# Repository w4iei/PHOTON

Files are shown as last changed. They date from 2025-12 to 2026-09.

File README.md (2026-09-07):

# PHOTON
**PHysical Optical Tracking of Notes system**

PHOTON is a modular, open-source optical sensing platform for high-resolution key and motion tracking. Each module combines a KiCad-designed linear array of **VCNT2025X01** reflective sensors, **TLA2518** high-speed SPI ADCs, and an **RP2350** MCU. Modules can run standalone over USB-C or daisy-chain over RS-485 for large sensing surfaces.

## Paper
[PHOTON: Non-Invasive Optical Tracking of Key-Lever Motion in Historical Keyboard Instruments](https://arxiv.org/abs/2604.21682) (arXiv:2604.21682)

## Demo
<a href="https://www.youtube.com/playlist?list=PLzCRAfVYuoWGEnWNO6l8IuFvaSUI3v1Gd">
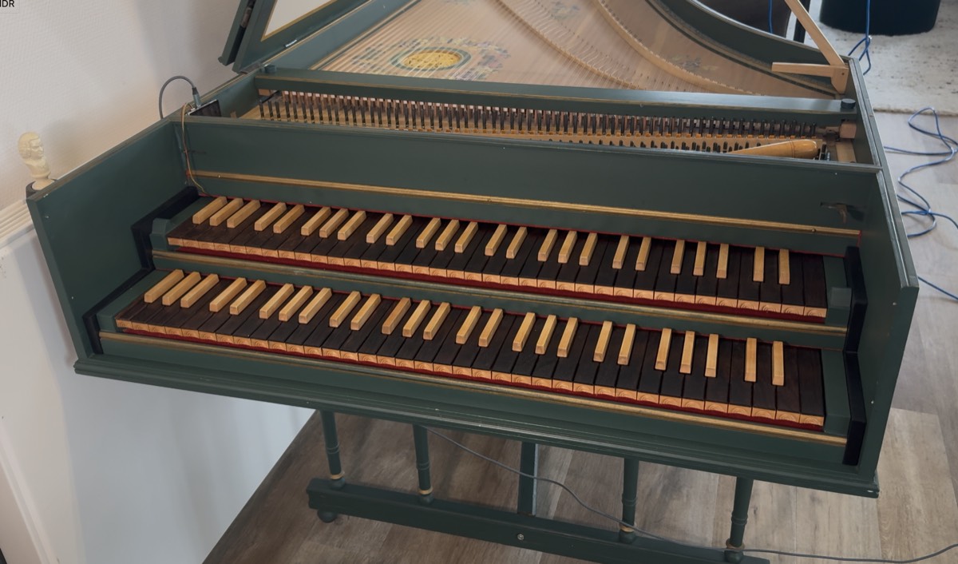
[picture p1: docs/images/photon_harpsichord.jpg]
PHOTON demo playlist thumbnail
  
</a>

[Watch the PHOTON demo playlist on YouTube](https://www.youtube.com/playlist?list=PLzCRAfVYuoWGEnWNO6l8IuFvaSUI3v1Gd)

## Highlights
- **Sensors:** [VCNT2025X01](https://www.vishay.com/en/product/84895/) reflective array with per-sensor enable lines
- **Digitization:** [TLA2518](https://www.ti.com/product/TLA2518) SPI ADCs for high-speed readout
- **MCU:** [RP2350](https://www.raspberrypi.com/products/rp2350/) (dual-core Cortex-M33)
- **Comms:** [THVD1424](https://www.ti.com/product/THVD1424) RS-485 transceivers; firmware-controlled termination on the main board (idle-bus failsafe via the transceiver's internal receiver thresholds on this hardware rev)
- **I/O:** USB-C (power + USB-MIDI/CDC), QWIIC/I2C expansion
- **Black box:** a microSD card in the bridge records every performance as Standard MIDI Files, host or no host (see [firmware/README.md](firmware/README.md#microsd-recorder-bridge))
- **Open:** KiCad 9 hardware, native C firmware (Pico SDK)

## Performance
- Full 31-sensor board sweep in ~770 µs — ~1.3 kHz open-loop; production runs two-phase, pace-throttled at 600 Hz (half the peak emitter current, 1.67 ms velocity quantisation) with µs-resolution velocity timing either way
- RS-485 bus at 4 Mbaud, bridge-polled: zero collisions by construction, zero event loss across ~500k sequence-accounted bench events, sub-ms worst-case event latency with four boards on the bus

## Firmware (native C, dual-core)
CircuitPython support is gone: it capped the system at a ~250 Hz single-core scan loop and could not prevent bus collisions, so it was retired for performance. The native Pico-SDK firmware ships as **one UF2 for every board** — each board probes its own hardware at boot and becomes a sensor node or the main bridge automatically:
- **Core 1** owns the sensor array: pipelined TLA2518 scanning, running entirely from SRAM so flash and USB activity can never stall a sweep.
- **Core 0** owns everything else: USB (CDC console + USB-MIDI), the RS-485 protocol, calibration and configuration storage.
- **RS-485:** one board is the sole bus master — the main board, or with `master on` the sensor board that carries the USB cable — and polls each sensor board in turn; nodes never transmit unsolicited, and every event batch is acknowledged before a node releases it — collision-free and lossless by design.
- **Scanning:** free-runs open-loop at ~1.3 kHz; throttled to a paced 600 Hz (two-phase mode) for production use.
- **microSD recorder:** a card in the bridge records every performance automatically as Standard MIDI Files, numbered per power-on and per playing episode, with no host, no setup and no clock required.

Build and flash instructions: `firmware/README.md`.

## Architecture (Short)
- Sensor boards: VCNT2025X01 array -> TLA2518 SPI ADCs -> RP2350
- Main board: RP2350 + THVD1424 RS-485 + bias resistors + termination control
- Bus: RS-485 differential, terminated at endpoints

## Hardware
See `hardware/README.md` for board-specific notes and layout sources.

## Getting Started
**Hardware**
- PHOTON module(s)
- USB-C cable
- JST-SH 4-pin cables (1.0 mm pitch, "reverse double head" type as used by Qwiic; see `hardware/README.md`)
- Mounting screws: **M2.3 x 5 mm pan head**, through the boards' 2.7 mm (M2.5) holes; at least three per board over 250 mm long, one at each end and one near the middle (see [hardware/README.md](hardware/README.md#design-recommendations))

**Software**
- PHOTON firmware UF2 (build from `firmware/`, see `firmware/README.md`)
- KiCad 9 (download: https://www.kicad.org/download/)
- DAW or MIDI viewer (Pianoteq, Ableton Live, Reaper, Max/MSP, etc.)

## Build & Flash
1. Hold **USB-BOOT** (or short the USB-BOOT jumper) and connect via USB-C; copy `photon.uf2` to the mounted `RP2350` drive. The same image runs every board.
2. On each sensor board, set its bus id once via the USB console (`setid N`); in an instrument without a main board, also `master on` on each (see `firmware/README.md`).
3. Calibrate. Two ways:
   - **One board, on its own USB console:** `r` clears that board's table and starts learning; play every key it covers once, one at a time, with a normal full stroke; `s` freezes the table and saves it (`x` aborts without saving).
   - **The whole instrument, from the bridge console:** `cal reset` clears every sensor board and starts learning on all of them; play every key on every manual; `cal save` then stores each board's table in its own flash. To redo a single board without disturbing the others, give its bus id: `cal reset <id>`, play that board's keys, `cal save <id>`.

   Calibration and configuration persist in flash and survive reflashing; only `cal reset`, `r` and `setid` clear them.
4. Boards already running PHOTON reflash over USB alone: the `bootsel` console command enters the bootloader without touching the button.

## Notes
- **Double-manual harpsichords** run on a single bus: each manual is a pair of sensor boards mapped to its own MIDI channel (`chmap` console command). The polled protocol eliminates inter-board collisions, so simultaneous playing on both manuals loses nothing.

## Citation
```bibtex
@inproceedings{photon2026,
  title       = {PHOTON: Non-Invasive Optical Tracking of Key-Lever Motion in Historical Keyboard Instruments},
  author      = {Noah Jaffe and John Ashley Burgoyne},
  booktitle   = {Proceedings of the 2026 International Conference on New Interfaces for Musical Expression (NIME)},
  year        = {2026},
  address     = {London, UK},
  note        = {23--26 June 2026. Preprint: arXiv:2604.21682},
  url         = {https://arxiv.org/abs/2604.21682},
}
```

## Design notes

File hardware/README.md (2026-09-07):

## Hardware Overview

KiCad sources for the PHOTON boards. Three designs, all sharing one symbol
library (`PHOTON.kicad_sym`, `PHOTON_Modified.kicad_sym`) and one footprint
library (`photon_common.pretty`) at the top of `hardware/kicad/`.

| Board | Size | Role |
|---|---|---|
| `002_sensor_board` | 413.7 x 35.0 mm | Sensor node — 31 optical sensors |
| `001d_..._low_profile` | 54.0 x 41.7 mm | Bridge, low cost / low profile |
| `001_main_controller_board` | 69.0 x 49.9 mm | Bridge, full size, touchscreen |

### Datasheets

- [VCNT2025X01](https://www.vishay.com/docs/84895/vcnt2025x01.pdf) — reflective optical sensor (Vishay)
- [TLA2518](https://www.ti.com/lit/ds/symlink/tla2518.pdf) — 8-channel SPI ADC (TI)
- [RP2350 / RP2354](https://datasheets.raspberrypi.com/rp2350/rp2350-datasheet.pdf) — microcontroller (Raspberry Pi); the RP2354 is the RP2350 with 2 MB of flash in the package, same datasheet
- [THVD1424](https://www.ti.com/lit/ds/symlink/thvd1424.pdf) — RS-485 transceiver (TI)
- [TPS62A0569A](https://www.ti.com/lit/gpn/tps62a0569a) — buck regulator (TI)
- [Waveshare 2.8" capacitive touch LCD](https://www.waveshare.com/wiki/2.8inch_Capacitive_Touch_LCD) — ST7789T3 display controller, CST328 touch controller; the reference panel for the 001 bridge

## 002 — Sensor node

31 VCNT2025X01 reflective sensors on a **13.3 mm pitch**, read by eight
TLA2518 8-channel ADCs, scanned by an RP2354. One board covers 31 notes, so
**two boards cover a 56-62 key manual** and four cover a double-manual
instrument.

This example is dimensioned for 13.3 mm, measured at either sensing point —
under the **jack** or under the **key lever**. **Every harpsichord is
different.** Measure your own instrument and validate the fit before ordering
boards.

**The board is designed to be shortened.** Mousebite perforations
(`photon_common:mousebite_34mm`) let you snap or cut sections off with
scissors to fit a shorter compass or an awkward case. Signals are routed
*through* the mousebite regions — sensor enables, ADC inputs, VCC and GND —
so a cut section stays functional up to the break.

## 001D — Bridge, low profile

RP2354 (2 MB internal flash), USB-C to the host, THVD1424 to the sensor bus,
microSD. Minimal part count and the smallest board that does the job. This is
the default bridge.

## 001 — Bridge, full size

Same role, plus an **18-pin 0.5 mm FPC connector (FH34SRJ-18S-0.5SH)** for a
touchscreen — the reference panel is a Waveshare 2.8" 240x320, ST7789T3 over
SPI with a CST328 capacitive touch controller over I2C. Carries RP2350 with
external W25Q128 flash and an APS6404L PSRAM, plus one VCNT2025X01 fitted for
bench work. Use this only if the application wants a local display.

## No bridge at all

**Neither bridge board is required.** A sensor node has its own USB-C
receptacle, so running a USB-C cable from one sensor board straight to the
host is a complete system. Several sensor boards work the same way once each
has `master on` saved: the board carrying the USB cable runs the bus for the
others (see
[firmware/README.md](../firmware/README.md#without-a-main-controller-board)).
The bridge exists for installations that want the host connection somewhere
other than at a sensor board, or that want a touchscreen and the microSD
recorder.

In practice a bridge is often the easier build. Once the sensor boards are
mounted under the keys or jacks, their USB-C receptacles tend to end up
somewhere a USB-C plug cannot reach or cannot exit the case from. The
inter-board lead is a thin 4-pin JST-SH cable that bends around anything, so
the bridge — and with it the USB-C socket and the microSD slot — can sit
wherever the host connection is convenient. The cable type is specified under
[Power](#power).

## Power

**The RS-485 cable carries 5 V.** Every board — sensor node and bridge alike —
regulates its own 3.3 V locally with a TPS62A0569ADRLR buck. Nets are just
`+5V` and `+3V3`; there is no shared 3.3 V rail between boards.

Inter-board cable, 4-pin JST-SH:

| Pin | Net |
|---|---|
| 1 | GND |
| 2 | +5V |
| 3 | RS485_P |
| 4 | RS485_N |

Use a 4-pin JST-SH (1.0 mm pitch) **"reverse double head"** cable — the same
lead Qwiic uses. Check it before plugging in: hold both plugs facing you in
the same orientation and the top-left wire colour must be the same on both.
[Example listing](https://nl.aliexpress.com/item/1005011775162638.html).

Feedback divider is 0.6 V x (1 + 450k/100k) = 3.3 V.

### One host at a time

Every board's USB-C VBUS sits on the same `+5V` net as its RS-485 connectors,
so the whole chain shares one 5 V rail. Powering any single board over USB
powers every board on the bus — which is what makes an instrument without a
main controller board work (`master on` on every sensor board; the one with
the USB cable runs the bus, see
[firmware/README.md](../firmware/README.md#without-a-main-controller-board)).

**Do not plug two boards into two different computers at once.** That ties both
hosts' 5 V supplies together through the cable. One USB connection to the
system at a time.

### Budget

The whole four-board system draws **~210 mA at 5 V (1.08 W)** while
scanning at the production settings, i.e. roughly 60 mA at 3.3 V per board:
the RP2350 at 150 MHz and eight always-on TLA2518s. Emitters are pulsed at a
few percent duty and cost ~0.1 W per 100 Hz of scan rate; peak current
depends on scan mode (up to four lit at once in two-phase, ~27 mA each, or
eight in parallel).

COUT is **22 uF**, the value the TPS62A0569A datasheet rates highest with a
1 uH inductor. Do not add distributed bulk on +3V3 to "help" — it parallels
COUT and slows the loop, which costs more than the droop it removes.

### Rail sensitivity

The detector is a 4.7 kOhm pull-up to +3V3 with the ADC referenced to the same
rail, so the dark reading is ratiometric and only the LED's forward-voltage
offset leaks through: **~1.9% of signal per 100 mV of droop**, about 130 counts
on a 6,900-count range against a ~62-count noise floor. Keep emitter-correlated
droop under ~50 mV and it is invisible.

Do not filter AVDD away from the pull-up rail — that breaks the cancellation
and roughly triples the sensitivity.

## Building a sensor board for your instrument

1. Update the schematic so the sensor and bank counts match your instrument.
   The final sensor bank is **not** inherited from the four-sensor bank — edit
   it explicitly.
2. Resize the board outline, copper fills and edge cuts.
3. Run the sensor placement script to set the pitch.
4. Route the first bank and the last bank.
5. Replicate that routing across the middle banks, then clean up and verify by
   hand.

Manual review is required after replication and before fabrication.

## Required KiCad plugins

Both via the Plugin and Content Manager:

- **Replicate Layout** — step 5 above
- **Fabrication Toolkit** — generates the `production/` outputs

## Design recommendations

For a board over 250 mm long, use at least **three M2.5 mounting holes** — one at each
end and one near the middle. The centre screw stops the board bowing away from
the mounting surface. Fit them in a line, not both ends first. Putty is fine
for a temporary setup; screws keep the boards from shifting when the
instrument is moved.

Mounting holes use `photon_common:MountingHole_2.7mm_M2.5_Keepout`, which
carries a 7 mm copper keepout so a screw head cannot bridge the top pour to
the bottom pour.

Recommended screws: **M2.3 x 5 mm pan head**
([example listing](https://nl.aliexpress.com/item/33043885403.html)). They
pass through the 2.7 mm holes with clearance.

## Disclaimer

No warranty is provided. Users create circuit boards at their own risk.

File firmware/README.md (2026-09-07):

# PHOTON Native Firmware

Bare-metal C (Pico SDK) firmware for all PHOTON boards. One UF2 for every
board: at boot the firmware probes the
TLA2518 banks; a board with sensors becomes a **sensor node** (core 1 runs the
SRAM-resident scan/event loop), a board without (the main controller board)
becomes the **bus master/bridge** (RS-485 poll cycle + USB-MIDI + console).
An instrument can also be built from sensor boards alone: with `master on`
(saved) on each board, whichever carries the USB cable runs the bus as well,
see [Without a main controller board](#without-a-main-controller-board).

Design details: [docs/architecture/01-native-dual-core-firmware.md](../docs/architecture/01-native-dual-core-firmware.md).

## Build

Requirements: `arm-none-eabi-gcc`, `cmake`, `ninja`, `picotool` ≥ 2.3
(all in Homebrew), and a pico-sdk ≥ 2.1 checkout with the `lib/tinyusb`
submodule initialized:

```bash
git clone --depth 1 --branch 2.3.0 https://github.com/raspberrypi/pico-sdk.git ~/pico-sdk
git -C ~/pico-sdk submodule update --init --depth 1 lib/tinyusb
```

Then:

```bash
cd firmware
cmake -B build -G Ninja        # set -DPICO_SDK_PATH=... if not ~/pico-sdk
ninja -C build                 # -> build/photon.uf2
```

The image is built **copy-to-RAM**: all code executes from SRAM, so core-0
flash writes (calibration saves) can never stall the core-1 scan loop.

## Flash / update

First time (blank board): hold **USB-BOOT** while connecting USB-C (or short
the USB-BOOT jumper), then:

```bash
picotool load -f build/photon.uf2 && picotool reboot
```

or copy `photon.uf2` onto the `RP2350` drive.

Updating a running board never needs the button: type `bootsel` on its
console (or `bootsel <id>` from the bridge for a remote node), then run the
same `picotool` line. `tools/flash_all.sh` does this for the whole system.

**Everything configured survives a reflash**: node id, calibration, disabled
masks, channel map, scan mode/rate, velocity range. Config lives in two
sectors above the program image, which a UF2 drop does not touch, and the
loader accepts records written by any older build (fields are append-only,
so an old record is a prefix of the current one; missing fields take
defaults). A migrated board says so once in its boot banner and `id`, then
rewrites the record in the current layout. Check with `disable` (no
argument, lists the masks), `chmap` and `velrange` after flashing. The only
way to lose settings is `cal reset` / `setid`.

## Validated settings

These are the compiled defaults, measured on the four-board two-manual
instrument (2026-09-02). Every one is also a runtime knob, persisted in
flash.

| setting | value | why |
|---|---|---|
| scan mode | 2, two-phase (`mode`) | half the peak emitter current of parallel, 8-key spacing between lit emitters |
| scan rate | 600 Hz (`rate`) | 1.67 ms velocity quantisation, 55 steps across the playing range; sweep 969 µs so ~40% idle |
| emitter settle | 50 µs (`settle`) | more changes nothing measurable |
| SPI bus | 10 MHz | faster clocks lose register writes to the ADC nearest the MCU (near-end reflection on the 414 mm board) |
| velocity map | log in dt, 2.5–25 ms → 50–120, gamma 2 (`velcurve`, `velrange`) | pp / mf-f / ff strikes measure 24.9 / 9.9 / 3.3 ms median, a constant ratio apart; lands them at 54 / 95 / 119 |
| system power | 1.08 W at 5 V, all four boards | measured at the USB meter; mode and rate move it by ~0.1 W per 100 Hz only |

Mode 0 (sequential, ~390 Hz ceiling) lights one emitter at a time and is
kept only as a crosstalk-free benchmarking reference.

One hardware quirk the driver works around: on every TLA2518 fitted, GPIO0
in push-pull mode drives high regardless of GPO_VALUE, so the slot-3
emitter of each bank is switched through its drive-mode bit instead
(`tla2518_emitters()`). Any board flashed with an older build had those
seven emitters on continuously and must be recalibrated after updating.

## Debugging (USB-only)

The current boards have no SWD connector populated, so **the USB console is
the debugging interface**: `stats` (rates, counters, error tallies), `data`/
`minmax` (live sensor state), `trace`/`capture` (per-sweep waveforms, local
or via the bridge with `trace <sensor> <node>`; `tools/listen_for_single_sensor_high_res.py`
captures and plots them on the host), `flashtest`
(core-1 independence proof), plus the `# LOG`/`# NOTE` diagnostic stream. A
sensor node whose array reads all-zero at boot deliberately *suppresses* its
auto-reboot recovery while a console is attached, so the fault can be
inspected instead of loop-rebooting. (If SWD headers are ever soldered on,
standard OpenOCD + Debug Probe works: `openocd -f interface/cmsis-dap.cfg -f
target/rp2350.cfg`.)

## First-time setup per sensor node

Each sensor node needs a bus id once. Connect USB to the node and in a
serial terminal (115200, any rate — CDC):

```
setid 1        # 1..6, unique per node
```

then calibrate at the operating scan rate: `r`, play every key once at normal
force, `s`. The same can be done for the whole bus from the bridge console:
`cal reset` clears every node and starts learning, play every key on every
manual, `cal save` stores each node's table; `cal reset <id>` / `cal save
<id>` target one node and leave the others alone. Id and calibration persist
in flash. On the bridge, `chmap <manual> <channel>` maps each manual (board
pair) to its MIDI channel and `disable <global idx>` masks unpopulated slots
on remote boards.

## Without a main controller board

Two sensor boards make a whole single-manual instrument on their own. Cable
them together on RS-485 (termination switches on at both ends), give them
ids 1 and 2, and on each board's console once:

```
master on      # saved
```

From then on whichever board carries the USB cable runs the bus: about a
second after the host has enumerated it, having heard nothing on the wire,
it starts polling the other board and owns USB-MIDI and the console exactly
as the main controller board would (`id` says `role=master+node`). Its own
keys stay in the note map under its node id, so node 1 is always the low
half of the manual and node 2 the high half, whichever of them has the
cable. The chain is powered through that cable, so moving it power-cycles
both boards and the roles follow it. A `master on` board that does hear a
master (the other board already running the bus, or a main controller board)
stays a plain node. Every bridge-form command works from the master. `data`, `minmax` and `trace` read
the local scanner when the id is omitted or is the board's own, and a remote
node otherwise; the bus-wide forms of `cal`, `mode`, `rate`, `settle`,
`burst` and `test` (no id) reach every node and the local scanner alike;
`disable`/`enable` take global sensor indexes, as on the bridge. `nodes`
lists the board itself first. A sensor board has no microSD socket, so
nothing is recorded in this configuration.

Never put `master on` boards on the same bus as a main controller board: a
board with a USB host would claim the bus while the main board is still
booting, and two masters collide. A master that hears frames from bus
address 0 logs a warning once and counts them in `stats`
(`other_master_frames`). `master off` returns a board to a plain node at
the next power-up.

## Console

Any node's USB-C gives a console (`screen /dev/tty.usbmodem* 115200`).
`help` lists commands: `stats`, `nodes`, `data`, `minmax`, `ping`, `trace`,
`capture`, `burst`, `test` (pseudorandom load), `cal save|reset`, `r`/`s`/`x`
(calibration), `mode`, `rate`, `localmidi`, `master`, `chmap`,
`disable`/`enable`, `velrange`, `velcurve`, `setid`, `log on|off`,
`flashtest`, `sd`, `reboot`, `bootsel`, `id`.
The banner and `id` name the build: git short hash (`-dirty` when `firmware/`
had uncommitted changes) and build time, from a `build_id.h` that CMake
regenerates on every build. `picotool info -a build/photon.uf2`, or a board
sitting in BOOTSEL, shows the same as *version* / *build date*, next to the
repository and klavecimbel.com.
USB-MIDI appears as "PHOTON Node" and emits notes when connected to the
board that runs the bus (the main controller board, or a `master on` sensor
board).

## microSD recorder (bridge)

Put a microSD card in the main controller board's socket and forget about
it: everything the bridge emits as MIDI is also written to the card as
Standard MIDI Files, whether or not a host is listening.

```
0001/            one directory per power-on, created on the first note
0001/0001.MID    one file per playing episode
0001/0002.MID    ... opened on the first note, closed after 30 s of silence
0002/            next power-on
```

- **Numbering is the only bookkeeping.** At mount the bridge scans the root
  for the highest `NNNN` directory and continues from there. Directories are
  created lazily, so idle power cycles leave nothing behind. At 9999
  (directories or files) the recorder stops; it never wraps or overwrites.
- **No clock, no dates.** The board has no RTC and USB carries no time, so
  every file opens with a text meta event `PHOTON power-on +HH:MM:SS.mmm`
  (time since power-on). Inside a file the delta times are exact
  milliseconds (SMPTE 25 fps × 40 ticks division), no tempo map.
- **Power-cut safe.** Every 500 ms the pending events are written and the
  file is re-terminated (end-of-track plus the real track length), so the
  card always holds a complete, valid file. A yanked cable loses at most the
  last half second.
- **A held key delays the close.** The 30 s silence close waits for every
  note to be released, capped at 5 minutes.
- **Cards:** FAT16, FAT32 and exFAT (a 64 GB card as sold). No card, a
  pulled card, or a card error just means a retry every 2 s; nothing
  else on the bridge notices.
- **Latency:** the recorder runs on the bridge's otherwise idle core 1 with
  its own SPI bus (SPI1: SCK 10, MOSI 11, MISO 12, CS 13), so card stalls
  never touch the RS-485 poll cycle or USB-MIDI. Core 0 hands over messages
  through a 512-deep ring (`drops` in the status line counts overflow).

Console: `sd` prints the status line (state, card size and free space,
current directory/file, counters, last error); `sd test [n]` plays a scale
through the MIDI output on a bare bridge so the recorder can be exercised
without sensor boards. A connected terminal also gets one line per state
change (`[SD] recording 0001/0003.MID`, `[SD] closed ...`, `[SD] no card`).

## Bench verification (M1–M5): results

All five milestones passed on the real four-board, two-manual system.

**M1 — SRAM residency.** `flashtest` hammers flash 10× while core 1 scans:
sweep timing stays flat. Verified.

**M2 — scan rate.** Full 31-sensor sweep measured at 766 µs in parallel
mode (mode 1) and 969 µs two-phase (mode 2, the default) at the validated
10 MHz SPI clock; production paces mode 2 at 600 Hz (`rate`), which also
sets the calibration operating point. Verified.

**M3 — transport soak.** Bus tuned to 4 Mbaud / 8 µs DE guards / 700 µs poll
timeout: 3,694 polls/s per node (2 nodes), ~1,540/s (4 nodes). 21-minute soak
at 100 ev/s/node: 246k events, 7.2M frames, crc_err=0 gaps=0 dup=0; 500
ev/s/node × 60 s equally clean. Verified.

**M4 — end-to-end MIDI.** Four boards through the bridge into a DAW, top
manual on channel 3, lower on channel 2 (`chmap`); calibration survives power
cycles. Verified.

**M5 — chord-burst regression (the motivating bug).** Generator loads far
beyond human playing rates show zero sequence-accounted loss; real two-hand
block chords on the instrument: every note present. Verified.

To re-run any of these, the commands above (`flashtest`, `stats`, `test`,
`nodes`, `cal save`) reproduce the numbers from the bridge console alone.

## Host unit tests (no hardware)

```bash
cd firmware/test/host
cmake -B build -G Ninja && ninja -C build && ctest --test-dir build
```

Covers: frame codec (CRC vectors, roundtrip, per-byte corruption rejection,
streaming fuzz with 100% recovery), the event engine (dt math, hysteresis,
range gate, boot-disable), and the microSD recorder (the production
recorder + FatFs on a RAM disk formatted FAT16/FAT32/exFAT: numbering across
power cycles, flush validity, silence close, held-note cap, ring overflow,
card errors, late card insert, the 9999 stop) under ASan/UBSan.

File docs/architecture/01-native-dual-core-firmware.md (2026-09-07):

# PHOTON Native Dual-Core Firmware

Status: **shipped** — this is the production firmware.
Scope: replaces the CircuitPython stack with bare-metal C (Pico SDK) on the existing boards —
sensor board 002 (RS-485 half duplex) and main controller board 001. No hardware changes.

## 1. Why

Two problems drive this rewrite:

1. **Note loss under load (the motivating bug).** With two sensor boards on one manual, fast
   two-hand block chords drop notes. Cause: both nodes push EVENT frames unsolicited on the
   shared half-duplex RS-485 bus; pushes collide with each other and with the host's ACKs, and
   the stop-and-wait retry scheme (12 ms ACK timeout, 4 retries, 64-deep queue) exhausts or
   overflows during bursts. Loss is silent.
2. **Performance ceiling.** CircuitPython owns the main loop on core 0 and core 1 is idle. A full
   ~30-sensor sweep runs ≈250 Hz, and note-velocity timing (`dt`) is quantized to 1 ms — a
   ±12 % velocity error on fast strikes.

Targets for this firmware on unchanged hardware:

| Metric | CircuitPython today | This firmware |
|---|---|---|
| Full-array scan rate | ≈250 Hz | **≥1 kHz** committed (1.4–1.9 kHz estimated) |
| Velocity `dt` resolution | 1 ms | **1 µs** (`time_us_64()`) |
| Event loss under chord bursts | frequent | **zero by construction** (no bus contention) |
| Typical event → bridge latency | 10s of ms under load | **< 1 ms**; ≤ ~2 ms worst-case burst |
| Cores used | 1 | 2 (core 1 = scan, core 0 = comms) |

## 2. Stack decision

**C + Pico SDK (≥ 2.1; developed against the official 2.2.0 tree), bare-metal, no RTOS.**
Chosen over Rust/Embassy after research (Aug 2026): every subsystem here has an official SDK
example (multicore, doorbells, TinyUSB CDC, UART DMA, SPI); the existing custom CircuitPython C
modules (`photon_sensorscan`, `photon_rs485`) already target this SDK underneath, so the proven
scan/event logic ports nearly verbatim; FreeRTOS SMP on RP2350 remains shaky and is unnecessary;
Zephyr lacks core-1 support. Build: `rp2350-arm-s` (Cortex-M33), 150 MHz defaults, `clk_peri`
pinned to 150 MHz for stable UART/SPI dividers.

## 3. Unified firmware image

**One UF2 for every board. No compile-time variants, no CIRCUITPY marker files.**

- **Role by capability probe.** At boot, the firmware attempts a TLA2518 register read on each of
  the 8 bank CS lines. ≥1 bank answers → **sensor role** (core 1 launched). 0 banks → **bridge
  role** (core 1 never launched). The current main controller board therefore runs the same image
  and becomes the bus master/bridge — it is, functionally, the "endpoint node" of the next
  hardware revision one board-rev early. A sensor board with `master on` saved claims the same
  role at runtime, once a USB host has enumerated it and the wire has stayed silent (nodes
  never transmit unsolicited, so silence means no master): it re-addresses itself to 0, polls
  the others, and its own scanner feeds the MIDI mapper directly under its node id. For
  instruments built from sensor boards alone, the role thus follows the USB cable.
- **Bus-master role is probe-derived (or claimed by `master on`) and permanent for the
  session** (the master board runs the shared bus whether or not USB is attached, keeping
  the bus alive). USB attachment
  gates only the host-facing surfaces: MIDI emission checks `tud_midi_mounted()` and the console
  streams only while a CDC terminal is connected — so a charger enables nothing.
- **Identity**: each sensor node stores a `node_id` (1–6) in its flash config block, set once via
  the USB console (`setid N`); on a shared bus there is no topology to derive it from.

## 4. Core split and memory rules

### Core 1 — scan core (sensor role only)
- Runs the TLA2518 scan pipeline (§6) and the event engine (§7), then services the command
  mailbox once per sweep. Nothing else.
- **100 % SRAM-resident**: the whole image is built `copy_to_ram`, so nothing core 1 calls
  ever touches flash/XIP; its stack
  and all data live in SRAM. It never touches flash/XIP, never allocates, and takes no SDK locks.
  Consequence: core-0 flash activity (config commit, USB MSC absent anyway) can never stall a
  sweep, and `multicore_lockout` is satisfied by construction during flash writes (core 1 is
  parked in an SRAM spin, §8).

### Core 0 — everything else
- TinyUSB composite device (CDC console + USB-MIDI), RS-485 transport (§9), protocol handlers
  (§10), config store (§8), and — when in bridge role — velocity mapping + MIDI emission (§11).

### Inter-core plumbing (SPSC rings; never the 4-deep SIO FIFO)

| Channel | Direction | Shape | Purpose |
|---|---|---|---|
| `event_ring` | 1 → 0 | 256 × 12 B records | Note events. Core 0 drains it each loop pass (polled; no doorbell IRQs). 256 = 8× the worst 32-event burst. Overflow is counted and alarmed (should be structurally impossible), never silent. |
| `snapshot` | 1 → 0 | double buffer + seqlock, 31 × {value, min, max} u16 | Latest sweep for DATA/MINMAX responses; core 0 reads without ever blocking core 1. |
| `cmd_mailbox` | 0 → 1 | SPSC, 16 × 16 B | Calibration set, disable mask, scan-mode select (parallel / 2-phase / sequential), trace tap, PARK. Polled once per sweep → ≤1 sweep-period command latency, no IRQs into the scan loop. |

Event record (12 B): `local_idx u8 | state u8 (1=ON,0=OFF) | dt_us u32 | t_us u32 | seq u16` (per-event
sequence for bridge-side loss accounting).
SRAM is uncached on RP2350 → no coherency traps; rings use acquire/release ordering on indices.

## 5. Hardware ground truth (sensor board 002 Rev D)

| Function | Pins |
|---|---|
| RS-485 UART (hardware **UART1**, F11 alt mapping) | TX GPIO22, RX GPIO23 |
| RS-485 DE / termination enable | GPIO24 / GPIO25 |
| "SPI0" bus = hardware **SPI1** | SCLK GPIO10, MOSI GPIO11, MISO GPIO8; CS banks 0–3 = GPIO21, 20, 19, 15 |
| "SPI1" bus = hardware **SPI0** | SCLK GPIO2, MOSI GPIO3, MISO GPIO0; CS banks 4–7 = GPIO1, 7, 5, 6 |

(Bus-name swap: `busio` derived instance from `(sck/8)%2`; native code uses hardware names —
bus A = SPI1/banks 0–3, bus B = SPI0/banks 4–7. Main board: UART1 on GPIO4/5, DE GPIO1, TERM
GPIO18.)

Sensor array: 8 banks × 4 slots of VCNT2025X01; each bank is a TLA2518 whose 4 spare GPIO
channels drive the per-sensor LED emitters (AO3400A, ~27 mA). Slot map per bank: slot 0 → AIN7 /
GPO bit 6, slot 1 → AIN5 / bit 4, slot 2 → AIN3 / bit 2, slot 3 → AIN1 / bit 0.

## 6. Scan pipeline (core 1)

**Unchanged, proven per-sensor sequence** (from `photon_sensorscan`): LED on (`BIT_SET
GPO_VALUE`) → settle 60 µs → `CHANNEL_SEL` write → 1 priming read → 6 OSR dummy reads (OSR = 3,
8× oversample, 16-bit result) → real read → LED off. TLA2518 stays in **manual mode** (auto-
sequence cannot interleave per-sensor GPO writes). SPI 10 MHz mode 0 (the validated bus speed; see firmware/README.md), polled FIFO (frames are
2–3 B; DMA setup would cost more than the transfer). All v1 hot-path debug instrumentation
(~2 100 register reads per sweep) is dropped.

**What changes: banks run concurrently.** The 8 TLA2518s are independent; today they are scanned
strictly sequentially, so the sweep is dominated by 32 × 60 µs of serial settle (~1.9 ms).
Pipelined schedule, per slot-step `s` (0..3), per bus (the two SPI buses run in parallel):

1. LED-on GPO writes for slot `s` on all 4 banks of the bus (~2 µs each).
2. One shared 60 µs settle covers all 4 banks.
3. Read banks sequentially (~30 µs each); as each bank finishes, its slot `s+1` LED is lit so the
   next settle hides under the remaining reads.

Steady state ≈ max(60 µs settle, 4 × 30 µs reads) ≈ 125 µs per step → 4 steps ≈ **500 µs
→ ~1.9 kHz**; without the step-overlap refinement ≈ 720 µs → ~1.4 kHz. Committed: ≥1 kHz.

**Optical crosstalk guard.** Parallel lighting means same-slot emitters in different banks are lit
simultaneously — ≥4 sensor pitches (~55 mm) apart, with the two bus schedules phase-offset by
2 slots so cross-bus lit pairs (bank 3/4 boundary) also keep ≥4 pitches. VCNT2025X01 range is
0.5–3 cm, so 55 mm cross-illumination should be negligible, but it is *measured, not assumed*
(milestone M2): parallel-lit vs strictly-sequential sweeps over identical static geometry; accept
parallel mode iff max per-sensor delta < 1 % of that sensor's calibrated range (and ≪ the
60/40 % hysteresis margin). Runtime-selectable fallbacks (via `cmd_mailbox`, no reflash):
**2-phase** (even banks then odd banks, 8-pitch spacing, ~1 kHz) and **sequential-pipelined**
(one lit LED per bus, settle-bound at 16 × 60 µs ≈ 960 µs ≈ 1 kHz). Even the most conservative
mode meets the target, so crosstalk cannot sink the schedule.

## 7. Event engine (core 1)

Port of the C `process_scan_events` logic, with one deliberate change: min/max learning
runs only during explicit calibration (`r` … `s`), never in performance — continuous
auto-widening let simultaneous adjacent presses pollute a key's range;
sensor participates only when `range ≥ min_event_range`; two-stage strike state machine (arm at
`strike_pct − strike_window_pct`, fire ON at `strike_pct = 60 %` of range, `dt` = time between
the two crossings) and the symmetric release machine (OFF at `release_pct = 40 %`); per-sensor
polarity support. Deployed constants carry over: `strike_pct 60`, `release_pct 40`,
`velocity_window_pct 20`, `strike_window_pct 30`, `min_event_range 170`
(×8 at OSR 3 → 1360), `settle_us 60`, `osr_mode 3`.

**Timebase upgrade:** `supervisor_ticks_ms32()` (1 ms) → `time_us_64()` (1 µs). `dt` widens to
u32 µs in the event record; clamping moves to the mapping stage.

**Intentionally retired legacy features** (not bugs, not verbatim-port omissions): the
`activation_pct` "active" flag (it fed only the legacy trace-slot auto-arming; tracing is now
explicitly commanded via `trace`/`capture`), and the boot auto-disable heuristic
(`boot_disable_above` — shipped *disabled* in the deployed CircuitPython config; the runtime
`disable <idx>` console command replaces the per-node override table for masking bad sensors).

## 8. Config store (flash)

Two 4 KB A/B sectors at the top of the 16 MB W25Q128, each: `magic | version u32 | payload |
crc32`. Higher valid version wins; corrupt/blank → compiled defaults + "uncalibrated" console
warning. Payload: `node_id`, per-sensor calibration (min/max), disabled-sensor mask, scan mode,
and the **global** note map + velocity parameters (identical on every node so any node can act
as bridge). Commit sequence: core 0 posts `PARK` via `cmd_mailbox` → core 1 acknowledges and
spins in SRAM → core 0 erases/writes (~50–100 ms, bench-time only) → resume. Replaces
JSON-on-CIRCUITPY and `nvm_flags`.

## 9. Transport: frame v2 + master-polled RS-485

### 9.1 Frame format v2

```
A5 5A | type u8 | flags u8 | src u8 | dst u8 | len u8 (≤128) | seq u16 | hdr_crc8
      | payload[len] | crc32 (LE, reflected IEEE — covers type..payload)
```

`flags`: bit0 DIR (reserved), bit1 PRIO_EVENT, bits 4–7 protocol version = 2.
Fixes two v1 defects: **CRC32 now covers the header** (v1 covered payload only, so a corrupted
`len`/`type` could pass), and **`hdr_crc8`** (poly 0x07, over `type..seq`) gives O(n)
byte-at-a-time resynchronization (v1 rescanned the buffer per frame — O(n²) on garbage).
Overhead 14 B; single-event frame 24 B; max payload 128 B (DATA_RESP needs 124 B).

### 9.2 Bus discipline: bridge is sole master — collisions eliminated in software

Sensor nodes **never transmit unsolicited**. The bridge runs a continuous cycle:

- `EVT_POLL{dst=n}` (16 B: header + 2-byte ack, see below) → node `n` replies one `EVT_BATCH`
  frame with 0–10 event records (12 B each incl. per-event seq; 128-byte payload cap) drained
  from its `event_ring` (empty reply = 16 B).
- Bench-tuned to 4 Mbaud (exact divisor at clk_peri = 150 MHz) with 8 µs DE guard bands: one
  empty poll+reply ≈ 135 µs → measured **3,694 polls/s per node** with 2 nodes, ~1,540/s with 4
  → **typical event latency < 1 ms** in every configuration. Worst case, 32 events queued on one
  node clears in 3 polls; a saturated 61-note "doomsday" chord across 2 nodes clears in < 3 ms.
- Zero collisions by construction (exactly one transmitter at any time). Line noise is handled by
  per-poll retry (2×, then skip-and-log); CRC-fail/timeout/retry counters are visible via STATS.
  EVENT_ACK from v1 is deleted; instead each EVT_POLL carries the poll-seq of the last batch the
  bridge actually **processed** from that node, and the node releases events from its ring only on
  that explicit ack — a lost reply (even past all retries) just means the same events ride the
  next batch, with the bridge deduplicating by per-event sequence number. No loss window exists.
- Bulk flows (DATA/MINMAX/TRACE/CAL/PING) interleave between poll cycles at lower priority; poll
  replies carry PRIO_EVENT and always win the scheduler.
- The physical bus proved clean at speed: zero CRC/header errors across 7.2 M+ frames at
  4 Mbaud on the bench, including a 21-minute 246k-event soak and 500 ev/s/node load tests.

### 9.3 Driver

`rs485_bus.c` behind the `transport.h` interface. UART1 GPIO22/23, 8N1; DE on GPIO24 with
`PHOTON_DE_GUARD_US` (8 µs) guards driven by a polled DE state machine (timer-scheduled, not
busy-spun); TERM GPIO25 driven as today. TX = DMA per frame, the state machine chains the next
queued frame (v1 blocked the CPU for the whole frame). RX = DMA ring buffer per UART; core 0
polls the write pointer (no per-byte IRQs at 4 Mbaud).

## 10. Protocol flows

| Flow | v2 behaviour |
|---|---|
| `EVT_POLL` / `EVT_BATCH` | §9.2. Batch payload = `epoch u8` (boot epoch, detects node reboots) + `count u8` + count × 12 B records; each record carries its own `seq u16` for loss accounting. |
| `PING`/`PONG` | Bridge discovery: PING ids 1–6 at boot and when a poll target goes silent; PONG carries role+version. |
| `DATA_REQ`/`DATA_RESP` | Addressed; node returns latest sweep snapshot (31 × {value u16, std/min-max}) from the seqlock buffer. |
| `MINMAX_REQ`/`RESP` | Addressed, chunked; feeds calibration display. (v1's host/node `max_payload` mismatch that silently truncated sensors 30–31 is gone — one shared constant.) |
| `STATS_REQ`/`RESP` | Sweep rate (Hz ×10), event/poll counters, CRC-fail, retries, ring high-water marks. |
| `TRACE_START` / `TRACE_DATA` | Node streams a chosen sensor at full sweep rate in bulk-priority chunks; bridge relays to CDC in the **unchanged** `BEGIN_TRACE …` / `t,adc` / `END_TRACE` ASCII contract, so `firmware/tools/listen_for_single_sensor_high_res.py` works unmodified (now at ≥1 kHz). |
| `CAL_SET` / `CAL_COMMIT` / `CAL_ACK` | Broadcast or addressed; values applied to core 1 via mailbox; COMMIT triggers the §8 flash sequence. |
| `TEST_BURST` | Node injects n synthetic events through the full path — the regression instrument for the motivating bug (M3/M5). |

## 11. Bridge role (USB)

- TinyUSB **composite CDC + USB-MIDI**, VID 0x1B4F, new PID 0x0039 (distinct from the
  CircuitPython builds' 0x0038 so host tooling can tell the stacks apart). SDK stdio → CDC only.
- Event path: `EVT_BATCH` → global index = table(node_id, local_idx) → `dt` → velocity
  (8 ms → 127 … 100 ms → 1, curve exponent 2.54 — ported verbatim from `midi_mapping.py`,
  now fed µs-resolution dt) → note arbitration (OR-group per note, as `event_mode.py`) →
  USB-MIDI NoteOn/Off.
- Console commands (any node's CDC, bridge or not): `stats`, `data`, `minmax`, `cal save|reset`,
  `setid N`, `ping N`, `trace N`, `burst N`, `mode parallel|2phase|seq`, `help`.

## 12. Repository layout & port map

```
firmware/
├── CMakeLists.txt, pico_sdk_import.cmake   # PICO_SDK_PATH or fetch; rp2350-arm-s
├── README.md                               # build/flash/debug + bench procedures (M1–M5)
├── src/
│   ├── main.c            # clocks, role probe, core-1 launch, core-0 loop
│   ├── board_config.h    # every pin/baud/depth/threshold (from rs485_system_config.py)
│   ├── core1/  tla2518.{c,h}  scan.{c,h}  events.{c,h}
│   ├── ipc/    rings.{c,h}
│   ├── comms/  frame.{c,h}  transport.h  rs485_bus.{c,h}  protocol.{c,h}
│   ├── usb/    tusb_config.h  usb_descriptors.c  cdc_console.{c,h}  midi_out.{c,h}
│   ├── bridge/ midi_map.{c,h}
│   ├── config/ config_store.{c,h}
│   └── util/   crc32.{c,h}  log.h
└── test/host/            # host-built: deframer fuzz + event-engine tests
```

| Existing source | → Native module | Notes |
|---|---|---|
| `photon_sensorscan` C module (CP fork) | `core1/tla2518.c` + `scan.c` | same register ops; add pipeline; drop debug paths |
| `process_scan_events` (CP fork) | `core1/events.c` | µs timebase; logic verbatim |
| `photon_rs485` C module | `comms/frame.c` + `rs485_bus.c` | v2 frame; do **not** port dead ACK-wait path |
| `rs485_sensor_node/{events,protocol,main}.py` | `comms/protocol.c` + core-0 loop | push+ARQ → polled |
| `usb_console.py`, `trace.py` | `usb/cdc_console.c` | keeps BEGIN_TRACE contract |
| `calibration.py`, `sensor_calibration.py` | `config/config_store.c` | JSON → flash A/B block |
| `rs485_main_host/{event_mode,midi_mapping}.py` | bridge role + `bridge/midi_map.c` | curve/table verbatim |
| `rs485_system_config.py` | `board_config.h` + config defaults | per-node overrides die |

Not ported: `polling_mode.py`, `display.py` (dead), `nvm_flags.py`, marker-file boot logic.
The CircuitPython implementation this replaced is preserved at the `last_circuitpython` git tag.

## 13. Verification

Bench results for the five bring-up milestones (SRAM residency, scan rate,
transport soak, end-to-end MIDI, chord-burst regression) and the validated
production settings are recorded in `firmware/README.md`. Host-built tests
(frame codec fuzz, event engine) live in `firmware/test/host`.

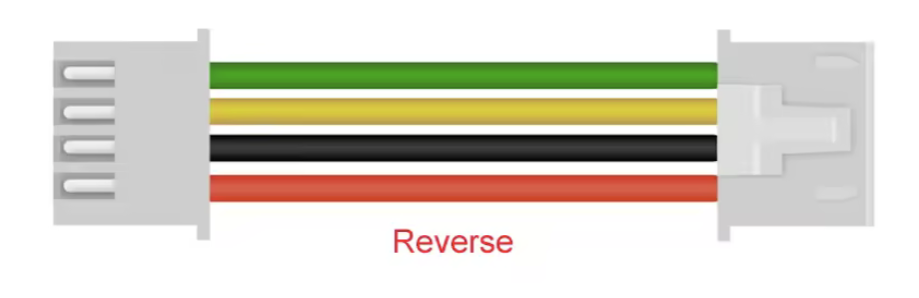
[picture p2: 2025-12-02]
docs/images/reverse.png

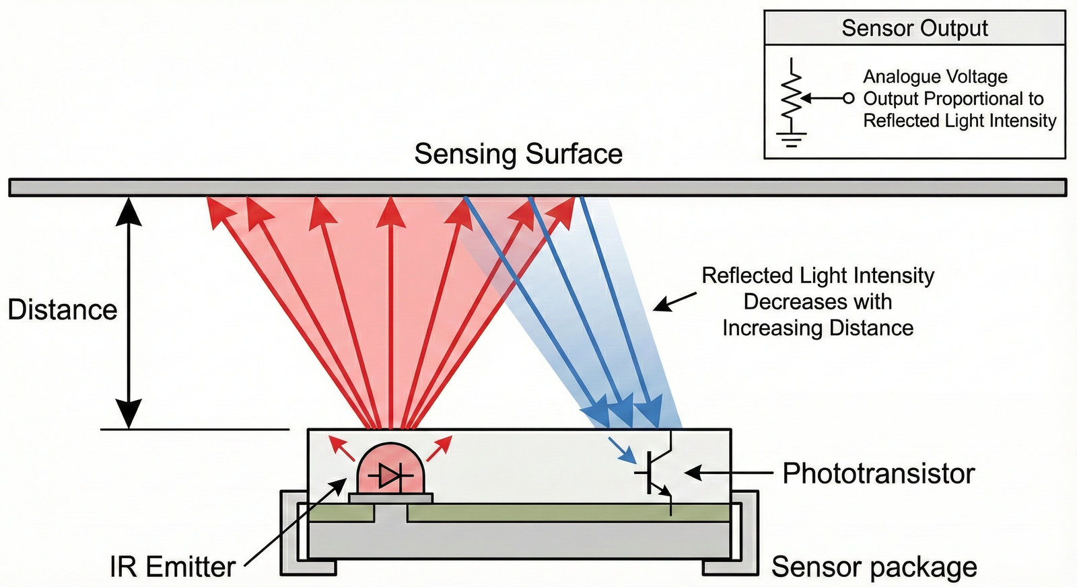
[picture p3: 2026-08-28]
docs/images/reflective_sensor.png

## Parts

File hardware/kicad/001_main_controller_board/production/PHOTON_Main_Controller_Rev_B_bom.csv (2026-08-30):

Designator | Footprint | Quantity | Value | LCSC Part #
C1 | 0805 | 1 | 4.7uF | C1779
C10, C102, C106, C108 | 0402 | 4 | 1uF | C52923
C101, C105, C107, C13, C14, C15, C16, C19, C20, C21, C22, C5, C8, C9 | 0402 | 14 | 100nF | C1525
C17, C18 | 0402 | 2 | 15pF | C1548
C2, C3, C6, C7 | 0402 | 4 | 4.7uF
C4 | 0805 | 1 | 22uF | C45783
C58 | 0402 | 1 | 1nF | C1523
CR1 | SOD-323_L1.8-W1.3-LS2.5-RD | 1 | PTVSHC3D7VU | C20615807
D10, D11, D12 | D_SOD-523 | 3 | D_TVS | C20617921
D2, D3 | 0603 | 2 | LED RED | C2286
FB1 | 0603 | 1 | FerriteBead | C14709
J1 | CONN18x1_FH34SRJ-18S-0.5SH50_HIR | 1 | FH34SRJ-18S-0.5SH(50) | C3169386
J102, J103, J6 | JST_SH_SM04B-SRSS-TB_1x04-1MP_P1.00mm_Horizontal | 3 | JST_SH | C160404
J3 | USB_C_Receptacle_HRO_TYPE-C-31-M-12 | 1 | USB_C_Receptacle_USB2.0 | C165948
J4 | TF-015_corrected | 1 | Micro_SD_Card | C113206
L1 | L_pol_2016 | 1 | 3.3uH | C42411119
L2 | 1008 | 1 | 1uH | C2041556
Q106 | WM02N08F | 1 | WM02N08F | C3030941
R1 | 0402 | 1 | 0Ω
R10, R119, R121, R5, R8 | 0402 | 5 | 10kΩ
R101, R19, R233, R235 | 0402 | 4 | 22Ω
R102, R11, R12, R225, R234, R6 | 0402 | 6 | 33Ω
R103, R17, R4 | 0402 | 3 | 100kΩ
R104, R105 | 0402 | 2 | 200kΩ
R106 | 0402 | 1 | 51kΩ
R120 | 0402 | 1 | 68Ω
R13, R9 | 0402 | 2 | 4.7kΩ
R18, R7 | 0402 | 2 | 1kΩ
R2, R3 | 0402 | 2 | 5.1kΩ | C25905
R236, R237 | 0402 | 2 | 2.2kΩ
SW1 | SW_Push_1P1T_NO_Vertical_Wuerth_434133025816 | 1 | SW_Push | C5504987
U1 | RP2350-QFN-60-1EP_7x7_P0.4mm_EP3.4x3.4mm_ThermalVias | 1 | RP2350_60QFN | C42411118
U101 | SON-8_3x2mm_P0.5mm | 1 | APS6404L-3SQR-ZR | C3040877
U108 | VCNT2025X01_VIS | 1 | VCNT2025X01 | C7431257
U3 | WSON_128JVPIQ_WIN | 1 | W25Q128JVPIQ | C190862
U4 | DQA0010A | 1 | TPD4E05U06DQAR | C138714
U5 | QFN_24RGTR_TEX | 1 | THVD1424RGTR | C5359161
U6 | SOT-563_DRL0006A | 1 | TPS62A0569ADRLR | C53151500
Y1 | Crystal_SMD_3225-4Pin_3.2x2.5mm | 1 | ABM8-272-T3 | C20625731

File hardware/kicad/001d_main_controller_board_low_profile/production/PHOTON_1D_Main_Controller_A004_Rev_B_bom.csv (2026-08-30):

Designator | Footprint | Quantity | Value | LCSC Part #
C1 | 0805 | 1 | 4.7uF | C1779
C103, C105, C13, C14, C15, C16, C19, C20, C21, C5, C8 | 0402 | 11 | 100nF | C1525
C104, C106 | 0402 | 2 | 1uF | C52923
C17, C18 | 0402 | 2 | 15pF | C1548
C2, C3, C6, C7 | 0402 | 4 | 4.7uF
C4 | 0805 | 1 | 22uF | C45783
CR1 | SOD-323_L1.8-W1.3-LS2.5-RD | 1 | PTVSHC3D7VU | C20615807
D10, D11, D12 | D_SOD-523 | 3 | D_TVS | C20617921
D3 | 0603 | 1 | LED RED | C2286
FB1 | 0603 | 1 | FerriteBead | C14709
J101, J102, J103 | JST_SH_SM04B-SRSS-TB_1x04-1MP_P1.00mm_Horizontal | 3 | JST_SH | C160404
J3 | USB_C_Receptacle_HRO_TYPE-C-31-M-12 | 1 | USB_C_Receptacle_USB2.0 | C165948
J4 | TF-015_corrected | 1 | Micro_SD_Card | C113206
L1 | L_pol_2016 | 1 | 3.3uH | C42411119
L2 | 1008 | 1 | 1uH | C2041556
R1 | 0402 | 1 | 0Ω
R101, R19, R233 | 0402 | 3 | 22Ω
R102, R11, R12, R6 | 0402 | 4 | 33Ω
R103 | 0402 | 1 | 100kΩ
R104, R105 | 0402 | 2 | 200kΩ
R106 | 0402 | 1 | 51kΩ
R18, R7 | 0402 | 2 | 1kΩ
R2, R3 | 0402 | 2 | 5.1kΩ | C25905
R236, R237 | 0402 | 2 | 2.2kΩ
R8 | 0402 | 1 | 10kΩ
U1 | RP2350-QFN-60-1EP_7x7_P0.4mm_EP3.4x3.4mm_ThermalVias | 1 | RP2354_60QFN | C41378174
U102 | QFN_24RGTR_TEX | 1 | THVD1424RGTR | C5359161
U4 | DQA0010A | 1 | TPD4E05U06DQAR | C138714
U5 | SOT-563_DRL0006A | 1 | TPS62A0569ADRLR | C53151500
Y1 | Crystal_SMD_3225-4Pin_3.2x2.5mm | 1 | ABM8-272-T3 | C20625731

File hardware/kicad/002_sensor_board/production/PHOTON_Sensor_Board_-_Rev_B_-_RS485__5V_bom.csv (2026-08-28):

Designator | Footprint | Quantity | Value | LCSC Part #
C1 | 0805 | 1 | 4.7uF | C1779
C10, C1301, C1302, C1303, C1801, C1802, C1803, C2301, C2302, C2303, C2801, C2802, C2803, C3301, C3302, C3303, C3801, C3802, C3803, C401, C402, C403, C801, C802, C803 | 0402 | 25 | 1uF
C13, C14, C15, C16, C19, C20, C21, C22, C23, C24, C25, C26, C27, C5, C8, C9 | 0402 | 16 | 100nF
C1304, C1305, C1306, C1307, C1804, C1805, C1806, C1807, C2304, C2305, C2306, C2307, C2804, C2805, C2806, C2807, C3304, C3305, C3306, C3307, C3804, C3805, C3806, C404, C405, C406, C407, C804, C805, C806, C807 | 0402 | 31 | 1nF
C17, C18 | 0402 | 2 | 15pF
C2, C3, C6, C7 | 0402 | 4 | 4.7uF
C4 | 0805 | 1 | 22uF | C45783
CR1 | SOD-323_L1.8-W1.3-LS2.5-RD | 1 | PTVSHC3D7VU | C20615807
D3 | 0603 | 1 | LED RED | C2286
FB1 | 0603 | 1 | FerriteBead | C14709
J1, J2 | JST_SH_SM04B-SRSS-TB_1x04-1MP_P1.00mm_Horizontal | 2 | JST_SH | C160404
J3 | USB_C_Receptacle_HRO_TYPE-C-31-M-12 | 1 | USB_C_Receptacle_USB2.0 | C165948
L1 | L_pol_2016 | 1 | 3.3uH | C42411119
L2 | 1008 | 1 | 1uH | C2041556
Q1001, Q1101, Q1201, Q1401, Q1501, Q1601, Q1701, Q1901, Q2001, Q2101, Q2201, Q2401, Q2501, Q2601, Q2701, Q2901, Q3001, Q301, Q3101, Q3201, Q3401, Q3501, Q3601, Q3701, Q4301, Q4401, Q4501, Q501, Q601, Q701, Q901 | SOT-23 | 31 | AO3400A | C20917
R1 | 0402 | 1 | 0Ω
R1001, R103, R1101, R1201, R1401, R1501, R1601, R1701, R1901, R2001, R2101, R2201, R2401, R2501, R2601, R2701, R2901, R3001, R301, R3101, R3201, R3401, R3501, R3601, R3701, R4301, R4401, R4501, R501, R601, R701, R901 | 0402 | 32 | 100kΩ
R1002, R1102, R1202, R1402, R1502, R1602, R1702, R1902, R2002, R2102, R2202, R2402, R2502, R2602, R2702, R2902, R3002, R302, R3102, R3202, R3402, R3502, R3602, R3702, R4302, R4402, R4502, R502, R602, R702, R902 | 0402 | 31 | 68Ω
R1003, R1103, R1203, R1403, R1503, R1603, R1703, R1903, R2003, R2103, R2203, R2403, R2503, R2603, R2703, R2903, R3003, R303, R3103, R3203, R3403, R3503, R3603, R3703, R4303, R4403, R4503, R503, R603, R703, R903 | 0402 | 31 | 4.7kΩ
R102, R8 | 0402 | 2 | 10kΩ
R104, R105 | 0402 | 2 | 200kΩ
R106 | 0402 | 1 | 51kΩ
R11, R12, R6 | 0402 | 3 | 33Ω
R13, R14, R19, R20 | 0402 | 4 | 22Ω
R18, R7 | 0402 | 2 | 1kΩ
R2, R3 | 0402 | 2 | 5.1kΩ | C25905
R4, R5 | 0402 | 2 | 120Ω
U1 | RP2350-QFN-60-1EP_7x7_P0.4mm_EP3.4x3.4mm_ThermalVias | 1 | RP2354_60QFN | C41378174
U1001, U1101, U1201, U1401, U1501, U1601, U1701, U1901, U2001, U2101, U2201, U2401, U2501, U2601, U2701, U2901, U3001, U301, U3101, U3201, U3401, U3501, U3601, U3701, U4301, U4401, U4501, U501, U601, U701, U901 | VCNT2025X01_VIS | 31 | VCNT2025X01 | C7431257
U1301, U1801, U2301, U2801, U3301, U3801, U401, U801 | WQFN16_RTE_TEX | 8 | TLA2518IRTER | C1855741
U4 | DQA0010A | 1 | TPD4E05U06DQAR | C138714
U5 | QFN_24RGTR_TEX | 1 | THVD1424RGTR | C5359161
U6 | SOT-563_DRL0006A | 1 | TPS62A0569ADRLR | C53151500
Y1 | Crystal_SMD_3225-4Pin_3.2x2.5mm | 1 | ABM8-272-T3 | C20625731

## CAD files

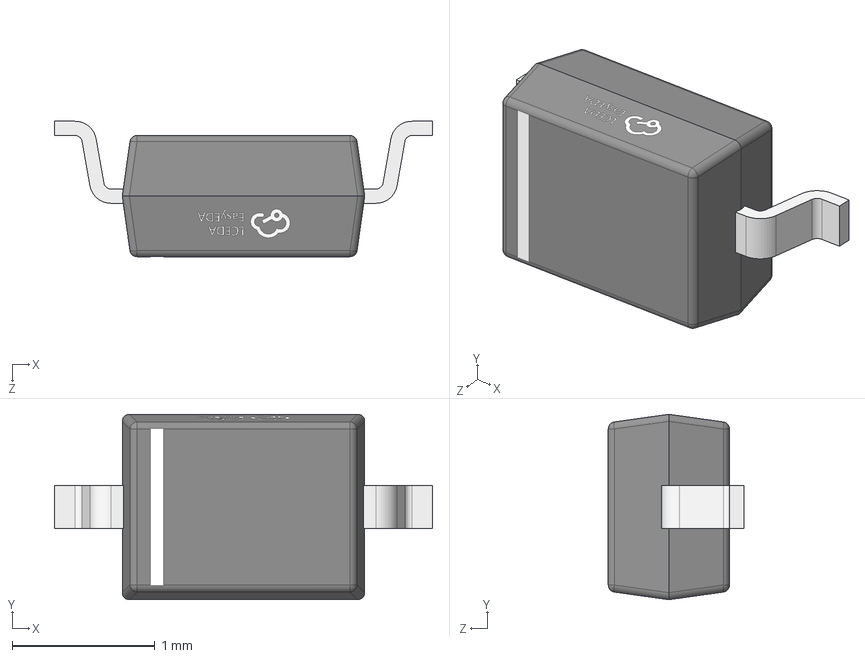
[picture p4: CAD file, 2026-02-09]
hardware/kicad/002_sensor_board/step models/SOD-323_L1.8-W1.3-LS2.5-RD.step
2.65 x 1.30 x 0.95 mm

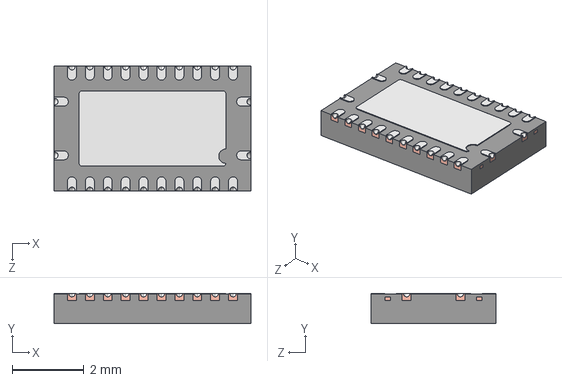
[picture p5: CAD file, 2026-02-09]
hardware/kicad/002_sensor_board/step models/SOT815-1.step
5.50 x 0.85 x 3.50 mm
SOT815-1 LF
SOT815-1 Mold Body

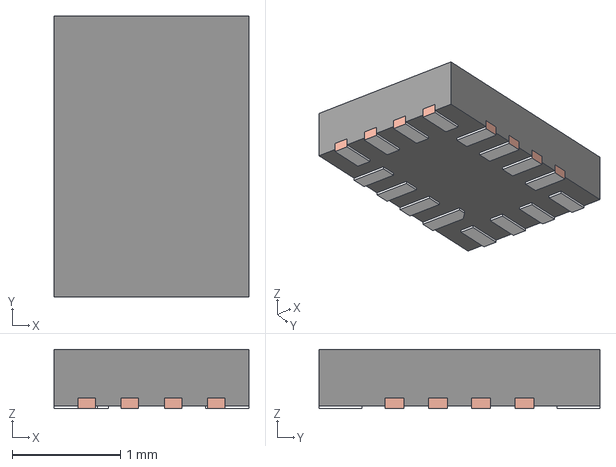
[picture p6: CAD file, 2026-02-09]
hardware/kicad/002_sensor_board/step models/RSV0016A.stp
1.80 x 2.60 x 0.55 mm
BODY-SON1
FRAME-RSV0016A

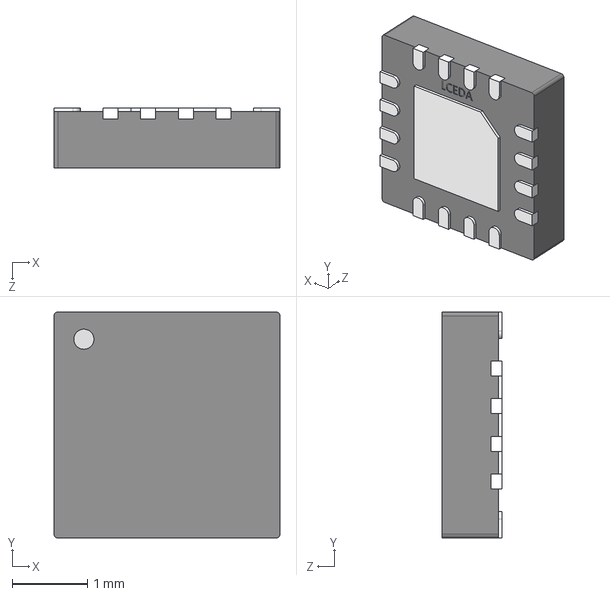
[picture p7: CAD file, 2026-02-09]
hardware/kicad/002_sensor_board/step models/WQFN-16_L3.0-W3.0-P0.50-TL-EP1.7.step
3.00 x 3.00 x 0.8 mm

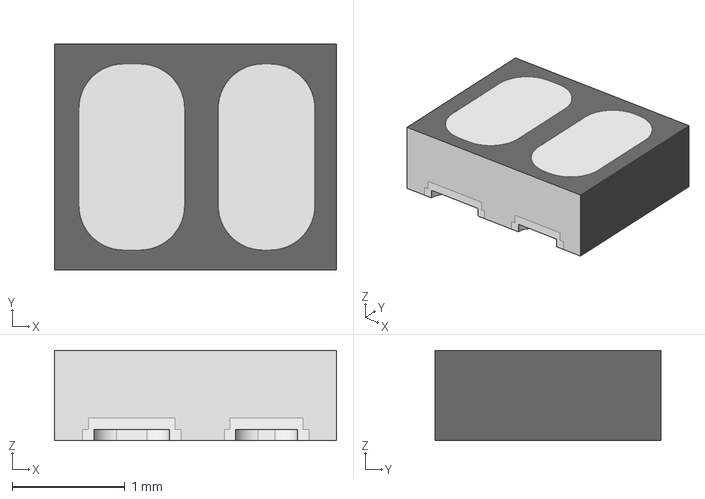
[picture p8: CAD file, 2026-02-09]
hardware/kicad/002_sensor_board/step models/80161_VCNT2020_3D_Models.stp
2.50 x 2.00 x 0.8 mm

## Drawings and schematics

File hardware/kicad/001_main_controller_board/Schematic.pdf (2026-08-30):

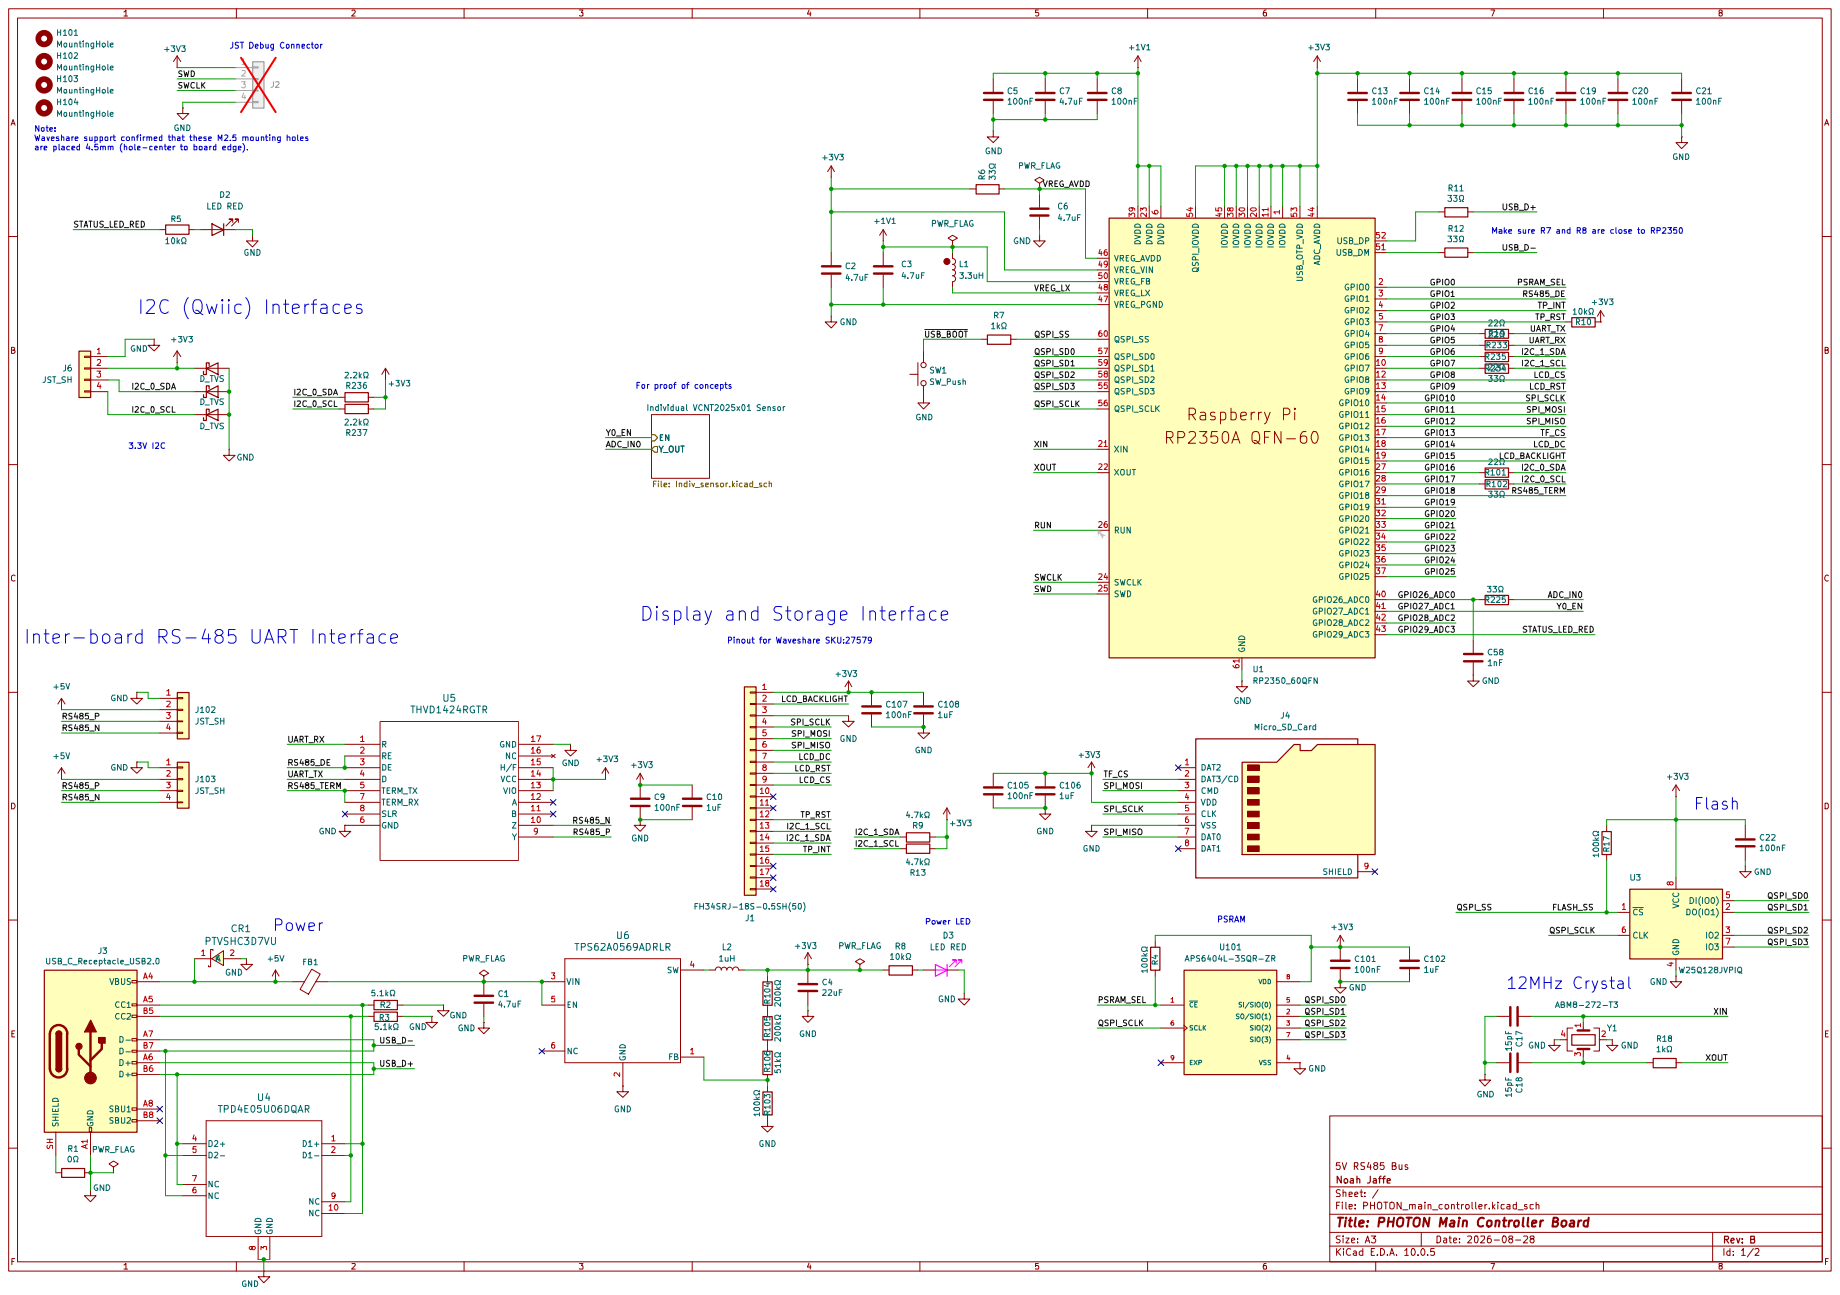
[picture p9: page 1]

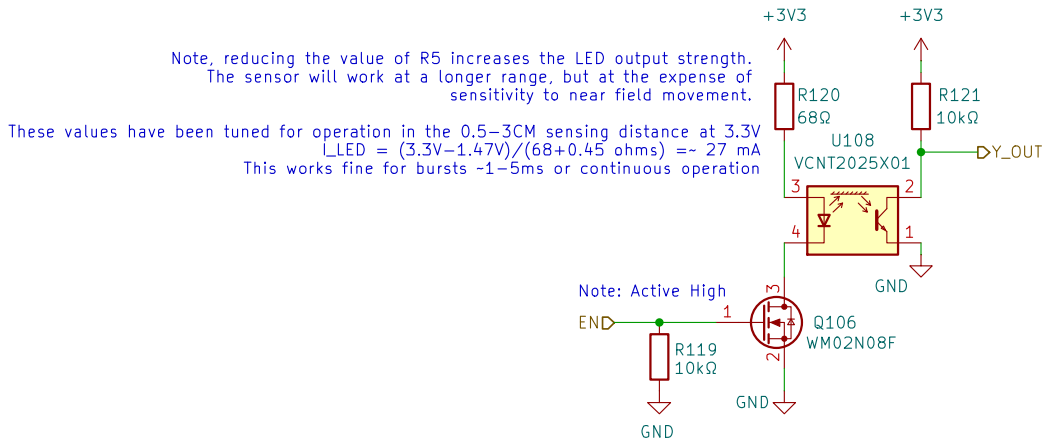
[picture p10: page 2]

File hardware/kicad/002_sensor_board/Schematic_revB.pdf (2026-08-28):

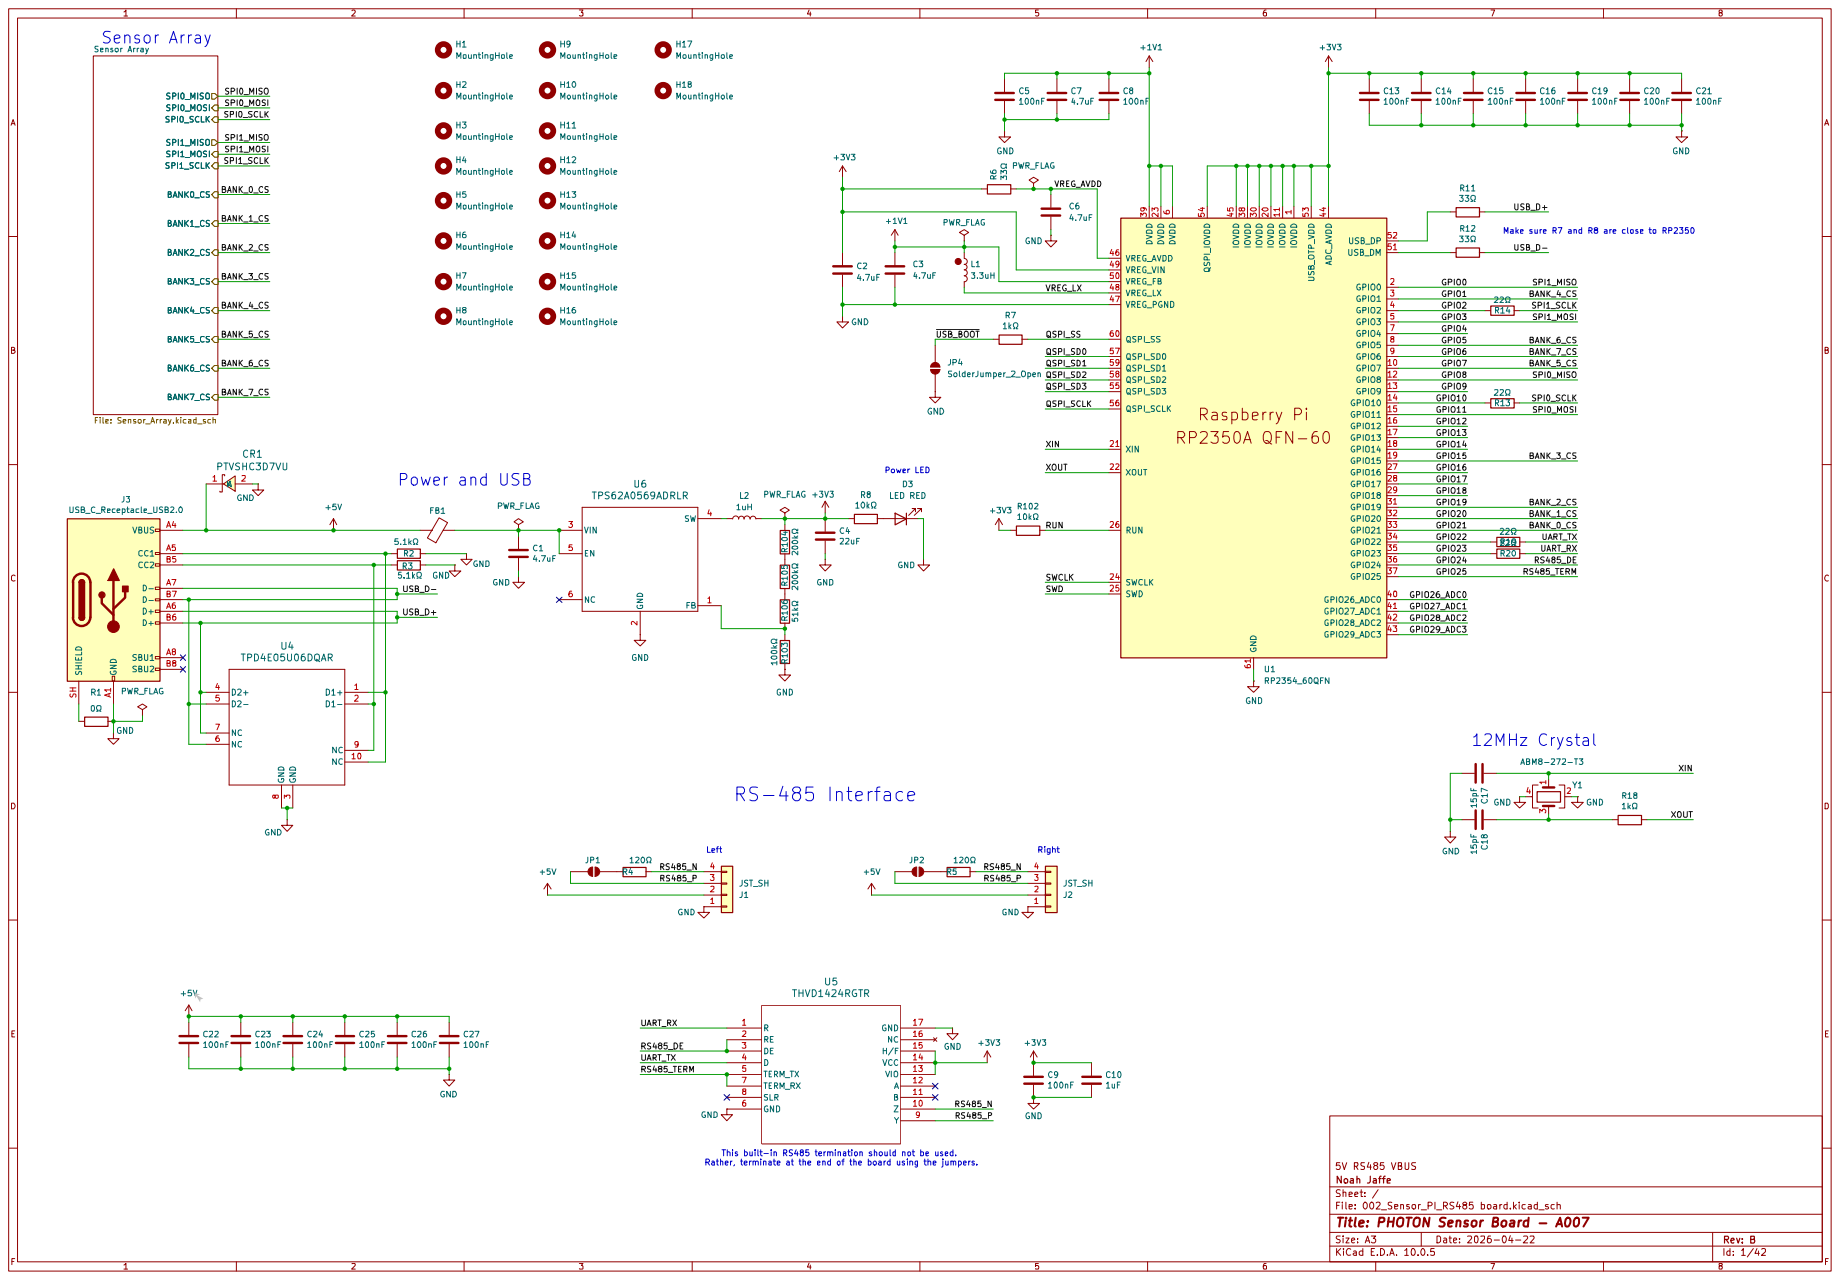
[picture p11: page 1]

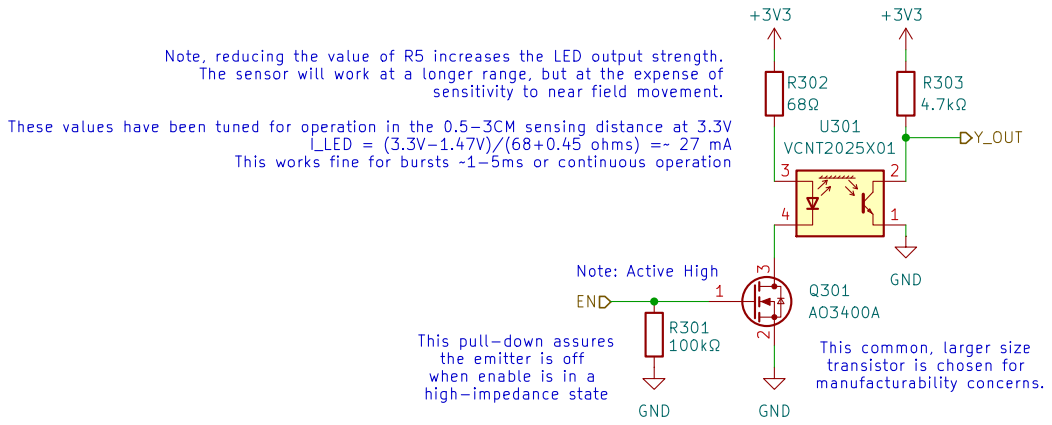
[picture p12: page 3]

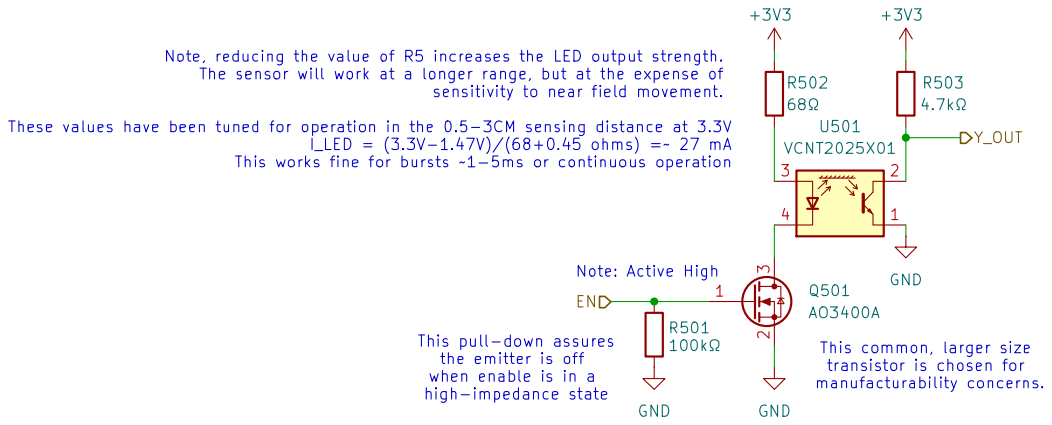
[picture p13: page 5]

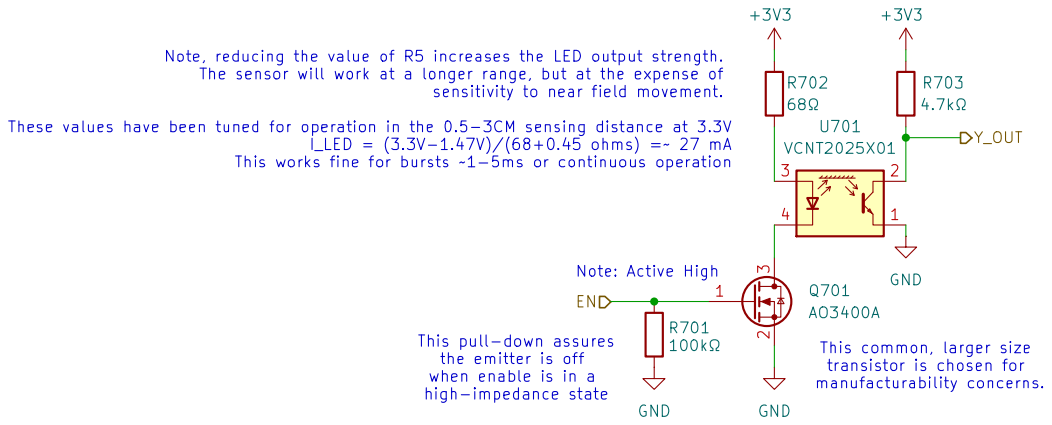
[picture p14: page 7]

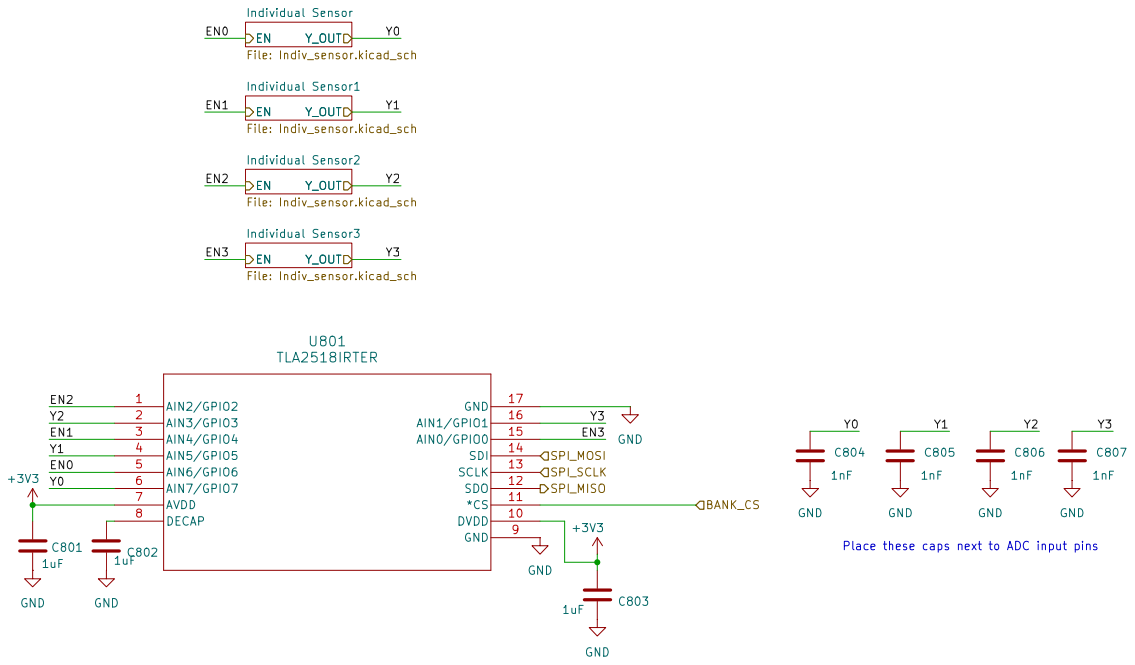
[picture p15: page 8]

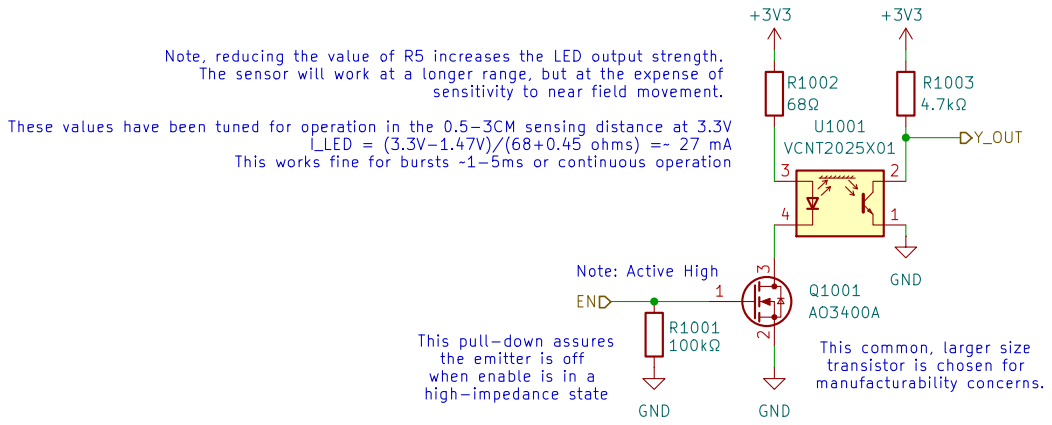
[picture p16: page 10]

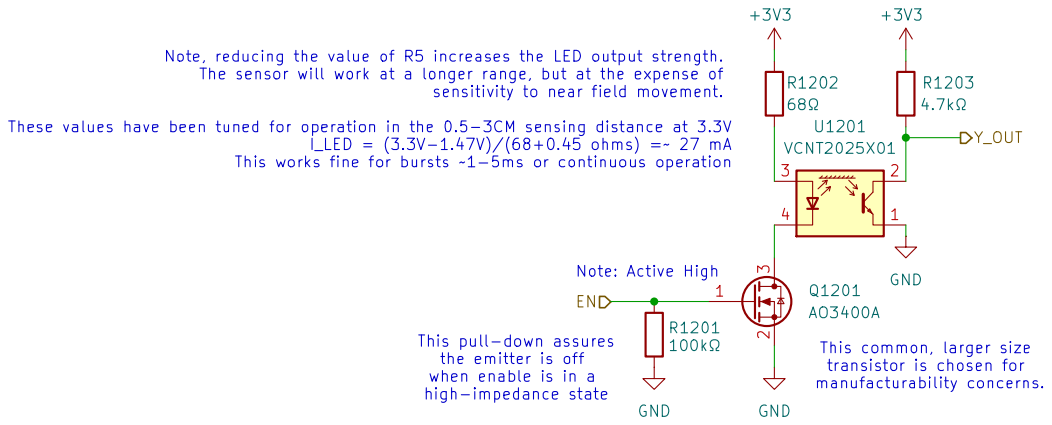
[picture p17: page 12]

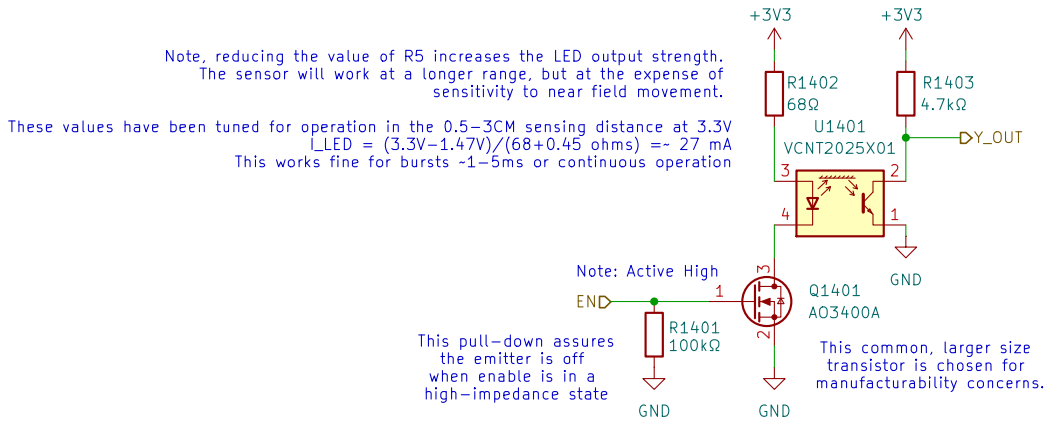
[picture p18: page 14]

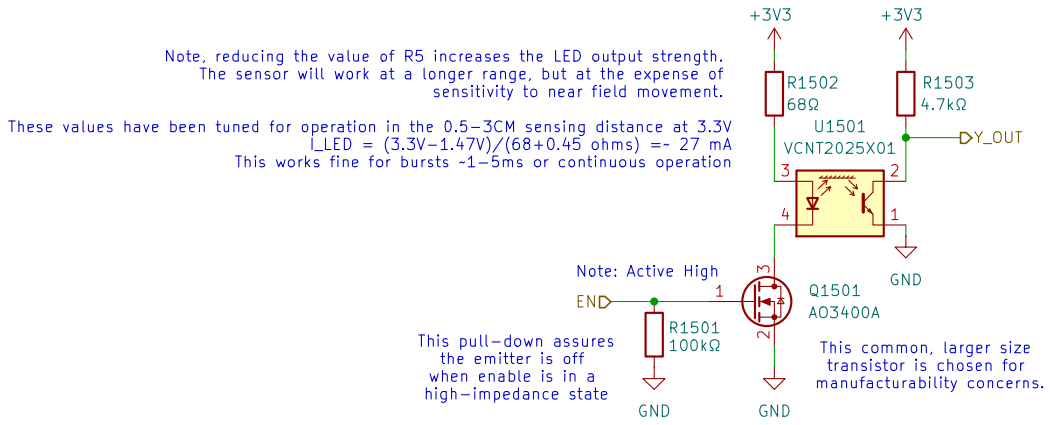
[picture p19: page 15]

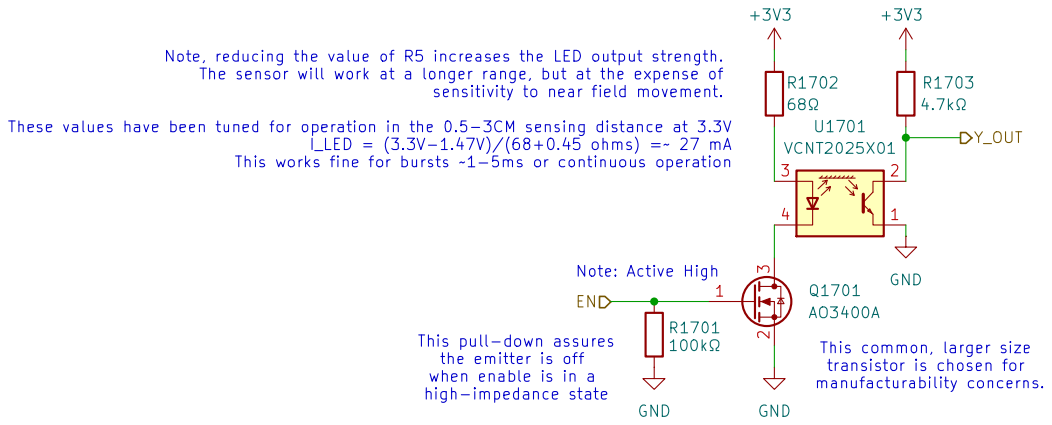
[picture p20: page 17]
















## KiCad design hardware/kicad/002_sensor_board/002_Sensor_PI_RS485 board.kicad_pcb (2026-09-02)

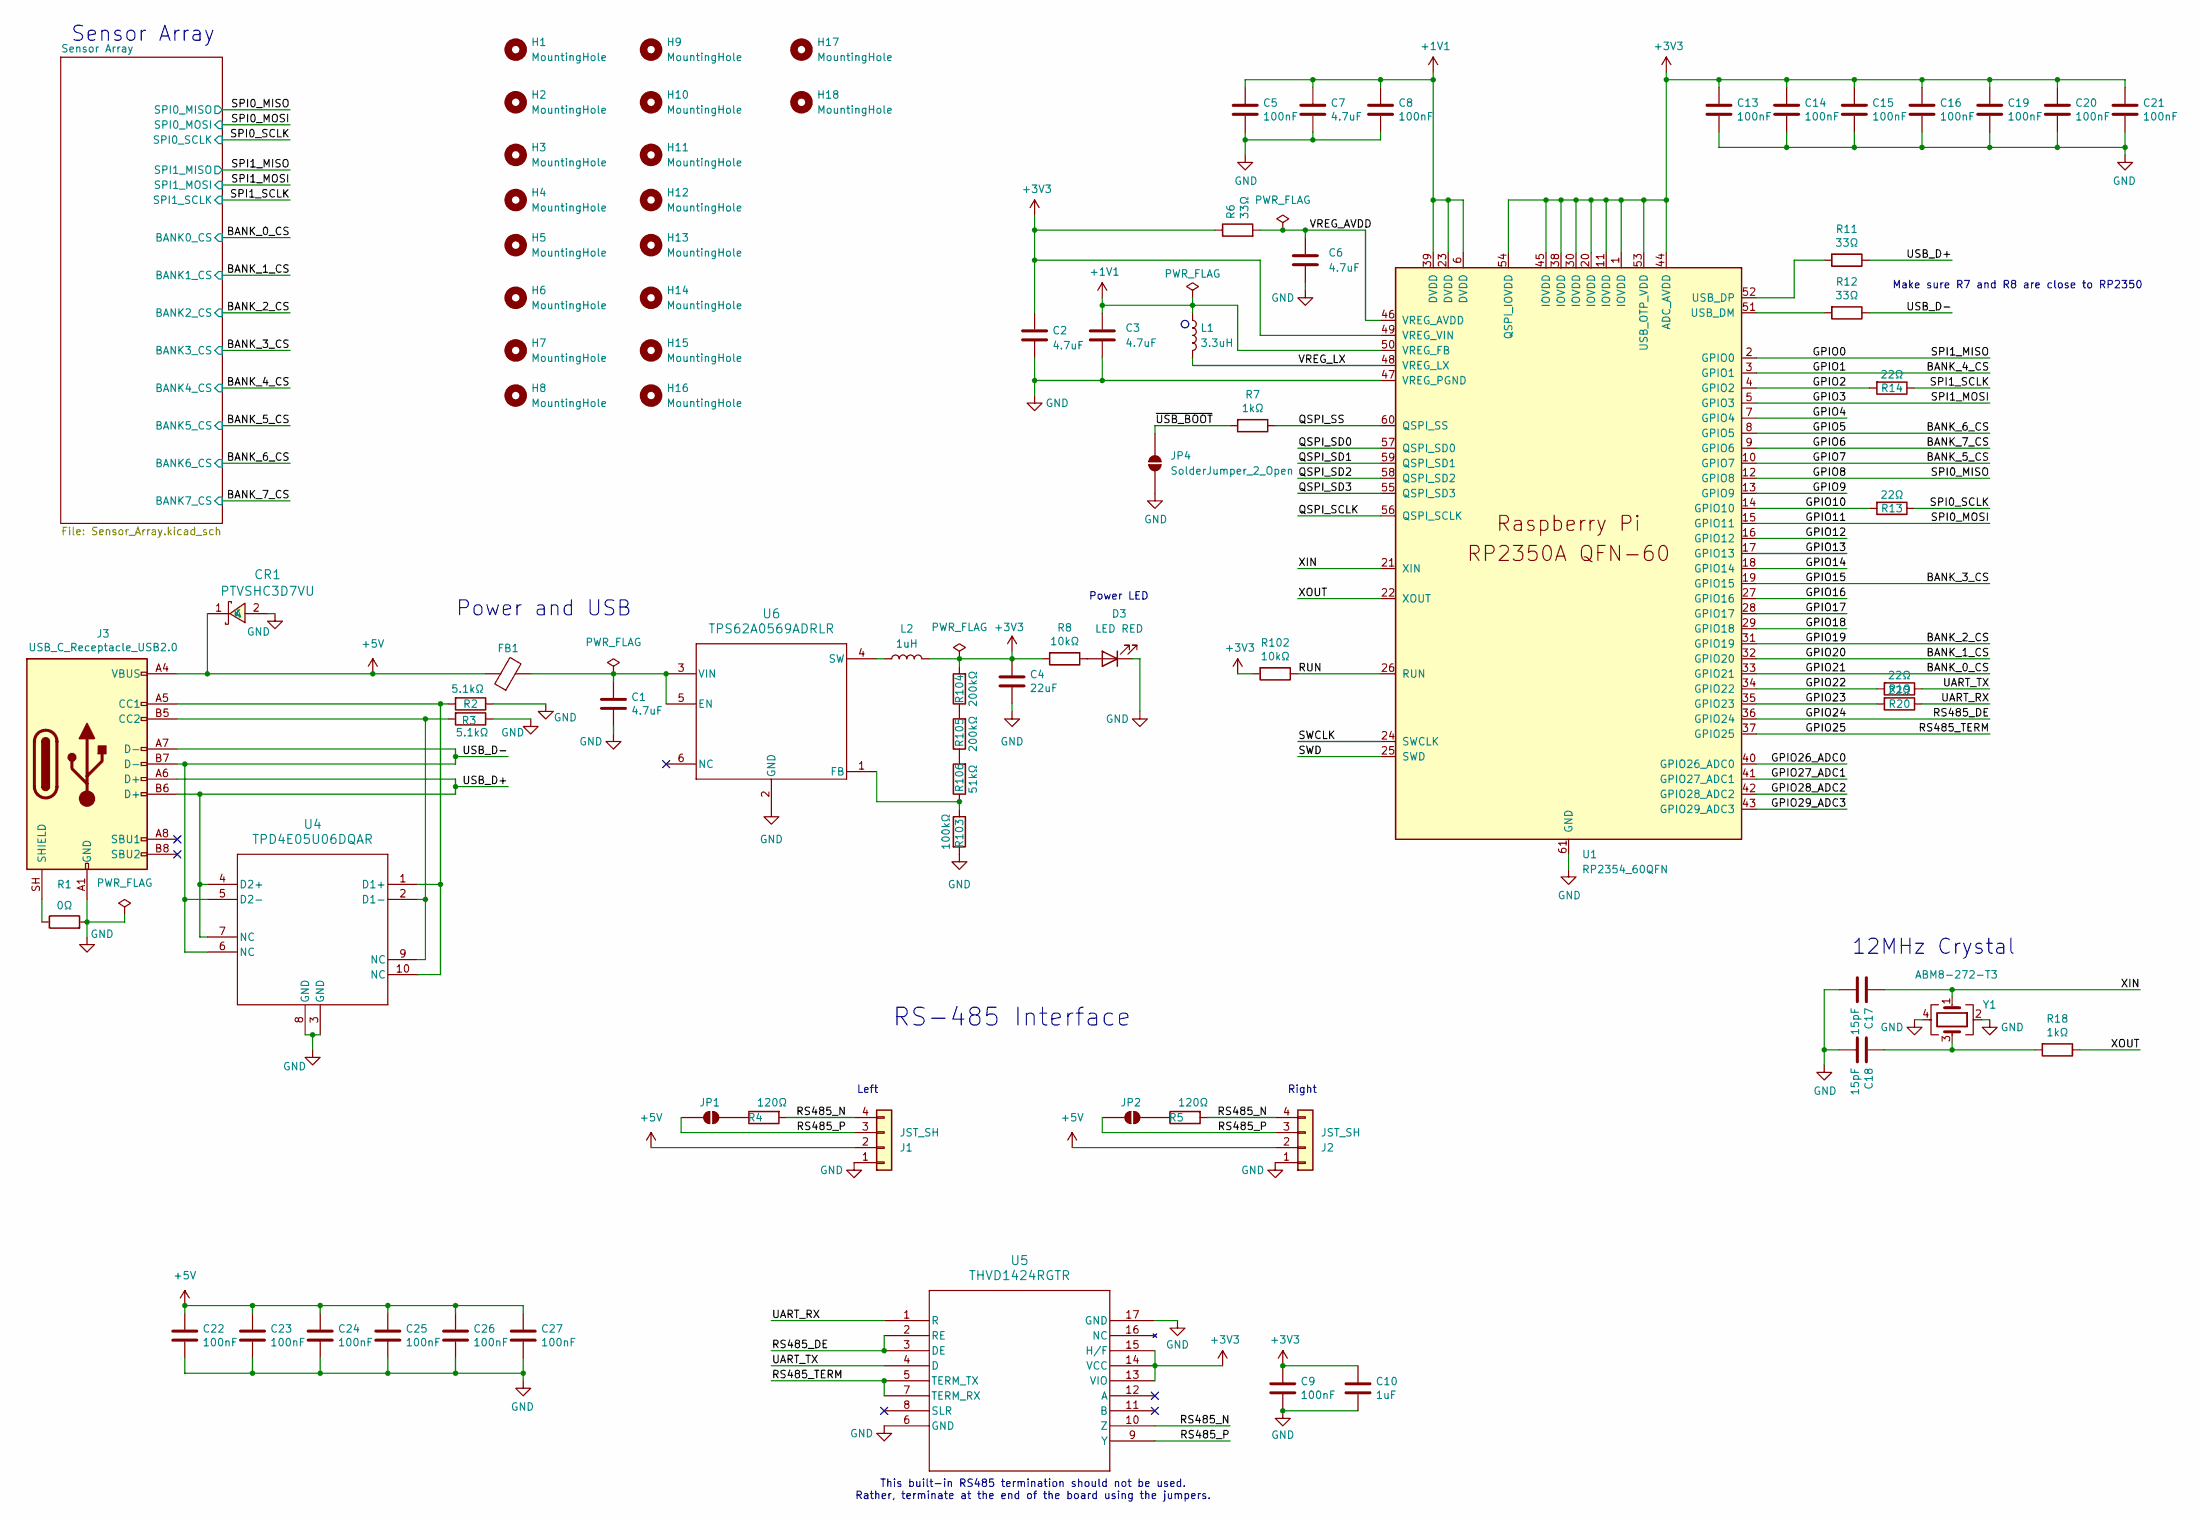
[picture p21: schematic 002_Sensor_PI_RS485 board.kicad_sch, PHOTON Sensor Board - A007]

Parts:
C1: 4.7uF; C_0805_2012Metric; JLCPCB Part # C1779
C2, C3: 4.7uF; C_0402_1005Metric_small_pads; JLCPCB Part # C23733
C4: 22uF; C_0805_2012Metric; JLCPCB Part # C45783
C5, C8, C9, C13, C14, C15, C16, C19, C20, C21, C22, C23, C24, C25, C26, C27: 100nF; C_0402_1005Metric; JLCPCB Part # C1525
C6, C7: 4.7uF; C_0402_1005Metric; JLCPCB Part # C23733
C10: 1uF; C_0402_1005Metric; JLCPCB Part # C52923
C17, C18: 15pF; C_0402_1005Metric; JLCPCB Part # C1548
CR1: PTVSHC3D7VU; SOD-323_L1.8-W1.3-LS2.5-RD; JLCPCB Part # C20615807
D3: LED RED; LED_0603_1608Metric; JLCPCB Part # C2286
FB1: FerriteBead; L_0603_1608Metric; JLCPCB Part # C14709
H1, H2, H3, H4, H5, H6, H7, H8, H9, H10, H11, H12, H13, H14, H15, H16, H17, H18: MountingHole; MountingHole_2.7mm_M2.5_Keepout
J1, J2: JST_SH; JST_SH_SM04B-SRSS-TB_1x04-1MP_P1.00mm_Horizontal; Part Number SM04B-SRSS-TB(LF)(SN); JLCPCB Part # C160404
J3: USB_C_Receptacle_USB2.0; USB_C_Receptacle_HRO_TYPE-C-31-M-12; MPN TYPE-C-31-M-12; JLCPCB Part # C165948
JP1, JP2, JP4: SolderJumper_2_Open; SolderJumper-2_P1.3mm_Open_RoundedPad1.0x1.5mm
L1: 3.3uH; L_pol_2016; JLCPCB Part # C42411119
L2: 1uH; L_1008_2520Metric; Part # C2041556; JLCPCB Part # C2041556
R1: 0Ω; R_0402_1005Metric
R2, R3: 5.1kΩ; R_0402_1005Metric; JLCPCB Part # C25905
R4, R5: 120Ω; R_0402_1005Metric
R6, R11, R12: 33Ω; R_0402_1005Metric
R7, R18: 1kΩ; R_0402_1005Metric
R8, R102: 10kΩ; R_0402_1005Metric
R13, R14, R19, R20: 22Ω; R_0402_1005Metric
R103: 100kΩ; R_0402_1005Metric
R104, R105: 200kΩ; R_0402_1005Metric
R106: 51kΩ; R_0402_1005Metric
U1: RP2354_60QFN; RP2350-QFN-60-1EP_7x7_P0.4mm_EP3.4x3.4mm_ThermalVias; JLCPCB Part # C41378174
U4: TPD4E05U06DQAR; DQA0010A; JLCPCB Part # C138714
U5: THVD1424RGTR; QFN_24RGTR_TEX; JLCPCB Part # C5359161
U6: TPS62A0569ADRLR; SOT-563_DRL0006A; JLCPCB Part # C53151500
Y1: ABM8-272-T3; Crystal_SMD_3225-4Pin_3.2x2.5mm; JLCPCB Part # C20625731

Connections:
+1V1: C3.1, C5.1, C7.1, C8.1, L1.1, U1.6 (DVDD), U1.23 (DVDD), U1.39 (DVDD), U1.50 (VREG_FB)
+3V3: C2.1, C4.1, C9.1, C10.1, C13.1, C14.1, C15.1, C16.1, C19.1, C20.1, C21.1, L2.2, R6.1, R8.2, R102.2, R104.2, U1.1 (IOVDD), U1.11 (IOVDD), U1.20 (IOVDD), U1.30 (IOVDD), U1.38 (IOVDD), U1.44 (ADC_AVDD), U1.45 (IOVDD), U1.49 (VREG_VIN), U1.53 (USB_OTP_VDD), U1.54 (QSPI_IOVDD), U5.13 (VIO), U5.14 (VCC), U5.15 (H/F); also elsewhere on the board
+5V: C22.1, C23.1, C24.1, C25.1, C26.1, C27.1, CR1.1 (K), FB1.1, J1.2, J2.2, J3.A4 (VBUS), J3.A9 (VBUS), J3.B4 (VBUS), J3.B9 (VBUS)
/BANK_0_CS: U1.33 (GPIO21); also elsewhere on the board
/BANK_1_CS: U1.32 (GPIO20); also elsewhere on the board
/BANK_2_CS: U1.31 (GPIO19); also elsewhere on the board
/BANK_3_CS: U1.19 (GPIO15); also elsewhere on the board
/BANK_4_CS: U1.3 (GPIO1); also elsewhere on the board
/BANK_5_CS: U1.10 (GPIO7); also elsewhere on the board
/BANK_6_CS: U1.8 (GPIO5); also elsewhere on the board
/BANK_7_CS: U1.9 (GPIO6); also elsewhere on the board
/GPIO0: U1.2 (GPIO0); also elsewhere on the board
/GPIO2: R14.2, U1.4 (GPIO2)
/GPIO3: U1.5 (GPIO3); also elsewhere on the board
/GPIO4: U1.7 (GPIO4)
/GPIO8: U1.12 (GPIO8); also elsewhere on the board
/GPIO9: U1.13 (GPIO9)
/GPIO10: R13.2, U1.14 (GPIO10)
/GPIO11: U1.15 (GPIO11); also elsewhere on the board
/GPIO12: U1.16 (GPIO12)
/GPIO13: U1.17 (GPIO13)
/GPIO14: U1.18 (GPIO14)
/GPIO16: U1.27 (GPIO16)
/GPIO17: U1.28 (GPIO17)
/GPIO18: U1.29 (GPIO18)
/GPIO22: R19.2, U1.34 (GPIO22)
/GPIO23: R20.2, U1.35 (GPIO23)
/GPIO24: U1.36 (GPIO24), U5.2 (RE), U5.3 (DE)
/GPIO25: U1.37 (GPIO25), U5.5 (TERM_TX), U5.7 (TERM_RX)
/GPIO26_ADC0: U1.40 (GPIO26_ADC0)
/GPIO27_ADC1: U1.41 (GPIO27_ADC1)
/GPIO28_ADC2: U1.42 (GPIO28_ADC2)
/GPIO29_ADC3: U1.43 (GPIO29_ADC3)
/QSPI_SCLK: U1.56 (QSPI_SCLK)
/QSPI_SD0: U1.57 (QSPI_SD0)
/QSPI_SD1: U1.59 (QSPI_SD1)
/QSPI_SD2: U1.58 (QSPI_SD2)
/QSPI_SD3: U1.55 (QSPI_SD3)
/QSPI_SS: R7.1, U1.60 (QSPI_SS)
/RS485_N: J1.4, J2.4, R4.2, R5.2, U5.10 (Z)
/RS485_P: J1.3, J2.3, JP1.1 (A), JP2.1 (A), U5.9 (Y)
/RUN: R102.1, U1.26 (RUN)
/SPI0_SCLK: R13.1; also elsewhere on the board
/SPI1_SCLK: R14.1; also elsewhere on the board
/SWCLK: U1.24 (SWCLK)
/SWD: U1.25 (SWD)
/UART_RX: R20.1, U5.1 (R)
/UART_TX: R19.1, U5.4 (D)
/USB_D+: J3.A6 (D+), J3.B6 (D+), R11.1, U4.4 (D2+), U4.7 (NC)
/USB_D-: J3.A7 (D-), J3.B7 (D-), R12.1, U4.5 (D2-), U4.6 (NC)
/VREG_AVDD: C6.1, R6.2, U1.46 (VREG_AVDD)
/VREG_LX: L1.2, U1.48 (VREG_LX)
/XIN: C17.1, U1.21 (XIN), Y1.1
/XOUT: R18.1, U1.22 (XOUT)
/~USB_BOOT: JP4.2 (B), R7.2
GND: C1.2, C2.2, C3.2, C4.2, C5.2, C6.2, C7.2, C8.2, C9.2, C10.2, C13.2, C14.2, C15.2, C16.2, C17.2, C18.2, C19.2, C20.2, C21.2, C22.2, C23.2, C24.2, C25.2, C26.2, C27.2, CR1.2 (A), D3.1 (K), J1.1, J2.1, J3.A1 (GND), J3.A12 (GND), J3.B1 (GND), J3.B12 (GND), JP4.1 (A), R1.2, R2.1, R3.1, R103.2, U1.47 (VREG_PGND), U1.61 (GND), U4.3 (GND), U4.8 (GND), U5.6 (GND), U5.17 (GND), U6.2 (GND), Y1.2, Y1.4; also elsewhere on the board
unnamed: C18.1, R18.2, Y1.3
unnamed: D3.2 (A), R8.1
unnamed: J3.A5 (CC1), R2.2, U4.1 (D1+), U4.10 (NC)
unnamed: J3.B5 (CC2), R3.2, U4.2 (D1-), U4.9 (NC)
unnamed: J3.SH (SHIELD), R1.1
unnamed: JP1.2 (B), R4.1
unnamed: JP2.2 (B), R5.1
unnamed: R104.1, R105.2
unnamed: R105.1, R106.2
unnamed: R12.2, U1.51 (USB_DM)
unnamed: R11.2, U1.52 (USB_DP)
unnamed: C1.1, FB1.2, U6.3 (VIN), U6.5 (EN)
unnamed: R103.1, R106.1, U6.1 (FB)
unnamed: L2.1, U6.4 (SW)

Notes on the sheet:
RS-485 Interface
Right
Power and USB
This built-in RS485 termination should not be used. Rather, terminate at the end of the board using the jumpers.
12MHz Crystal
Sensor Array
Left
Make sure R7 and R8 are close to RP2350
Power LED

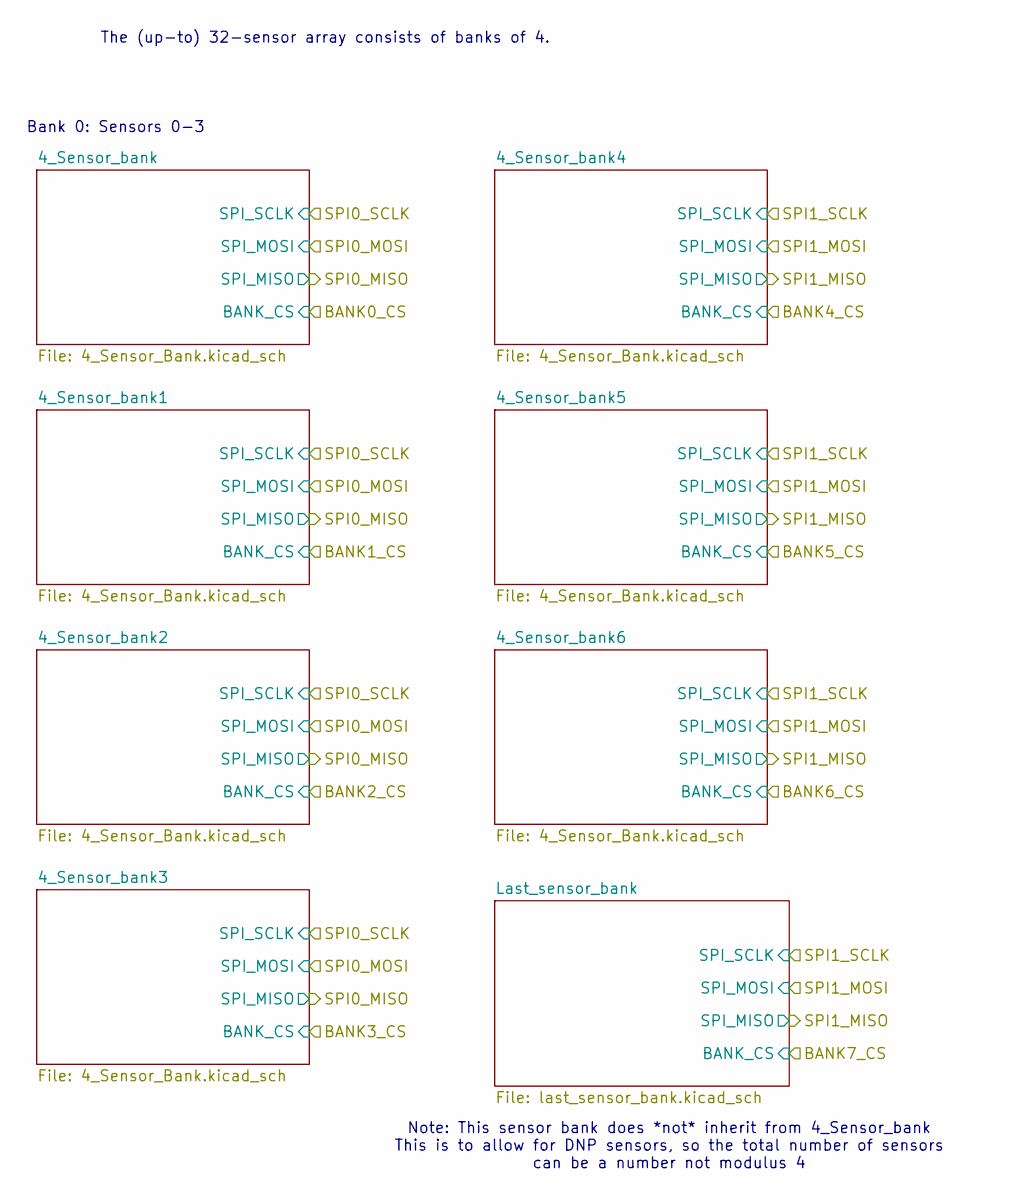
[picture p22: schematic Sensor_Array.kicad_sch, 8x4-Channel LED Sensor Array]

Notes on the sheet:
Note: This sensor bank does *not* inherit from 4_Sensor_bank This is to allow for DNP sensors, so the total number of sensors can be a number not modulus 4
Bank 0: Sensors 0-3
The (up-to) 32-sensor array consists of banks of 4.

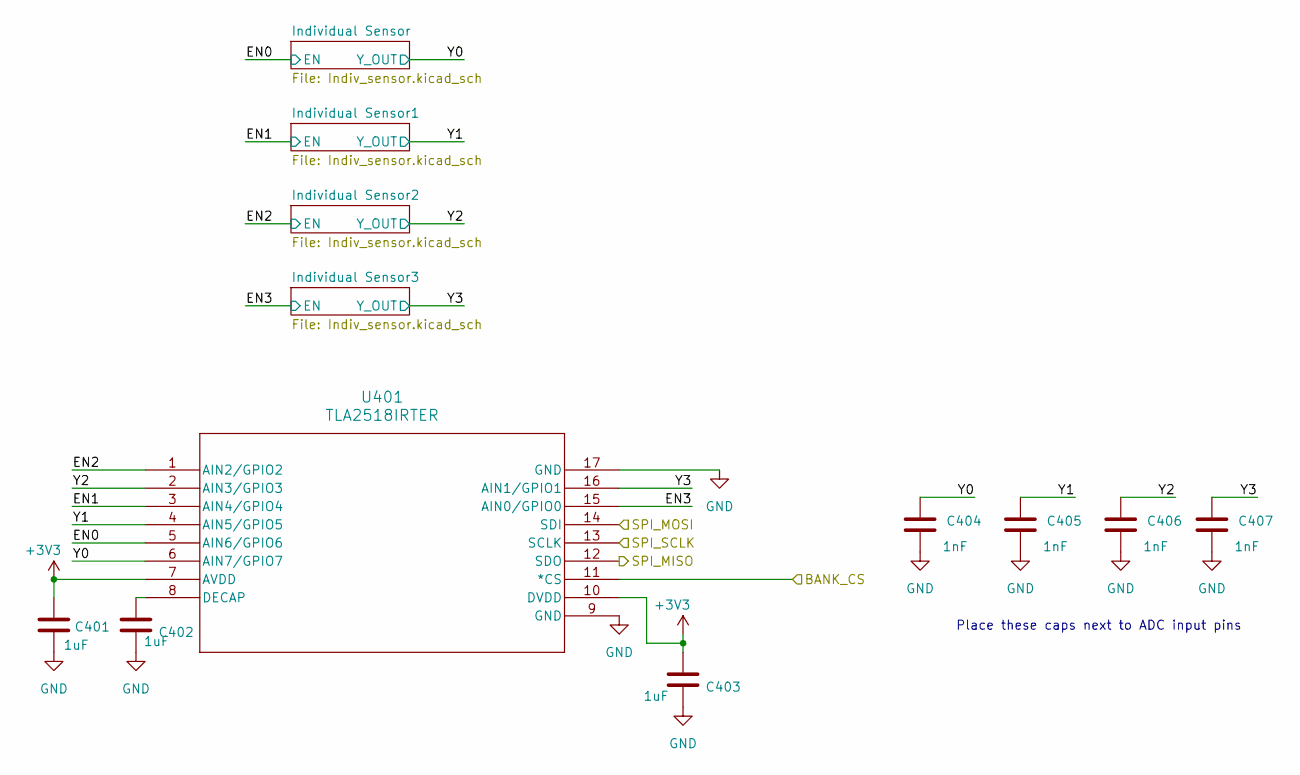
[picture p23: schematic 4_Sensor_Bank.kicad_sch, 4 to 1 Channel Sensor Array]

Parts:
C401, C402, C403: 1uF; C_0402_1005Metric; JLCPCB Part # C52923
C404, C405, C406, C407: 1nF; C_0402_1005Metric; JLCPCB Part # C1523
U401: TLA2518IRTER; WQFN16_RTE_TEX; JLCPCB Part # C1855741

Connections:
+3V3: C401.1, C403.1, U401.7 (AVDD), U401.10 (DVDD); also elsewhere on the board
/BANK_0_CS: U401.11 (*CS); also elsewhere on the board
/GPIO8: U401.12 (SDO); also elsewhere on the board
/GPIO11: U401.14 (SDI); also elsewhere on the board
/SPI0_SCLK: U401.13 (SCLK); also elsewhere on the board
/Sensor Array/4_Sensor_bank/EN0: U401.5 (AIN6/GPIO6); also elsewhere on the board
/Sensor Array/4_Sensor_bank/EN1: U401.3 (AIN4/GPIO4); also elsewhere on the board
/Sensor Array/4_Sensor_bank/EN2: U401.1 (AIN2/GPIO2); also elsewhere on the board
/Sensor Array/4_Sensor_bank/EN3: U401.15 (AIN0/GPIO0); also elsewhere on the board
/Sensor Array/4_Sensor_bank/Y0: C404.1, U401.6 (AIN7/GPIO7); also elsewhere on the board
/Sensor Array/4_Sensor_bank/Y1: C405.1, U401.4 (AIN5/GPIO5); also elsewhere on the board
/Sensor Array/4_Sensor_bank/Y2: C406.1, U401.2 (AIN3/GPIO3); also elsewhere on the board
/Sensor Array/4_Sensor_bank/Y3: C407.1, U401.16 (AIN1/GPIO1); also elsewhere on the board
GND: C401.2, C402.2, C403.2, C404.2, C405.2, C406.2, C407.2, U401.9 (GND), U401.17 (GND); also elsewhere on the board
unnamed: C402.1, U401.8 (DECAP)

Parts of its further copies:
C801, C802, C803, C1301, C1302, C1303, C1801, C1802, C1803, C2301, C2302, C2303, C2801, C2802, C2803, C3301, C3302, C3303: 1uF; C_0402_1005Metric; JLCPCB Part # C52923
C804, C805, C806, C807, C1304, C1305, C1306, C1307, C1804, C1805, C1806, C1807, C2304, C2305, C2306, C2307, C2804, C2805, C2806, C2807, C3304, C3305, C3306, C3307: 1nF; C_0402_1005Metric; JLCPCB Part # C1523
U801, U1301, U1801, U2301, U2801, U3301: TLA2518IRTER; WQFN16_RTE_TEX; JLCPCB Part # C1855741

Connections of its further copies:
+3V3: C801.1, C803.1, C1301.1, C1303.1, C1801.1, C1803.1, C2301.1, C2303.1, C2801.1, C2803.1, C3301.1, C3303.1, U801.7 (AVDD), U801.10 (DVDD), U1301.7 (AVDD), U1301.10 (DVDD), U1801.7 (AVDD), U1801.10 (DVDD), U2301.7 (AVDD), U2301.10 (DVDD), U2801.7 (AVDD), U2801.10 (DVDD), U3301.7 (AVDD), U3301.10 (DVDD); also elsewhere on the board
/BANK_1_CS: U801.11 (*CS); also elsewhere on the board
/BANK_2_CS: U1301.11 (*CS); also elsewhere on the board
/BANK_3_CS: U1801.11 (*CS); also elsewhere on the board
/BANK_4_CS: U2301.11 (*CS); also elsewhere on the board
/BANK_5_CS: U2801.11 (*CS); also elsewhere on the board
/BANK_6_CS: U3301.11 (*CS); also elsewhere on the board
/GPIO0: U2301.12 (SDO), U2801.12 (SDO), U3301.12 (SDO); also elsewhere on the board
/GPIO3: U2301.14 (SDI), U2801.14 (SDI), U3301.14 (SDI); also elsewhere on the board
/GPIO8: U801.12 (SDO), U1301.12 (SDO), U1801.12 (SDO); also elsewhere on the board
/GPIO11: U801.14 (SDI), U1301.14 (SDI), U1801.14 (SDI); also elsewhere on the board
/SPI0_SCLK: U801.13 (SCLK), U1301.13 (SCLK), U1801.13 (SCLK); also elsewhere on the board
/SPI1_SCLK: U2301.13 (SCLK), U2801.13 (SCLK), U3301.13 (SCLK); also elsewhere on the board
/Sensor Array/4_Sensor_bank1/EN0: U801.5 (AIN6/GPIO6); also elsewhere on the board
/Sensor Array/4_Sensor_bank1/EN1: U801.3 (AIN4/GPIO4); also elsewhere on the board
/Sensor Array/4_Sensor_bank1/EN2: U801.1 (AIN2/GPIO2); also elsewhere on the board
/Sensor Array/4_Sensor_bank1/EN3: U801.15 (AIN0/GPIO0); also elsewhere on the board
/Sensor Array/4_Sensor_bank1/Y0: C804.1, U801.6 (AIN7/GPIO7); also elsewhere on the board
/Sensor Array/4_Sensor_bank1/Y1: C805.1, U801.4 (AIN5/GPIO5); also elsewhere on the board
/Sensor Array/4_Sensor_bank1/Y2: C806.1, U801.2 (AIN3/GPIO3); also elsewhere on the board
/Sensor Array/4_Sensor_bank1/Y3: C807.1, U801.16 (AIN1/GPIO1); also elsewhere on the board
/Sensor Array/4_Sensor_bank2/EN0: U1301.5 (AIN6/GPIO6); also elsewhere on the board
/Sensor Array/4_Sensor_bank2/EN1: U1301.3 (AIN4/GPIO4); also elsewhere on the board
/Sensor Array/4_Sensor_bank2/EN2: U1301.1 (AIN2/GPIO2); also elsewhere on the board
/Sensor Array/4_Sensor_bank2/EN3: U1301.15 (AIN0/GPIO0); also elsewhere on the board
/Sensor Array/4_Sensor_bank2/Y0: C1304.1, U1301.6 (AIN7/GPIO7); also elsewhere on the board
/Sensor Array/4_Sensor_bank2/Y1: C1305.1, U1301.4 (AIN5/GPIO5); also elsewhere on the board
/Sensor Array/4_Sensor_bank2/Y2: C1306.1, U1301.2 (AIN3/GPIO3); also elsewhere on the board
/Sensor Array/4_Sensor_bank2/Y3: C1307.1, U1301.16 (AIN1/GPIO1); also elsewhere on the board
/Sensor Array/4_Sensor_bank3/EN0: U1801.5 (AIN6/GPIO6); also elsewhere on the board
/Sensor Array/4_Sensor_bank3/EN1: U1801.3 (AIN4/GPIO4); also elsewhere on the board
/Sensor Array/4_Sensor_bank3/EN2: U1801.1 (AIN2/GPIO2); also elsewhere on the board
/Sensor Array/4_Sensor_bank3/EN3: U1801.15 (AIN0/GPIO0); also elsewhere on the board
/Sensor Array/4_Sensor_bank3/Y0: C1804.1, U1801.6 (AIN7/GPIO7); also elsewhere on the board
/Sensor Array/4_Sensor_bank3/Y1: C1805.1, U1801.4 (AIN5/GPIO5); also elsewhere on the board
/Sensor Array/4_Sensor_bank3/Y2: C1806.1, U1801.2 (AIN3/GPIO3); also elsewhere on the board
/Sensor Array/4_Sensor_bank3/Y3: C1807.1, U1801.16 (AIN1/GPIO1); also elsewhere on the board
/Sensor Array/4_Sensor_bank4/EN0: U2301.5 (AIN6/GPIO6); also elsewhere on the board
/Sensor Array/4_Sensor_bank4/EN1: U2301.3 (AIN4/GPIO4); also elsewhere on the board
/Sensor Array/4_Sensor_bank4/EN2: U2301.1 (AIN2/GPIO2); also elsewhere on the board
/Sensor Array/4_Sensor_bank4/EN3: U2301.15 (AIN0/GPIO0); also elsewhere on the board
/Sensor Array/4_Sensor_bank4/Y0: C2304.1, U2301.6 (AIN7/GPIO7); also elsewhere on the board
/Sensor Array/4_Sensor_bank4/Y1: C2305.1, U2301.4 (AIN5/GPIO5); also elsewhere on the board
/Sensor Array/4_Sensor_bank4/Y2: C2306.1, U2301.2 (AIN3/GPIO3); also elsewhere on the board
/Sensor Array/4_Sensor_bank4/Y3: C2307.1, U2301.16 (AIN1/GPIO1); also elsewhere on the board
/Sensor Array/4_Sensor_bank5/EN0: U2801.5 (AIN6/GPIO6); also elsewhere on the board
/Sensor Array/4_Sensor_bank5/EN1: U2801.3 (AIN4/GPIO4); also elsewhere on the board
/Sensor Array/4_Sensor_bank5/EN2: U2801.1 (AIN2/GPIO2); also elsewhere on the board
/Sensor Array/4_Sensor_bank5/EN3: U2801.15 (AIN0/GPIO0); also elsewhere on the board
/Sensor Array/4_Sensor_bank5/Y0: C2804.1, U2801.6 (AIN7/GPIO7); also elsewhere on the board
/Sensor Array/4_Sensor_bank5/Y1: C2805.1, U2801.4 (AIN5/GPIO5); also elsewhere on the board
/Sensor Array/4_Sensor_bank5/Y2: C2806.1, U2801.2 (AIN3/GPIO3); also elsewhere on the board
/Sensor Array/4_Sensor_bank5/Y3: C2807.1, U2801.16 (AIN1/GPIO1); also elsewhere on the board
/Sensor Array/4_Sensor_bank6/EN0: U3301.5 (AIN6/GPIO6); also elsewhere on the board
/Sensor Array/4_Sensor_bank6/EN1: U3301.3 (AIN4/GPIO4); also elsewhere on the board
/Sensor Array/4_Sensor_bank6/EN2: U3301.1 (AIN2/GPIO2); also elsewhere on the board
/Sensor Array/4_Sensor_bank6/EN3: U3301.15 (AIN0/GPIO0); also elsewhere on the board
/Sensor Array/4_Sensor_bank6/Y0: C3304.1, U3301.6 (AIN7/GPIO7); also elsewhere on the board
/Sensor Array/4_Sensor_bank6/Y1: C3305.1, U3301.4 (AIN5/GPIO5); also elsewhere on the board
/Sensor Array/4_Sensor_bank6/Y2: C3306.1, U3301.2 (AIN3/GPIO3); also elsewhere on the board
/Sensor Array/4_Sensor_bank6/Y3: C3307.1, U3301.16 (AIN1/GPIO1); also elsewhere on the board
GND: C801.2, C802.2, C803.2, C804.2, C805.2, C806.2, C807.2, C1301.2, C1302.2, C1303.2, C1304.2, C1305.2, C1306.2, C1307.2, C1801.2, C1802.2, C1803.2, C1804.2, C1805.2, C1806.2, C1807.2, C2301.2, C2302.2, C2303.2, C2304.2, C2305.2, C2306.2, C2307.2, C2801.2, C2802.2, C2803.2, C2804.2, C2805.2, C2806.2, C2807.2, C3301.2, C3302.2, C3303.2, C3304.2, C3305.2, C3306.2, C3307.2, U801.9 (GND), U801.17 (GND), U1301.9 (GND), U1301.17 (GND), U1801.9 (GND), U1801.17 (GND), U2301.9 (GND), U2301.17 (GND), U2801.9 (GND), U2801.17 (GND), U3301.9 (GND), U3301.17 (GND); also elsewhere on the board
unnamed: C802.1, U801.8 (DECAP)
unnamed: C1302.1, U1301.8 (DECAP)
unnamed: C1802.1, U1801.8 (DECAP)
unnamed: C2302.1, U2301.8 (DECAP)
unnamed: C2802.1, U2801.8 (DECAP)
unnamed: C3302.1, U3301.8 (DECAP)

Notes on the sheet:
Place these caps next to ADC input pins

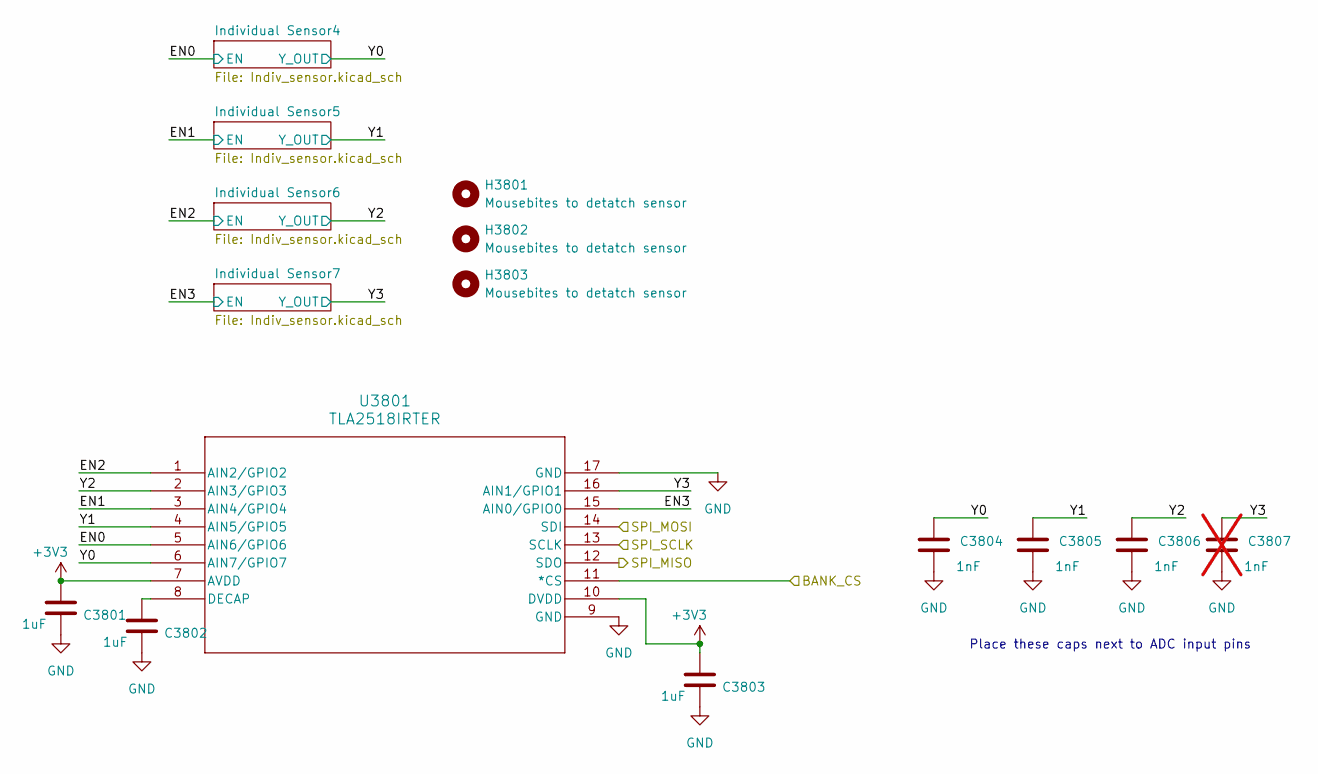
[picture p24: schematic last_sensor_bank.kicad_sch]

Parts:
C3801, C3802, C3803: 1uF; C_0402_1005Metric; JLCPCB Part # C52923
C3804, C3805, C3806: 1nF; C_0402_1005Metric; JLCPCB Part # C1523
C3807: 1nF; C_0402_1005Metric; JLCPCB Part # C1523; not fitted
H3801, H3802, H3803: Mousebites to detatch sensor; mousebite_34mm
U3801: TLA2518IRTER; WQFN16_RTE_TEX; JLCPCB Part # C1855741

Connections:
+3V3: C3801.1, C3803.1, U3801.7 (AVDD), U3801.10 (DVDD); also elsewhere on the board
/BANK_7_CS: U3801.11 (*CS); also elsewhere on the board
/GPIO0: U3801.12 (SDO); also elsewhere on the board
/GPIO3: U3801.14 (SDI); also elsewhere on the board
/SPI1_SCLK: U3801.13 (SCLK); also elsewhere on the board
/Sensor Array/Last_sensor_bank/EN0: U3801.5 (AIN6/GPIO6); also elsewhere on the board
/Sensor Array/Last_sensor_bank/EN1: U3801.3 (AIN4/GPIO4); also elsewhere on the board
/Sensor Array/Last_sensor_bank/EN2: U3801.1 (AIN2/GPIO2); also elsewhere on the board
/Sensor Array/Last_sensor_bank/EN3: U3801.15 (AIN0/GPIO0)
/Sensor Array/Last_sensor_bank/Y0: C3804.1, U3801.6 (AIN7/GPIO7); also elsewhere on the board
/Sensor Array/Last_sensor_bank/Y1: C3805.1, U3801.4 (AIN5/GPIO5); also elsewhere on the board
/Sensor Array/Last_sensor_bank/Y2: C3806.1, U3801.2 (AIN3/GPIO3); also elsewhere on the board
/Sensor Array/Last_sensor_bank/Y3: C3807.1, U3801.16 (AIN1/GPIO1)
GND: C3801.2, C3802.2, C3803.2, C3804.2, C3805.2, C3806.2, C3807.2, U3801.9 (GND), U3801.17 (GND); also elsewhere on the board
unnamed: C3802.1, U3801.8 (DECAP)

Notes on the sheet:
Place these caps next to ADC input pins

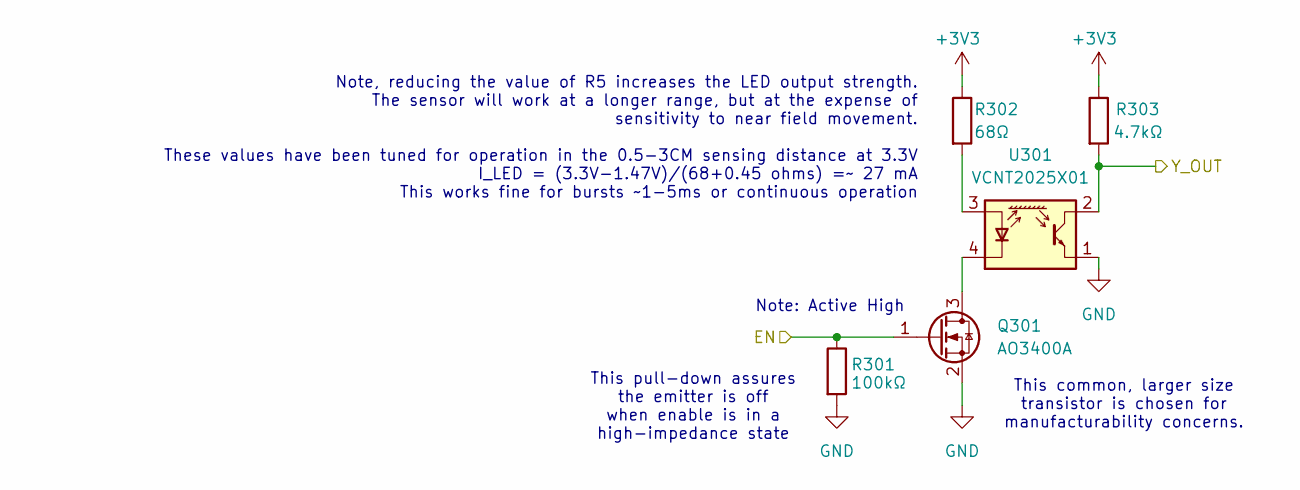
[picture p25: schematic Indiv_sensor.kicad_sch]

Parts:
Q301: AO3400A; SOT-23; JLCPCB Part # C20917
R301: 100kΩ; R_0402_1005Metric
R302: 68Ω; R_0402_1005Metric
R303: 4.7kΩ; R_0402_1005Metric
U301: VCNT2025X01; VCNT2025X01_VIS; JLCPCB Part # C7431257

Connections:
+3V3: R302.1, R303.1; also elsewhere on the board
/Sensor Array/4_Sensor_bank/EN0: Q301.1 (G), R301.1; also elsewhere on the board
/Sensor Array/4_Sensor_bank/Y0: R303.2, U301.2; also elsewhere on the board
GND: Q301.2 (S), R301.2, U301.1; also elsewhere on the board
unnamed: Q301.3 (D), U301.4 (K)
unnamed: R302.2, U301.3 (A)

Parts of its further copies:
Q501, Q601, Q701, Q901, Q1001, Q1101, Q1201, Q1401, Q1501, Q1601, Q1701, Q1901, Q2001, Q2101, Q2201, Q2401, Q2501, Q2601, Q2701, Q2901, Q3001, Q3101, Q3201, Q3401, Q3501, Q3601, Q3701, Q4301, Q4401, Q4501: AO3400A; SOT-23; JLCPCB Part # C20917
R501, R601, R701, R901, R1001, R1101, R1201, R1401, R1501, R1601, R1701, R1901, R2001, R2101, R2201, R2401, R2501, R2601, R2701, R2901, R3001, R3101, R3201, R3401, R3501, R3601, R3701, R4301, R4401, R4501: 100kΩ; R_0402_1005Metric
R502, R602, R702, R902, R1002, R1102, R1202, R1402, R1502, R1602, R1702, R1902, R2002, R2102, R2202, R2402, R2502, R2602, R2702, R2902, R3002, R3102, R3202, R3402, R3502, R3602, R3702, R4302, R4402, R4502: 68Ω; R_0402_1005Metric
R503, R603, R703, R903, R1003, R1103, R1203, R1403, R1503, R1603, R1703, R1903, R2003, R2103, R2203, R2403, R2503, R2603, R2703, R2903, R3003, R3103, R3203, R3403, R3503, R3603, R3703, R4303, R4403, R4503: 4.7kΩ; R_0402_1005Metric
U501, U601, U701, U901, U1001, U1101, U1201, U1401, U1501, U1601, U1701, U1901, U2001, U2101, U2201, U2401, U2501, U2601, U2701, U2901, U3001, U3101, U3201, U3401, U3501, U3601, U3701, U4301, U4401, U4501: VCNT2025X01; VCNT2025X01_VIS; JLCPCB Part # C7431257

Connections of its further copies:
+3V3: R502.1, R503.1, R602.1, R603.1, R702.1, R703.1, R902.1, R903.1, R1002.1, R1003.1, R1102.1, R1103.1, R1202.1, R1203.1, R1402.1, R1403.1, R1502.1, R1503.1, R1602.1, R1603.1, R1702.1, R1703.1, R1902.1, R1903.1, R2002.1, R2003.1, R2102.1, R2103.1, R2202.1, R2203.1, R2402.1, R2403.1, R2502.1, R2503.1, R2602.1, R2603.1, R2702.1, R2703.1, R2902.1, R2903.1, R3002.1, R3003.1, R3102.1, R3103.1, R3202.1, R3203.1, R3402.1, R3403.1, R3502.1, R3503.1, R3602.1, R3603.1, R3702.1, R3703.1, R4302.1, R4303.1, R4402.1, R4403.1, R4502.1, R4503.1; also elsewhere on the board
/Sensor Array/4_Sensor_bank1/EN0: Q901.1 (G), R901.1; also elsewhere on the board
/Sensor Array/4_Sensor_bank1/EN1: Q1001.1 (G), R1001.1; also elsewhere on the board
/Sensor Array/4_Sensor_bank1/EN2: Q1101.1 (G), R1101.1; also elsewhere on the board
/Sensor Array/4_Sensor_bank1/EN3: Q1201.1 (G), R1201.1; also elsewhere on the board
/Sensor Array/4_Sensor_bank1/Y0: R903.2, U901.2; also elsewhere on the board
/Sensor Array/4_Sensor_bank1/Y1: R1003.2, U1001.2; also elsewhere on the board
/Sensor Array/4_Sensor_bank1/Y2: R1103.2, U1101.2; also elsewhere on the board
/Sensor Array/4_Sensor_bank1/Y3: R1203.2, U1201.2; also elsewhere on the board
/Sensor Array/4_Sensor_bank2/EN0: Q1401.1 (G), R1401.1; also elsewhere on the board
/Sensor Array/4_Sensor_bank2/EN1: Q1501.1 (G), R1501.1; also elsewhere on the board
/Sensor Array/4_Sensor_bank2/EN2: Q1601.1 (G), R1601.1; also elsewhere on the board
/Sensor Array/4_Sensor_bank2/EN3: Q1701.1 (G), R1701.1; also elsewhere on the board
/Sensor Array/4_Sensor_bank2/Y0: R1403.2, U1401.2; also elsewhere on the board
/Sensor Array/4_Sensor_bank2/Y1: R1503.2, U1501.2; also elsewhere on the board
/Sensor Array/4_Sensor_bank2/Y2: R1603.2, U1601.2; also elsewhere on the board
/Sensor Array/4_Sensor_bank2/Y3: R1703.2, U1701.2; also elsewhere on the board
/Sensor Array/4_Sensor_bank3/EN0: Q1901.1 (G), R1901.1; also elsewhere on the board
/Sensor Array/4_Sensor_bank3/EN1: Q2001.1 (G), R2001.1; also elsewhere on the board
/Sensor Array/4_Sensor_bank3/EN2: Q2101.1 (G), R2101.1; also elsewhere on the board
/Sensor Array/4_Sensor_bank3/EN3: Q2201.1 (G), R2201.1; also elsewhere on the board
/Sensor Array/4_Sensor_bank3/Y0: R1903.2, U1901.2; also elsewhere on the board
/Sensor Array/4_Sensor_bank3/Y1: R2003.2, U2001.2; also elsewhere on the board
/Sensor Array/4_Sensor_bank3/Y2: R2103.2, U2101.2; also elsewhere on the board
/Sensor Array/4_Sensor_bank3/Y3: R2203.2, U2201.2; also elsewhere on the board
/Sensor Array/4_Sensor_bank4/EN0: Q2401.1 (G), R2401.1; also elsewhere on the board
/Sensor Array/4_Sensor_bank4/EN1: Q2501.1 (G), R2501.1; also elsewhere on the board
/Sensor Array/4_Sensor_bank4/EN2: Q2601.1 (G), R2601.1; also elsewhere on the board
/Sensor Array/4_Sensor_bank4/EN3: Q2701.1 (G), R2701.1; also elsewhere on the board
/Sensor Array/4_Sensor_bank4/Y0: R2403.2, U2401.2; also elsewhere on the board
/Sensor Array/4_Sensor_bank4/Y1: R2503.2, U2501.2; also elsewhere on the board
/Sensor Array/4_Sensor_bank4/Y2: R2603.2, U2601.2; also elsewhere on the board
/Sensor Array/4_Sensor_bank4/Y3: R2703.2, U2701.2; also elsewhere on the board
/Sensor Array/4_Sensor_bank5/EN0: Q2901.1 (G), R2901.1; also elsewhere on the board
/Sensor Array/4_Sensor_bank5/EN1: Q3001.1 (G), R3001.1; also elsewhere on the board
/Sensor Array/4_Sensor_bank5/EN2: Q3101.1 (G), R3101.1; also elsewhere on the board
/Sensor Array/4_Sensor_bank5/EN3: Q3201.1 (G), R3201.1; also elsewhere on the board
/Sensor Array/4_Sensor_bank5/Y0: R2903.2, U2901.2; also elsewhere on the board
/Sensor Array/4_Sensor_bank5/Y1: R3003.2, U3001.2; also elsewhere on the board
/Sensor Array/4_Sensor_bank5/Y2: R3103.2, U3101.2; also elsewhere on the board
/Sensor Array/4_Sensor_bank5/Y3: R3203.2, U3201.2; also elsewhere on the board
/Sensor Array/4_Sensor_bank6/EN0: Q3401.1 (G), R3401.1; also elsewhere on the board
/Sensor Array/4_Sensor_bank6/EN1: Q3501.1 (G), R3501.1; also elsewhere on the board
/Sensor Array/4_Sensor_bank6/EN2: Q3601.1 (G), R3601.1; also elsewhere on the board
/Sensor Array/4_Sensor_bank6/EN3: Q3701.1 (G), R3701.1; also elsewhere on the board
/Sensor Array/4_Sensor_bank6/Y0: R3403.2, U3401.2; also elsewhere on the board
/Sensor Array/4_Sensor_bank6/Y1: R3503.2, U3501.2; also elsewhere on the board
/Sensor Array/4_Sensor_bank6/Y2: R3603.2, U3601.2; also elsewhere on the board
/Sensor Array/4_Sensor_bank6/Y3: R3703.2, U3701.2; also elsewhere on the board
/Sensor Array/4_Sensor_bank/EN1: Q501.1 (G), R501.1; also elsewhere on the board
/Sensor Array/4_Sensor_bank/EN2: Q601.1 (G), R601.1; also elsewhere on the board
/Sensor Array/4_Sensor_bank/EN3: Q701.1 (G), R701.1; also elsewhere on the board
/Sensor Array/4_Sensor_bank/Y1: R503.2, U501.2; also elsewhere on the board
/Sensor Array/4_Sensor_bank/Y2: R603.2, U601.2; also elsewhere on the board
/Sensor Array/4_Sensor_bank/Y3: R703.2, U701.2; also elsewhere on the board
/Sensor Array/Last_sensor_bank/EN0: Q4301.1 (G), R4301.1; also elsewhere on the board
/Sensor Array/Last_sensor_bank/EN1: Q4401.1 (G), R4401.1; also elsewhere on the board
/Sensor Array/Last_sensor_bank/EN2: Q4501.1 (G), R4501.1; also elsewhere on the board
/Sensor Array/Last_sensor_bank/Y0: R4303.2, U4301.2; also elsewhere on the board
/Sensor Array/Last_sensor_bank/Y1: R4403.2, U4401.2; also elsewhere on the board
/Sensor Array/Last_sensor_bank/Y2: R4503.2, U4501.2; also elsewhere on the board
GND: Q501.2 (S), Q601.2 (S), Q701.2 (S), Q901.2 (S), Q1001.2 (S), Q1101.2 (S), Q1201.2 (S), Q1401.2 (S), Q1501.2 (S), Q1601.2 (S), Q1701.2 (S), Q1901.2 (S), Q2001.2 (S), Q2101.2 (S), Q2201.2 (S), Q2401.2 (S), Q2501.2 (S), Q2601.2 (S), Q2701.2 (S), Q2901.2 (S), Q3001.2 (S), Q3101.2 (S), Q3201.2 (S), Q3401.2 (S), Q3501.2 (S), Q3601.2 (S), Q3701.2 (S), Q4301.2 (S), Q4401.2 (S), Q4501.2 (S), R501.2, R601.2, R701.2, R901.2, R1001.2, R1101.2, R1201.2, R1401.2, R1501.2, R1601.2, R1701.2, R1901.2, R2001.2, R2101.2, R2201.2, R2401.2, R2501.2, R2601.2, R2701.2, R2901.2, R3001.2, R3101.2, R3201.2, R3401.2, R3501.2, R3601.2, R3701.2, R4301.2, R4401.2, R4501.2, U501.1, U601.1, U701.1, U901.1, U1001.1, U1101.1, U1201.1, U1401.1, U1501.1, U1601.1, U1701.1, U1901.1, U2001.1, U2101.1, U2201.1, U2401.1, U2501.1, U2601.1, U2701.1, U2901.1, U3001.1, U3101.1, U3201.1, U3401.1, U3501.1, U3601.1, U3701.1, U4301.1, U4401.1, U4501.1; also elsewhere on the board
unnamed: Q501.3 (D), U501.4 (K)
unnamed: Q601.3 (D), U601.4 (K)
unnamed: Q701.3 (D), U701.4 (K)
unnamed: Q901.3 (D), U901.4 (K)
unnamed: Q1001.3 (D), U1001.4 (K)
unnamed: Q1101.3 (D), U1101.4 (K)
unnamed: Q1201.3 (D), U1201.4 (K)
unnamed: Q1401.3 (D), U1401.4 (K)
unnamed: Q1501.3 (D), U1501.4 (K)
unnamed: Q1601.3 (D), U1601.4 (K)
unnamed: Q1701.3 (D), U1701.4 (K)
unnamed: Q1901.3 (D), U1901.4 (K)
unnamed: Q2001.3 (D), U2001.4 (K)
unnamed: Q2101.3 (D), U2101.4 (K)
unnamed: Q2201.3 (D), U2201.4 (K)
unnamed: Q2401.3 (D), U2401.4 (K)
unnamed: Q2501.3 (D), U2501.4 (K)
unnamed: Q2601.3 (D), U2601.4 (K)
unnamed: Q2701.3 (D), U2701.4 (K)
unnamed: Q2901.3 (D), U2901.4 (K)
unnamed: Q3001.3 (D), U3001.4 (K)
unnamed: Q3101.3 (D), U3101.4 (K)
unnamed: Q3201.3 (D), U3201.4 (K)
unnamed: Q3401.3 (D), U3401.4 (K)
unnamed: Q3501.3 (D), U3501.4 (K)
unnamed: Q3601.3 (D), U3601.4 (K)
unnamed: Q3701.3 (D), U3701.4 (K)
unnamed: Q4301.3 (D), U4301.4 (K)
unnamed: Q4401.3 (D), U4401.4 (K)
unnamed: Q4501.3 (D), U4501.4 (K)
unnamed: R502.2, U501.3 (A)
unnamed: R602.2, U601.3 (A)
unnamed: R702.2, U701.3 (A)
unnamed: R902.2, U901.3 (A)
unnamed: R1002.2, U1001.3 (A)
unnamed: R1102.2, U1101.3 (A)
unnamed: R1202.2, U1201.3 (A)
unnamed: R1402.2, U1401.3 (A)
unnamed: R1502.2, U1501.3 (A)
unnamed: R1602.2, U1601.3 (A)
unnamed: R1702.2, U1701.3 (A)
unnamed: R1902.2, U1901.3 (A)
unnamed: R2002.2, U2001.3 (A)
unnamed: R2102.2, U2101.3 (A)
unnamed: R2202.2, U2201.3 (A)
unnamed: R2402.2, U2401.3 (A)
unnamed: R2502.2, U2501.3 (A)
unnamed: R2602.2, U2601.3 (A)
unnamed: R2702.2, U2701.3 (A)
unnamed: R2902.2, U2901.3 (A)
unnamed: R3002.2, U3001.3 (A)
unnamed: R3102.2, U3101.3 (A)
unnamed: R3202.2, U3201.3 (A)
unnamed: R3402.2, U3401.3 (A)
unnamed: R3502.2, U3501.3 (A)
unnamed: R3602.2, U3601.3 (A)
unnamed: R3702.2, U3701.3 (A)
unnamed: R4302.2, U4301.3 (A)
unnamed: R4402.2, U4401.3 (A)
unnamed: R4502.2, U4501.3 (A)

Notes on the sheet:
This pull-down assures the emitter is off when enable is in a high-impedance state
This common, larger size transistor is chosen for manufacturability concerns.
Note: Active High
Note, reducing the value of R5 increases the LED output strength. The sensor will work at a longer range, but at the expense of sensitivity to near field movement. These values have been tuned for operation in the 0.5-3CM sensing distance at 3.3V I_LED = (3.3V-1.47V)/(68+0.45 ohms) =~ 27 mA This wo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

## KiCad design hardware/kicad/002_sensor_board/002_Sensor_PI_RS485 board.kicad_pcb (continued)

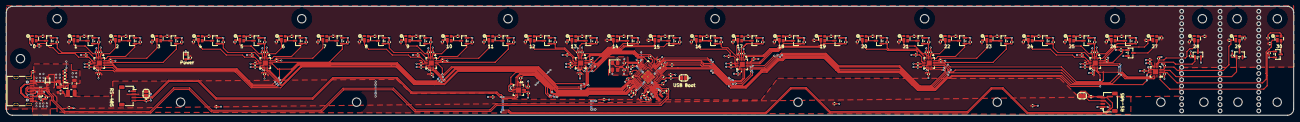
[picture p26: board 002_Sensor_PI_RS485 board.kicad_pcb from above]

Board: 2 copper layers, 413.7 x 35.0 mm, 300 parts (0 on the bottom side), 183 nets.

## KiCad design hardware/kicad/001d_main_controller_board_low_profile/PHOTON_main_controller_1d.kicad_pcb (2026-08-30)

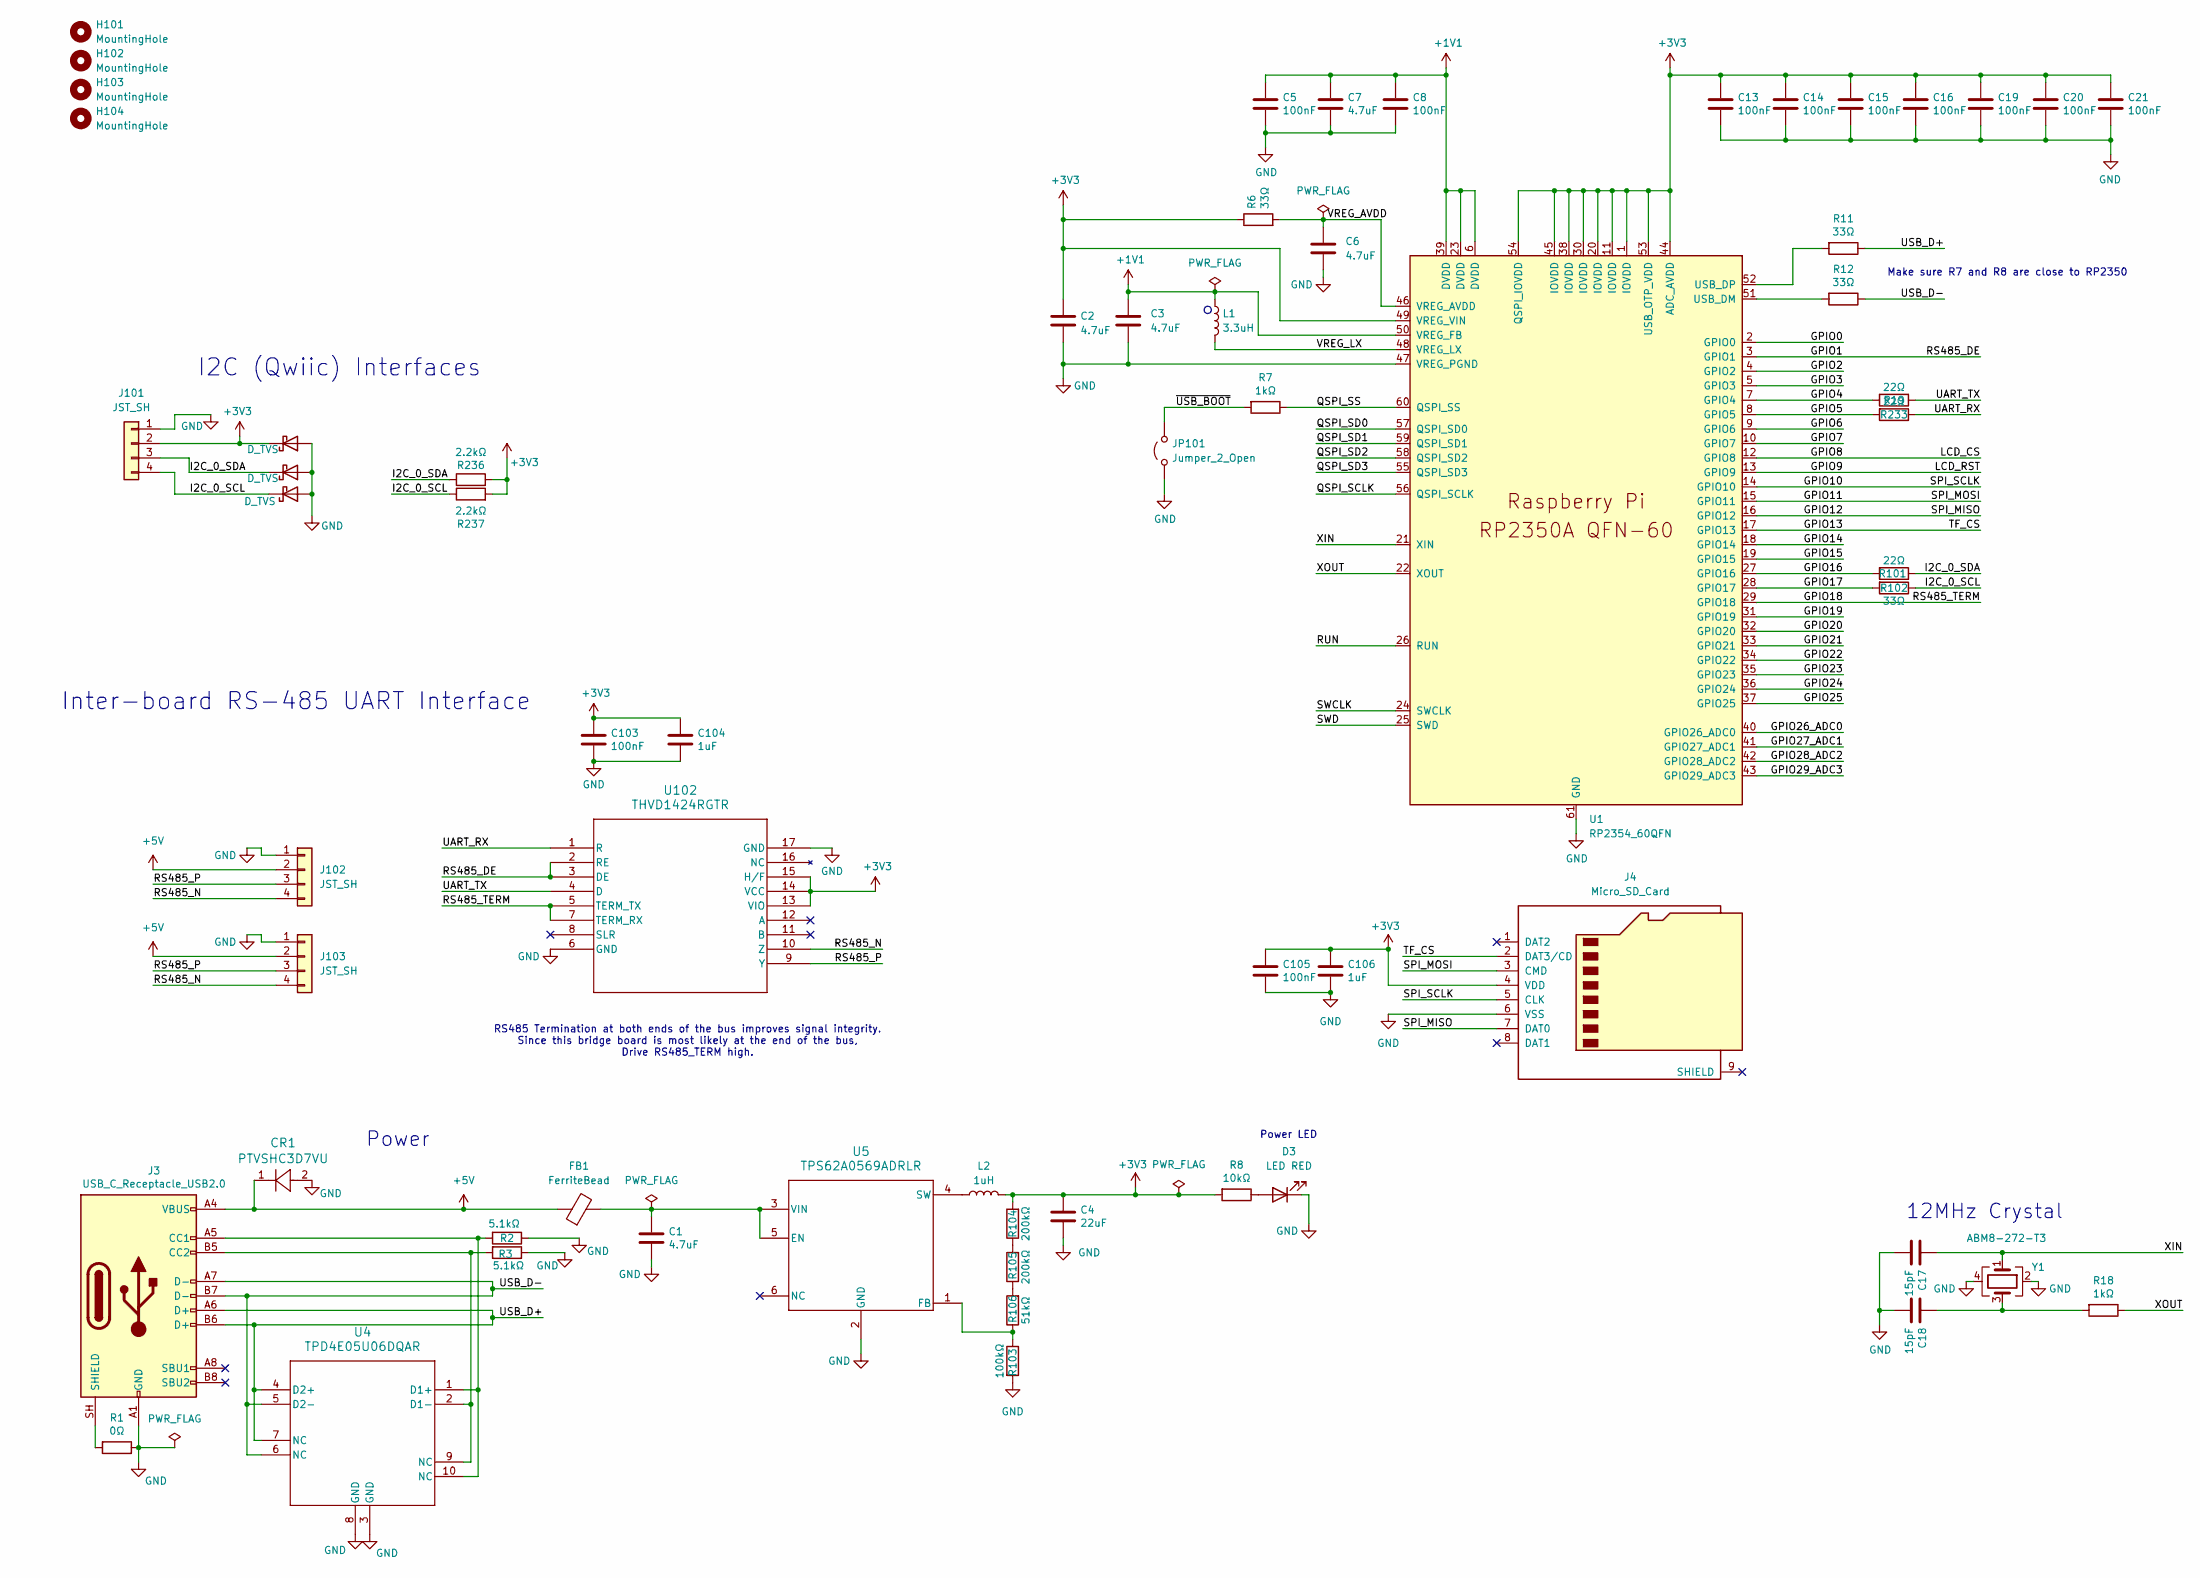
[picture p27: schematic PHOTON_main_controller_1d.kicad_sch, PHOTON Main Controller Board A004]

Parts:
C1: 4.7uF; C_0805_2012Metric; Part # CL21A475KAQNNNE; JLCPCB Part # C1779
C2, C3: 4.7uF; C_0402_1005Metric_small_pads
C4: 22uF; C_0805_2012Metric; JLCPCB Part # C45783
C5, C8, C13, C14, C15, C16, C19, C20, C21, C103, C105: 100nF; C_0402_1005Metric; JLCPCB Part # C1525
C6, C7: 4.7uF; C_0402_1005Metric
C17, C18: 15pF; C_0402_1005Metric; JLCPCB Part # C1548
C104, C106: 1uF; C_0402_1005Metric; JLCPCB Part # C52923
CR1: PTVSHC3D7VU; SOD-323_L1.8-W1.3-LS2.5-RD; JLCPCB Part # C20615807
D3: LED RED; LED_0603_1608Metric; JLCPCB Part # C2286
D10, D11, D12: D_TVS; D_SOD-523; JLCPCB Part # C20617921
FB1: FerriteBead; L_0603_1608Metric; JLCPCB Part # C14709
H101, H102, H103, H104: MountingHole; MountingHole_2.7mm_M2.5_Keepout
J3: USB_C_Receptacle_USB2.0; USB_C_Receptacle_HRO_TYPE-C-31-M-12; MPN TYPE-C-31-M-12; JLCPCB Part # C165948
J4: Micro_SD_Card; TF-015_corrected; JLCPCB Part # C113206
J101, J102, J103: JST_SH; JST_SH_SM04B-SRSS-TB_1x04-1MP_P1.00mm_Horizontal; Part Number SM04B-SRSS-TB(LF)(SN); JLCPCB Part # C160404
JP101: Jumper_2_Open; SolderJumper-2_P1.3mm_Open_Pad1.0x1.5mm
L1: 3.3uH; L_pol_2016; JLCPCB Part # C42411119
L2: 1uH; L_1008_2520Metric; Part # C2041556; JLCPCB Part # C2041556
R1: 0Ω; R_0402_1005Metric
R2, R3: 5.1kΩ; R_0402_1005Metric; JLCPCB Part # C25905
R6, R11, R12, R102: 33Ω; R_0402_1005Metric
R7, R18: 1kΩ; R_0402_1005Metric
R8: 10kΩ; R_0402_1005Metric
R19, R101, R233: 22Ω; R_0402_1005Metric
R103: 100kΩ; R_0402_1005Metric
R104, R105: 200kΩ; R_0402_1005Metric
R106: 51kΩ; R_0402_1005Metric
R236, R237: 2.2kΩ; R_0402_1005Metric
U1: RP2354_60QFN; RP2350-QFN-60-1EP_7x7_P0.4mm_EP3.4x3.4mm_ThermalVias; JLCPCB Part # C41378174
U4: TPD4E05U06DQAR; DQA0010A; JLCPCB Part # C138714
U5: TPS62A0569ADRLR; SOT-563_DRL0006A; JLCPCB Part # C53151500
U102: THVD1424RGTR; QFN_24RGTR_TEX; JLCPCB Part # C5359161
Y1: ABM8-272-T3; Crystal_SMD_3225-4Pin_3.2x2.5mm; JLCPCB Part # C20625731

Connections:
+1V1: C3.1, C5.1, C7.1, C8.1, L1.1, U1.6 (DVDD), U1.23 (DVDD), U1.39 (DVDD), U1.50 (VREG_FB)
+3V3: C2.1, C4.1, C13.1, C14.1, C15.1, C16.1, C19.1, C20.1, C21.1, C103.1, C104.1, C105.1, C106.1, D12.1 (K), J4.4 (VDD), J101.2, L2.2, R6.1, R8.2, R104.2, R236.2, R237.2, U1.1 (IOVDD), U1.11 (IOVDD), U1.20 (IOVDD), U1.30 (IOVDD), U1.38 (IOVDD), U1.44 (ADC_AVDD), U1.45 (IOVDD), U1.49 (VREG_VIN), U1.53 (USB_OTP_VDD), U1.54 (QSPI_IOVDD), U102.13 (VIO), U102.14 (VCC), U102.15 (H/F)
+5V: CR1.1, FB1.1, J3.A4 (VBUS), J3.A9 (VBUS), J3.B4 (VBUS), J3.B9 (VBUS), J102.2, J103.2
/GPIO0: U1.2 (GPIO0)
/GPIO1: U1.3 (GPIO1), U102.2 (RE), U102.3 (DE)
/GPIO2: U1.4 (GPIO2)
/GPIO3: U1.5 (GPIO3)
/GPIO4: R19.2, U1.7 (GPIO4)
/GPIO5: R233.2, U1.8 (GPIO5)
/GPIO6: U1.9 (GPIO6)
/GPIO7: U1.10 (GPIO7)
/GPIO8: U1.12 (GPIO8)
/GPIO9: U1.13 (GPIO9)
/GPIO10: J4.5 (CLK), U1.14 (GPIO10)
/GPIO11: J4.3 (CMD), U1.15 (GPIO11)
/GPIO12: J4.7 (DAT0), U1.16 (GPIO12)
/GPIO13: J4.2 (DAT3/CD), U1.17 (GPIO13)
/GPIO14: U1.18 (GPIO14)
/GPIO15: U1.19 (GPIO15)
/GPIO16: R101.2, U1.27 (GPIO16)
/GPIO17: R102.2, U1.28 (GPIO17)
/GPIO18: U1.29 (GPIO18), U102.5 (TERM_TX), U102.7 (TERM_RX)
/GPIO19: U1.31 (GPIO19)
/GPIO20: U1.32 (GPIO20)
/GPIO21: U1.33 (GPIO21)
/GPIO22: U1.34 (GPIO22)
/GPIO23: U1.35 (GPIO23)
/GPIO24: U1.36 (GPIO24)
/GPIO25: U1.37 (GPIO25)
/GPIO26_ADC0: U1.40 (GPIO26_ADC0)
/GPIO27_ADC1: U1.41 (GPIO27_ADC1)
/GPIO28_ADC2: U1.42 (GPIO28_ADC2)
/GPIO29_ADC3: U1.43 (GPIO29_ADC3)
/I2C_0_SCL: D11.1 (K), J101.4, R102.1, R237.1
/I2C_0_SDA: D10.1 (K), J101.3, R101.1, R236.1
/QSPI_SCLK: U1.56 (QSPI_SCLK)
/QSPI_SD0: U1.57 (QSPI_SD0)
/QSPI_SD1: U1.59 (QSPI_SD1)
/QSPI_SD2: U1.58 (QSPI_SD2)
/QSPI_SD3: U1.55 (QSPI_SD3)
/QSPI_SS: R7.1, U1.60 (QSPI_SS)
/RS485_N: J102.4, J103.4, U102.10 (Z)
/RS485_P: J102.3, J103.3, U102.9 (Y)
/RUN: U1.26 (RUN)
/SWCLK: U1.24 (SWCLK)
/SWD: U1.25 (SWD)
/UART_RX: R233.1, U102.1 (R)
/UART_TX: R19.1, U102.4 (D)
/USB_D+: J3.A6 (D+), J3.B6 (D+), R11.1, U4.4 (D2+), U4.7 (NC)
/USB_D-: J3.A7 (D-), J3.B7 (D-), R12.1, U4.5 (D2-), U4.6 (NC)
/VREG_AVDD: C6.1, R6.2, U1.46 (VREG_AVDD)
/VREG_LX: L1.2, U1.48 (VREG_LX)
/XIN: C17.1, U1.21 (XIN), Y1.1
/XOUT: R18.1, U1.22 (XOUT)
/~USB_BOOT: JP101.2 (B), R7.2
GND: C1.2, C2.2, C3.2, C4.2, C5.2, C6.2, C7.2, C8.2, C13.2, C14.2, C15.2, C16.2, C17.2, C18.2, C19.2, C20.2, C21.2, C103.2, C104.2, C105.2, C106.2, CR1.2, D3.1 (K), D10.2 (A), D11.2 (A), D12.2 (A), J3.A1 (GND), J3.A12 (GND), J3.B1 (GND), J3.B12 (GND), J4.6 (VSS), J101.1, J102.1, J103.1, JP101.1 (A), R1.1, R2.1, R3.1, R103.2, U1.47 (VREG_PGND), U1.61 (GND), U4.3 (GND), U4.8 (GND), U5.2 (GND), U102.6 (GND), U102.17 (GND), Y1.2, Y1.4
unnamed: C18.1, R18.2, Y1.3
unnamed: D3.2 (A), R8.1
unnamed: J3.A5 (CC1), R2.2, U4.1 (D1+), U4.10 (NC)
unnamed: J3.B5 (CC2), R3.2, U4.2 (D1-), U4.9 (NC)
unnamed: J3.SH (SHIELD), R1.2
unnamed: R104.1, R105.2
unnamed: R105.1, R106.2
unnamed: R12.2, U1.51 (USB_DM)
unnamed: R11.2, U1.52 (USB_DP)
unnamed: C1.1, FB1.2, U5.3 (VIN), U5.5 (EN)
unnamed: R103.1, R106.1, U5.1 (FB)
unnamed: L2.1, U5.4 (SW)

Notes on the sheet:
Inter-board RS-485 UART Interface
Power
12MHz Crystal
I2C (Qwiic) Interfaces
RS485 Termination at both ends of the bus improves signal integrity. Since this bridge board is most likely at the end of the bus, Drive RS485_TERM high.
Power LED
Make sure R7 and R8 are close to RP2350

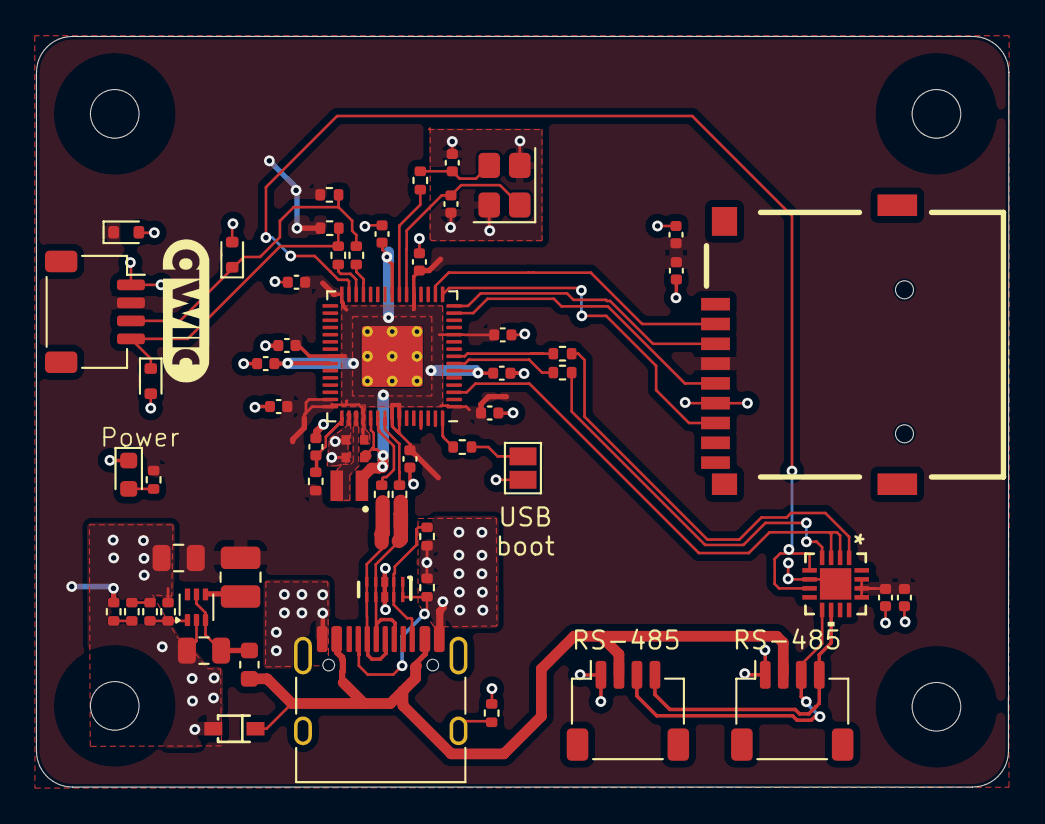
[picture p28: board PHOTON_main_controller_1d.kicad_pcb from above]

Board: 2 copper layers, 54.0 x 41.7 mm, 63 parts (0 on the bottom side), 40 nets.

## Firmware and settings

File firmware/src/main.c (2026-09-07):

// PHOTON native firmware — one image for every board.
//
// Boot: probe the TLA2518 banks. Any bank present => sensor role: core 1
// runs the SRAM-resident scan/event loop, core 0 answers the bus. Zero
// banks => this is the main controller (or future endpoint) board: core 0
// becomes the bus master/bridge (poll cycle + USB-MIDI), core 1 stays off.
// A sensor board with 'master on' saved takes the bus-master role as well
// (instruments built without a main controller board) once a USB host has
// enumerated it and the wire has stayed silent: core 0 then polls the other
// boards and owns USB-MIDI while core 1 keeps scanning its own keys.
//
// The whole binary runs copy-to-RAM (see CMakeLists), so no code fetch ever
// touches flash/XIP at runtime — the scan loop cannot be stalled by core-0
// flash writes, by construction.
#include "hardware/clocks.h"
#include "hardware/watchdog.h"
#include "pico/multicore.h"
#include "pico/stdlib.h"
#include "tusb.h"

#include "board_config.h"
#include "bridge/midi_map.h"
#include "bridge/recorder.h"
#include "comms/protocol.h"
#include "comms/transport.h"
#include "config/config_store.h"
#include "core1/events.h"
#include "core1/scan.h"
#include "core1/tla2518.h"
#include "ipc/rings.h"
#include "usb/cdc_console.h"
#include "util/log.h"

// 'master on' sensor board claiming the bus at runtime: same wiring as the
// main controller board's boot path, minus the pinout/termination/recorder
// (board identity does not change), plus its own scanner in the note map.
static void become_bus_master(void) {
    transport_set_own_addr(PHOTON_ADDR_BRIDGE);
    protocol_init(true, PHOTON_ADDR_BRIDGE);
    protocol_set_self_node_id(g_config.node_id);
    protocol_set_event_sink(midi_map_handle_event);
    protocol_set_node_down_cb(midi_map_release_node);
    protocol_set_response_sink(console_on_bridge_response);
    midi_map_init();
    console_set_bus_master(true);
    log_note("USB host attached and no bus master heard: this board now runs the bus "
             "(node id %u keeps its place in the note map)", g_config.node_id);
}

int main(void) {
    // Deterministic peripheral clock: UART/SPI dividers derive from 150 MHz.
    clock_configure(clk_peri, 0, CLOCKS_CLK_PERI_CTRL_AUXSRC_VALUE_CLK_SYS,
                    clock_get_hz(clk_sys), clock_get_hz(clk_sys));

    rings_init();
    config_store_init();

    int banks_found = tla2518_init_and_probe();
    if (banks_found == 0) {
        // Guard against the field-observed first-transaction SPI glitch
        // hitting the probe itself: a sensor board misprobing as "no banks"
        // would come up as a second bus master. One settled retry.
        sleep_ms(100);
        banks_found = tla2518_init_and_probe();
    }
    bool sensor_role = banks_found > 0;
    // Board identity follows capability: no banks => main controller board
    // pinout, terminated endpoint, microSD socket, bus master from boot. A
    // sensor board with 'master on' boots as a node and claims the master
    // role from the main loop once a USB host has enumerated it and the
    // wire has been silent (become_bus_master).
    bool main_board = !sensor_role;
    bool is_bridge = main_board;
    uint8_t own_addr = is_bridge ? PHOTON_ADDR_BRIDGE : g_config.node_id;

    transport_init(/*use_host_pinout=*/main_board, /*terminate=*/main_board,
                   own_addr, protocol_on_frame);
    protocol_init(is_bridge, own_addr);
    midi_map_init();
    // Every role gets the MIDI sink: the bridge feeds it from poll batches,
    // and a sensor node feeds it its OWN events while no bridge is polling
    // (standalone-over-USB mode). midi_out is silent unless a host mounted
    // the MIDI interface, so this costs nothing on a headless bus node.
    protocol_set_event_sink(midi_map_handle_event);
    if (is_bridge) {
        protocol_set_node_down_cb(midi_map_release_node);
    }
    protocol_set_response_sink(console_on_bridge_response);
    console_init(is_bridge, sensor_role);

    if (sensor_role) {
        events_init(g_config.local_disabled_mask);
        bool have_cal = false;
        for (int i = 0; i < PHOTON_MAX_SENSORS; i++) {
            if (g_config.cal_min[i] != 0xFFFF || g_config.cal_max[i] != 0) {
                events_seed_cal((uint8_t)i, g_config.cal_min[i], g_config.cal_max[i]);
                have_cal = true;
            }
        }
        // Saved calibration => frozen thresholds for performance (continuous
        // learning is polluted by adjacent-key cross-illumination). No saved
        // calibration => boot straight into learning so the board is usable,
        // with the console banner flagging the uncalibrated state.
        g_events.learning = !have_cal;
        g_scan_ctl.mode = g_config.scan_mode <= PHOTON_SCAN_TWO_PHASE
                              ? g_config.scan_mode
                              : PHOTON_SCAN_PARALLEL;
        g_scan_ctl.rate_hz = g_config.scan_rate_hz == 0
                                 ? PHOTON_DEFAULT_SCAN_RATE_HZ
                             : g_config.scan_rate_hz == 0xFFFF
                                 ? 0
                                 : g_config.scan_rate_hz;
        multicore_launch_core1(scan_core1_entry);
        config_store_set_core1_running(true);
    } else {
        // Bridge: core 1 is otherwise idle, so it owns the microSD recorder
        // and every blocking card transfer. The image runs from SRAM, so
        // core-0 config saves need no park (core1_running stays false).
        static uint32_t recorder_stack[2048];  // 8 KB: FatFs + SD driver
        recorder_init();
        multicore_launch_core1_with_stack(recorder_core1_entry, recorder_stack,
                                          sizeof recorder_stack);
    }

    tud_init(0);

    bool announced = false;
    bool zero_fault_handled = false;
    uint32_t quiet_rx = 0;
    absolute_time_t quiet_since = get_absolute_time();
    for (;;) {
        tud_task();
        if (sensor_role && !is_bridge) {
            // A host is truly present only when mounted and not suspended
            // (a pulled cable is a *suspend*, not an unmount — mounted state
            // survives cable removal).
            bool host = tud_midi_mounted() && !tud_suspended();
            // Local USB-MIDI only when the config flag allows it AND a host
            // is present. A master owns its MIDI unconditionally instead.
            protocol_set_local_delivery(g_config.local_midi != 0 && host);
            // 'master on': claim the bus once this board has the host and
            // the wire has been silent for PHOTON_MASTER_QUIET_MS. Nodes
            // never transmit unsolicited, so any received frame means a
            // master is already running and this board stays a node — the
            // board without the USB cable in a bridgeless pair, or any
            // board next to a main controller board.
            if (g_config.bus_master != 0) {
                uint32_t rx = transport_stats()->rx_frames;
                absolute_time_t now = get_absolute_time();
                if (!host || rx != quiet_rx) {
                    quiet_rx = rx;
                    quiet_since = now;
                } else if (absolute_time_diff_us(quiet_since, now) >=
                           (int64_t)PHOTON_MASTER_QUIET_MS * 1000) {
                    become_bus_master();
                    is_bridge = true;
                }
            }
        }
        transport_task();
        protocol_task();
        console_task();

        // Startup zero-fault escalation (legacy microcontroller.reset()
        // behavior): if the array still reads all-zero ~1 s in, reboot —
        // unless a console is attached, where a reboot loop would make
        // USB-only debugging (no SWD populated) impossible.
        if (sensor_role && g_scan_ctl.zero_fault && !zero_fault_handled) {
            zero_fault_handled = true;
            if (log_console_connected()) {
                log_note("sensor array reads all-zero after reinit — check SPI/power "
                         "(auto-reboot suppressed while console attached)");
            } else {
                sleep_ms(100);
                watchdog_reboot(0, 0, 100);
            }
        }

        if (!announced && log_console_connected()) {
            announced = true;
            console_print_banner(banks_found);
        } else if (announced && !log_console_connected()) {
            announced = false;
        }
    }
}

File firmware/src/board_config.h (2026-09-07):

// Single source of truth for pins, peripherals, timing and detection
// constants. Values carried over from the retired CircuitPython
// configuration (git tag last_circuitpython) and the sensor board 002 Rev D
// schematic.
#ifndef PHOTON_BOARD_CONFIG_H
#define PHOTON_BOARD_CONFIG_H

#include "hardware/spi.h"
#include "hardware/uart.h"

// ---------------------------------------------------------------------------
// Sensor array topology (sensor board 002)
// ---------------------------------------------------------------------------
#define PHOTON_BANK_COUNT        8   // TLA2518 chips
#define PHOTON_SLOTS_PER_BANK    4   // sensors per bank
#define PHOTON_MAX_SENSORS       (PHOTON_BANK_COUNT * PHOTON_SLOTS_PER_BANK)  // 32
#define PHOTON_ACTIVE_SENSORS    31  // last slot unpopulated by default

// Per-bank slot map (identical for all banks):
//   slot 0 -> AIN7, emitter GPO bit 6      slot 2 -> AIN3, emitter GPO bit 2
//   slot 1 -> AIN5, emitter GPO bit 4      slot 3 -> AIN1, emitter GPO bit 0
#define PHOTON_SLOT_ADC_CHANNELS { 7, 5, 3, 1 }
#define PHOTON_SLOT_EMITTER_BITS { 6, 4, 2, 0 }
#define PHOTON_EMITTER_MASK_ALL  0x55u

// SPI buses. NOTE the historical software names are swapped relative to the
// hardware peripherals ("spi0" in Python config = hardware SPI1 and vice
// versa). Native code uses hardware names only:
//   bus A = hardware SPI1: SCLK GPIO10, MOSI GPIO11, MISO GPIO8, banks 0-3
//   bus B = hardware SPI0: SCLK GPIO2,  MOSI GPIO3,  MISO GPIO0, banks 4-7
#define PHOTON_SPI_A             spi1
#define PHOTON_SPI_A_SCLK        10
#define PHOTON_SPI_A_MOSI        11
#define PHOTON_SPI_A_MISO        8
#define PHOTON_SPI_B             spi0
#define PHOTON_SPI_B_SCLK        2
#define PHOTON_SPI_B_MOSI        3
#define PHOTON_SPI_B_MISO        0

// Bank -> CS GPIO, banks 0-7. Banks 0-3 on bus A, 4-7 on bus B.
#define PHOTON_BANK_CS_PINS      { 21, 20, 19, 15, 1, 7, 5, 6 }
#define PHOTON_BANK_ON_BUS_B(b)  ((b) >= 4)

// Validated bus speed (2026-09-02). Faster clocks lost register writes to
// the ADC nearest the MCU (near-end reflection on the sensor board); see
// firmware/README.md "Validated settings". Mode-2 sweep 969 us.
#define PHOTON_SPI_BAUD_HZ       (10 * 1000 * 1000)
// Emitter settle before sampling. Bench-measured 2026-08-13: the reading
// depends strongly on this value with keys installed (45 us reads 81-91% of
// 60 us), so the VCNT2025X01 response is still developing well past 30 us.
// An earlier 30 us figure came from a board measured while DISASSEMBLED with
// keys missing - the sensors were staring at nothing, which is not a
// representative optical condition. 50 us keeps close to the long-proven
// 60 us while shortening the sequential sweep (~2533 -> ~2213 us).
// Changing this shifts every reading and REQUIRES recalibration.
#define PHOTON_SETTLE_US         50
#define PHOTON_OSR_MODE          3       // TLA2518 8x oversample, 16-bit results
#define PHOTON_TLA_RESET_WAIT_US 10000   // datasheet requires 5 ms; keep proven 10 ms
#define PHOTON_TLA_BUS_FLUSH_US  10

// ---------------------------------------------------------------------------
// Event engine (values proven in production CircuitPython build)
// ---------------------------------------------------------------------------
#define PHOTON_STRIKE_PCT            60
#define PHOTON_RELEASE_PCT           40
#define PHOTON_VELOCITY_WINDOW_PCT   20
#define PHOTON_STRIKE_WINDOW_PCT     30
#define PHOTON_MIN_EVENT_RANGE       170  // scaled by << osr_mode at runtime (1360 @ OSR 3)

// ---------------------------------------------------------------------------
// RS-485 transport (current hardware, Plan 1)
// ---------------------------------------------------------------------------
#define PHOTON_RS485_UART        uart1
#define PHOTON_RS485_TX          22   // F11 alternate UART1 mapping
#define PHOTON_RS485_RX          23
#define PHOTON_RS485_DE          24
#define PHOTON_RS485_TERM        25
#define PHOTON_RS485_BAUD        4000000  // exact divisor at clk_peri 150 MHz (2.34375)
#define PHOTON_DE_GUARD_US       8    // guard band before/after each frame; THVD1424
                                      // enable time is <100 ns, 8 us is still ample
                                      // (25 us proven first, tightened in bench tuning)

// Main controller board 001 uses different RS-485 pins; probed at runtime:
// if the sensor capability probe finds zero banks, the transport uses these.
#define PHOTON_HOST_UART         uart1
#define PHOTON_HOST_TX           4    // F2 UART1 mapping
#define PHOTON_HOST_RX           5
#define PHOTON_HOST_DE           1
#define PHOTON_HOST_TERM         18
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

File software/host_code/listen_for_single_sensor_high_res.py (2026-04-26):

#!/usr/bin/env python3
import argparse, logging, re, time, sys, os, datetime
import serial
import numpy as np
import matplotlib.pyplot as plt

BEGIN_RE = re.compile(
    r"^BEGIN_TRACE\s+sensor=(\d+)\s+midi=(\S+)\s+note=(\S+)\s+polarity=(\S+)\s+thr_on=(\d+)\s+thr_off=(\d+)"
)
# Lines starting with "#" are logs from the device; data lines are "t_ns,adc"
END_MARK = "END_TRACE"

def parse_args():
    p = argparse.ArgumentParser(
        description="Read oscilloscope trace from CircuitPython over USB serial and plot."
    )
    p.add_argument("--port", required=True, help="Serial port, e.g. /dev/cu.usbmodem101")
    p.add_argument("--baud", type=int, default=115200)
    p.add_argument(
        "--duration", type=float, default=10.0,
        help="Requested capture duration on the device, in seconds"
    )
    p.add_argument(
        "--timeout", type=float, default=None,
        help="Seconds to wait for END_TRACE after BEGIN_TRACE (default: duration + 3 s)"
    )
    p.add_argument(
        "--pre-timeout", type=float, default=0.0,
        help="Optional seconds to wait for BEGIN_TRACE (0 = no limit)"
    )
    p.add_argument("--csv", help="Optional path to save CSV of the captured trace (overrides auto name)")
    p.add_argument(
        "--repeat", action="store_true",
        help="Stay connected after each capture; press Enter for another capture or q to quit"
    )
    p.add_argument("--show", action="store_true", help="Show interactive plot")
    p.add_argument("--log", default="INFO", help="Logging level (DEBUG, INFO, WARNING, ERROR)")
    p.add_argument("--outdir", default=".", help="Directory for auto-saved CSV if --csv is not provided")
    return p.parse_args()

def setup_logging(level: str):
    lvl = getattr(logging, level.upper(), logging.INFO)
    logging.basicConfig(
        level=lvl,
        format="%(asctime)s.%(msecs)03d %(levelname)s: %(message)s",
        datefmt="%H:%M:%S"
    )

def auto_csv_path(outdir: str, meta: dict | None) -> str:
    ts = datetime.datetime.now().strftime("%Y%m%d-%H%M%S")
    if meta:
        sensor = meta.get("sensor", "NA")
        note = meta.get("note", "NA")
        midi = meta.get("midi", "NA")
        base = f"trace_{ts}_sensor-{sensor}_note-{note}_midi-{midi}.csv"
    else:
        base = f"trace_{ts}.csv"
    return os.path.join(outdir, base)


def trigger_capture(ser: serial.Serial, duration_s: float) -> None:
    trigger = f"capture {duration_s:g}\n".encode("utf-8")
    ser.write(trigger)
    ser.flush()
    logging.info("Triggered capture via command: %r", trigger.decode("utf-8").strip())


def read_capture(ser: serial.Serial, *, pre_timeout_s: float, timeout_s: float):
    meta = None
    ts, vs = [], []
    ts_are_seconds = None
    started = False
    begin_seen_at = None
    pre_started_at = time.time()

    logging.info("Waiting for trace... printing all device logs.")
    while True:
        if not started and pre_timeout_s and pre_timeout_s > 0:
            if (time.time() - pre_started_at) > pre_timeout_s:
                logging.error("Pre-trace timeout: BEGIN_TRACE not received.")
                raise SystemExit(1)

        if started and timeout_s > 0 and begin_seen_at is not None:
            if (time.time() - begin_seen_at) > timeout_s:
                logging.error("In-trace timeout: END_TRACE not received.")
                break

        line = ser.readline().decode("utf-8", "ignore").strip()
        if not line:
            continue

        if line.startswith("# LOG"):
            logging.info("DEVICE: %s", line[5:].strip())
            continue

        if line.startswith("#"):
            logging.warning("DEVICE: %s", line[1:].strip())
            continue

        if line.startswith("BEGIN_TRACE"):
            m = BEGIN_RE.match(line)
            if not m:
                logging.error("Malformed BEGIN_TRACE line: %r", line)
                continue

            sensor, midi, note, pol, thr_on, thr_off = m.groups()
            meta = {
                "sensor": int(sensor),
                "midi": None if midi == "None" else int(midi),
                "note": note,
                "polarity": pol,
                "thr_on": int(thr_on),
                "thr_off": int(thr_off),
            }
            logging.info(
                "BEGIN_TRACE: sensor=%s note=%s midi=%s pol=%s on=%s off=%s",
                meta["sensor"], meta["note"], str(meta["midi"]),
                meta["polarity"], meta["thr_on"], meta["thr_off"]
            )
            ts.clear()
            vs.clear()
            started = True
            begin_seen_at = time.time()
            continue

        if line == END_MARK:
            if not started:
                logging.warning("END_TRACE received before BEGIN_TRACE; ignoring")
                continue
            logging.info("END_TRACE received. Samples: %d", len(ts))
            break

        if started:
            try:
                t_str, v_str = line.split(",", 1)
                if "." in t_str or "e" in t_str or "E" in t_str:
                    t_val = float(t_str)
                    if ts_are_seconds is None:
                        ts_are_seconds = True
                else:
                    if ts_are_seconds:
                        t_val = float(t_str)
                    else:
                        t_val = int(t_str)
                        if ts_are_seconds is None:
                            ts_are_seconds = False
                ts.append(t_val)
                vs.append(int(v_str))
            except Exception:
                logging.debug("Skipping malformed data line: %r", line)
            continue

        logging.debug("DEVICE(outside-trace): %s", line)

    return meta, ts, vs, ts_are_seconds
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

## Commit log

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2026-08-12 Add architecture plans: native dual-core firmware (Plan 1) + RS-422 mesh hardware rev (Plan 2)
    Plan 1 (executed now): bare-metal C/Pico SDK firmware for current RS-485
    hardware — core 1 pipelined TLA2518 scan (>=1 kHz target), core 0 comms,
    master-polled bus eliminating event-push collisions, us velocity timebase,
    unified image with role-by-capability-probe.
    Plan 2 (paper only): next board revision with full-duplex RS-422
    left/right neighbor links, hop-count enumeration, per-hop GBN + credit
    flow control, endpoint node outside the instrument.
2026-08-12 Add native dual-core C firmware (Pico SDK) for current RS-485 hardware
    One copy-to-RAM UF2 for every board; role chosen at boot by TLA2518
    capability probe (sensor node vs bus-master/bridge).
    - core1: pipelined TLA2518 scan (3 runtime modes: sequential parity,
    parallel settle-overlap, two-phase crosstalk fallback) + event engine
    ported from photon_sensorscan with microsecond dt timebase
    - ipc: SPSC event ring, seqlock sweep snapshot, command mailbox with
    PARK handshake for flash commits
    - comms: frame v2 (header-covering CRC32 + CRC8 O(n) resync),
    bridge-mastered EVT_POLL cycle eliminating bus collisions, DMA TX/RX
    UART driver behind a transport seam for the future RS-422 mesh
    - u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
    [board_config.h]
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2026-08-12 Apply code-review fixes: protocol races, bounds clamps, legacy parity, USB-only servicing
    Correctness:
    - poll retries resend the identical batch (caps peek at pending count),
    closing an ack/release race that could drop events grown into a retry
    - bulk request FIFO + first-alive cycle detection: fixes dispatch deadlock
    when node id 6 is alive, and 'cal save' now reaches every node
    - clamp all wire-supplied counts in console response handlers (stack
    overflow via malformed DATA/MINMAX/TRACE frames)
    - broadcast frames are never answered (no all-nodes bus contention) and
    broadcast CAL_COMMIT no longer parks every node in flash writes at once
    - per-node note tracking + node-down release: n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
    [board_config.h, main.c]
2026-08-12 Address external review: safe role probe, ack-after-validate, reboot epochs
    P1 fixes:
    - TLA2518 probe no longer drives pins that are hazardous on the main
    controller board (GPIO1 = host RS-485 DE, GPIO5 = host UART RX): the six
    banks with benign CS pins are probed first, and GPIO1/GPIO5 are touched
    only after a safe bank answers (proof of sensor-board identity)
    - bridge validates EVT_BATCH structure BEFORE recording the ack, so a
    CRC-valid malformed batch can no longer release unprocessed node events
    - per-boot epoch byte in every batch: a fast node reboot (event seq
    restart while still marked alive) resets bridge seq tracking instead of
    discarding real events as stale duplicates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
    [rs485_bus.c]
2026-08-12 Add bench smoke-test tool (proven against main controller board)
    First hardware validation of the native firmware passed on the main
    controller board: role probe -> bridge, discovery PINGs on the bus at
    250 ms, USB composite enumerates as PHOTON Node (1B4F:0039), flashtest
    survives 10 erase/program cycles, console reboot re-enumerates in ~4 s.
    [smoke.py]
2026-08-12 Fix bus-B probe contention found on hardware: probe bus A first
    Power-on pull-downs hold banks 4/6 (CS on GPIO1/GPIO5, the pins that are
    hazardous on the main controller board) SELECTED while untouched, so
    probing any other bus-B bank first read garbage through MISO contention
    and marked banks 5/7 absent. Stage 1 now probes bus A only (no shared
    bus with the hazardous pins); a response proves sensor-board identity,
    then all four bus-B CS lines are raised before bus B is probed.
    Bench result on sensor board 002: all 8 banks probe, 31/31 sensors live,
    585 us full sweep (1709 Hz) vs 152 Hz on the same board under
    CircuitPython minutes earlier.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
    [tla2518.c]
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2026-08-12 Add paced scan rate (default 400 Hz, 'rate <hz>|max', persisted)
    Absolute-schedule pacing on core 1: sweeps start on a fixed period grid
    (no drift, overruns resync), emitters dark for the whole idle gap (~24%
    duty at 400 Hz vs unthrottled ~1.7 kHz). Rate stored in former config
    padding so existing saved calibrations remain valid; STATS/table/
    heartbeat report true period-based rate alongside active scan time.
    Bench: 400.0 Hz on the wire after reflash with cal v1 still frozen;
    194/194 events->MIDI during the preceding unthrottled session.
    [board_config.h, main.c, scan.c]
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2026-08-12 Fix unsigned press underflow with frozen calibration (false-note storm)
    With learning frozen, thermal/duty drift can move the idle level below
    the stored min (board 1: calibrated unthrottled at 1690 Hz, run at
    400 Hz -> cooler/brighter emitters -> idle ~100-300 counts under min).
    press = value - min then underflowed to ~4e9, firing vel-127/dt-0 note
    storms on every sensor at or below its min. Clamp press to 0..range
    (both polarities); below-min now reads as fully released. Host
    regression test reproduces the storm signature.
    Field rule this encodes: calibrate at the operating scan rate.
2026-08-12 Fix RP2350 UART pin mux for sensor boards: GPIO22/23 need F11 UART_AUX
    GPIO_FUNC_UART (F2) is TX/RX only on pins 4k+0/4k+1; on 4k+2/4k+3 F2 is
    CTS/RTS and TX/RX live on F11 UART_AUX. The bridge (GPIO4/5) worked; both
    sensor nodes (GPIO22/23) were deaf and mute on the bus. CircuitPython's
    port applied F11 internally, masking this until first native bus contact.
    Bench: node 1 discovered within seconds of reflash; poll loop at ~2.5k
    cycles/s with zero CRC errors.
    [rs485_bus.c]
2026-08-12 Add pseudorandom load generator for bus loss validation ('test <evps>')
    Core-1 xorshift generator injects synthetic events at a configured rate
    with stateful ON/OFF pairing (no stuck notes); per-event sequence
    accounting at the bridge (gaps/malformed/dup counters in 'nodes') is the
    loss detector. Bridge console 'test <evps> [id]' drives it over the bus
    via TEST_BURST kind=1; 'test stop' releases all held synthetic keys.
    [scan.c]
2026-08-12 Gate node local delivery on !tud_suspended: pulled cable is suspend, not unmount
    Bench: with board 2's USB cable removed mid-test, tud_midi_mounted()
    stayed true and 500 ev/s kept draining into the dead port while the bus
    carried empty batches (1.5M frames, 0 CRC errors, all nodes alive — the
    bus itself was flawless). Local delivery now requires mounted AND not
    suspended, so cable removal reroutes events to the bridge within ms.
    [main.c]
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2026-08-12 Broadcasts own the wire: quiet window instead of immediate next poll
    Bench-diagnosed: a dispatched broadcast was followed in the same B_IDLE
    pass by the next EVT_POLL, so the broadcast transmitted exactly into
    that poll's reply window — colliding on the half-duplex bus, and the
    replying node (receiver off while driving) could never hear it. Both
    nodes ignored every broadcast while all addressed traffic was perfect.
    Broadcast dispatch now enters a deadline-cleared B_BULK_WAIT like
    addressed requests, so the frame gets a silent bus.
2026-08-12 RS-485 tuned: 4 Mbaud, 8 us DE guards, 700 us poll timeout
    Bench campaign, one parameter per step, rates from counter deltas over
    timed windows (tools/measure.py):
    baseline 2M/25us/1500us : 2004 polls/s/node
    4M : 2932 polls/s/node; accidental 21-min soak:
    246k events, 7.2M frames, crc=0 gaps=0 dup=0
    4M/8us : 3677 polls/s/node
    4M/8us/700us : 3694 polls/s/node (timeout only trims fault
    stalls, happy path unchanged as expected)
    margin : 250 ev/s/node sustained, zero loss, poll
    rate -2% under load
    tools/flash_all.sh: hands-free bootsel+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
    [board_config.h, measure.py]
2026-08-12 Plan 2 doc: note missing failsafe bias on current rev, bias guidance for RS-422
    Current RS-485 hardware has no pull-up/pull-down bias network; the
    THVD1424's internal receiver failsafe is what keeps the idle bus quiet
    (bench-proven at 4 Mbaud, zero hdr/crc errors). Next rev should add the
    standard bias network on any pair that can be left undriven.
2026-08-12 Four-board / two-manual support: per-manual channel map, global masks
    Deployment shape (single vs double manual) is now pure runtime config on
    one UF2: whichever nodes answer discovery play, and the bridge maps each
    manual (board pair) to a user-facing MIDI channel.
    - config: manual_channel[] appended (0 = legacy auto base+manual).
    sector_valid() migrates pre-existing shorter sectors so node id and
    calibration survive the upgrade (verified on both bench boards).
    - chmap console command: print or set the manual->channel table, saved.
    - disable/enable on the bridge now mask GLOBAL sensor indices (remote
    unpopulated slots); node form still masks local sensors.
    - defaults: the 61-key pair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
    [board_config.h]
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2026-08-13 Review pass for merge: 5 bug fixes, dead code removal, docs to final-product
    Eight-angle review with adversarial verification before merging to main.
    Fixed:
    - Ack sentinel 0xFFFF could collide with a real poll seq once per 65,536
    transactions, letting a node discard an unacked event batch: the bridge
    seq counter now skips the sentinel value.
    - Clearing a sounding sensor (disable, cal reset, degenerate range) never
    emitted its note-OFF: clear_sensor_state now synthesizes the OFF.
    - config_store_save snapshotted live min/max even in learning mode, so
    'setid' before calibration persisted ambient noise as calibration and
    the board booted silently dead: snapshot now only when frozen, c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
    [board_config.h]
2026-08-16 Per-node cal targeting: 'cal reset [id]' / 'cal save [id]' from the bridge
    A single miscalibrated board can now be redone over the bus without
    wiping calibrations that are already good (broadcast remains the
    default when no id is given). Written during the board-4 power
    debugging, where the only alternative was recalibrating all 122 keys.
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2026-08-16 Power savings: bridge poll pacing, remote node control, emitter skip
    Phase A (bridge-only, no node access needed):
    - PHOTON_POLL_CYCLE_US (1000) paces the poll rotation instead of letting
    it free-run at ~1850/s, roughly halving the bridge's RS-485 transmitter
    duty. Implemented as a guard in B_IDLE, not a sleep: the main loop keeps
    spinning, and bulk/ping dispatch stays outside the guard so console
    traffic and discovery never wait on the idle window. Absolute-grid
    scheduling with resync if the bridge falls a full period behind.
    0 restores free-running behavior.
    Phase B (node firmware; makes every knob settable over the bus):
    - PHOTON_FT_NODECTL ('Z', payload op u8 | arg u16): rem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
    [board_config.h, scan.c]
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2026-08-16 Runtime emitter-settle knob for bench A/B ('settle <us> [id]')
    PHOTON_SETTLE_US (60) dominates emitter on-time (~79% of the ~76 us a
    sensor's LED is lit) and sets the sequential-mode scan ceiling (~394 Hz).
    It was inherited from the CircuitPython build and never re-validated
    against the actual VCNT2025X01 response, so make it testable without a
    rebuild-and-reflash per data point.
    g_scan_ctl.settle_us is a runtime value (default PHOTON_SETTLE_US),
    settable locally or over the bus via NODECTL op 5. Deliberately NOT
    persisted: a too-short value would survive a reboot and quietly degrade
    every reading, so a power cycle always restores the compile-time default.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
    [scan.c]
2026-08-16 Emitter settle 60 -> 30 us (bench-measured)
    Drift-controlled 60->10->60 us sweep on board 4 (round-trip returned to
    99.96%/99.97%, so no drift): the VCNT2025X01 response is complete well
    before 10 us and then DECAYS during a long pulse, so shorter settle gives
    MORE signal, not less - +1.3% at 30 us, +6.5% at 10 us, with noise
    essentially unchanged at 30 us. Per-sensor spread is large (one sensor
    flat, another +23%), so the value is chosen conservatively.
    30 us keeps sampling on the flat part of the curve (~96 counts/us vs
    ~315 below 15 us, where timing jitter would become noise) and shortens
    the sequential sweep 2533 -> ~1574 us, moving the scan ceiling from
    ~394 to ~630 Hz. Requires recali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
    [board_config.h]
2026-08-16 Emitter settle 30 -> 50 us
    The 30 us figure was measured on a board that was DISASSEMBLED with keys
    missing - its sensors were staring at nothing, which is not a
    representative optical condition, and that experiment wrongly showed
    shorter settle giving more signal. Re-measured with keys installed: 45 us
    reads 81-91% of 60 us across all four boards, so the response is still
    developing well past 30 us and short settle costs real signal.
    50 us stays close to the long-proven 60 us while shortening the
    sequential sweep (~2533 -> ~2213 us). Requires recalibration.
    [board_config.h]
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2026-08-16 Fix sequential-mode channel-select ordering (PENDING HARDWARE VALIDATION)
    sweep_sequential settled first and wrote CHANNEL_SEL immediately before
    reading, giving the ADC mux zero on-channel settling time — unlike
    step_banks (parallel/two-phase), which writes CHANNEL_SEL under the
    settle window. On real hardware this produced elevated readings on
    slots 1-3 and pinned bank 7 slot 0 (sensor 28) at a noisy mid-rail
    ~32k: bank 7's mux parks on the floating unpopulated AIN1 (idx 31)
    through the inter-sweep idle and drifts to mid-scale.
    Reordered to LED on -> CHANNEL_SEL -> settle -> read, matching the two
    modes proven on hardware. Mode 0 stays quarantined from production
    until the A/B validatio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
    [scan.c]
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2026-08-24 One UF2 for both RP2350 (16 MB) and RP2354 (2 MB) boards
    The image is ~86 kB, so flash capacity was never the issue - the only
    size-dependent item was the config store, which anchors to the top of
    flash. Building for 16 MB put it at 0x0FFE000, an address that does not
    exist on a 2 MB part.
    Build for the SMALLER part instead: PICO_FLASH_SIZE_BYTES = 2 MB puts
    the config at 0x01FE000, which is a valid address on both. config_store
    additionally reads the old 16 MB location when the primary sectors are
    blank, so boards previously flashed with a 16 MB build keep their node
    id and calibration; the next save relocates them. That legacy read is
    harmless on a 2 MB device - the address is inside the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
    [board_config.h]
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2026-08-27 002 sensor board: 5V bus rework, library consolidation, DRC pass
    Board (002):
    - Remove SS14 bridging diode; USB-C VBUS and JST V+ are now one net.
    Worst case is back-powering a host's VBUS, acceptable in a uniform
    5V fleet, and it drops 185mW in the bridging case.
    - Remove the 8x 47k CS pull-ups. At 47k they parked the TLA2518 CS
    inputs mid-rail (1.7-2.1V, between VIL 0.99 and VIH 2.31); the
    internal pull-down now defines them cleanly low. Firmware must drive
    CS high before configuring SPI.
    - 5V pour along the bottom edge, 3.3V moved up to the mounting rail.
    - USB-C relocated; ~200mm D+/D- run on F.Cu over the B.Cu GND pour.
    - Screw-head keepouts on all mounting holes.
    - Board grow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
    [002_Sensor_PI_RS485 board.kicad_pcb, 002_Sensor_PI_RS485 board.kicad_sch, 4_Sensor_Bank.kicad_sch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]
2026-08-28 002: ERC/DRC to zero, symbol and value cleanup
    Schematic (ERC 24 -> 0):
    - VCNT2020 renamed to VCNT2025X01, matching the part actually fitted.
    Pin types preserved: passive / open_collector / passive / passive.
    The old auto-generated VCNT2025X01 symbol (all pins Unspecified) is gone.
    - THVD1424RGTR: 10 pins off Unspecified (R, RE, DE, D, TERM_TX, TERM_RX,
    Y, Z, VIO, H/F). VIO was typed as a signal despite being a supply pin.
    - TLA2518IRTER: DECAP -> Passive, clearing 8 warnings at once.
    - PWR_FLAG moved off J3's VBUS (which J3 already drives as a Power output)
    onto GND, which had none. One move, two errors.
    - JP1/JP2/JP4 repointed to stock Jumper:SolderJumper_2_Open. The project
    copy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
    [002_Sensor_PI_RS485 board.kicad_pcb, 002_Sensor_PI_RS485 board.kicad_sch, 4_Sensor_Bank.kicad_sch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]
2026-08-28 002 sensor board: Rev B ordered; rename folder, add schematic PDF
    Board is at zero ERC and zero DRC and has shipped to fab as Rev B
    (RS-485, 5 V bus). This commit captures exactly what was ordered.
    - Rename 002_sensor_board_example -> 002_sensor_board. It stopped being
    an example some time ago.
    - Add Schematic_revB.pdf.
    - Replace the Rev A production outputs with the Rev B set actually sent:
    gerbers/drill zip, BOM, positions, designators, IPC netlist.
    The BOM now carries LCSC part numbers for every specialty part, which
    none of the previous exports did - VCNT2025X01 (C7431257) and
    THVD1424RGTR (C5359161) in particular had only ever been matched in
    JLC's web UI at order time, so they su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
    [002_Sensor_PI_RS485 board.kicad_pcb, 002_Sensor_PI_RS485 board.kicad_sch, 4_Sensor_Bank.kicad_sch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]
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2026-08-28 Consolidate footprints into a single shared library
    All three boards carried their own copies of the same footprints - 79
    files across 11 project libraries for 37 distinct footprints. Several
    existed three times over (RP2350-QFN-60 ThermalVias, edge_holes,
    TO-236_VIS-L, SON_NT2020_VIS, L_pol_2016, USB_Micro-B). Three copies
    drift, and this project has already been bitten twice by a library and
    a board disagreeing.
    - New hardware/kicad/common.pretty holds all 37, verified byte-identical
    where they were duplicated: zero name collisions with differing
    content, so nothing had to be reconciled.
    - Each board's fp-lib-table is now a single "common" entry. Previously
    001 alone had eight, and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
    [002_Sensor_PI_RS485 board.kicad_pcb, 002_Sensor_PI_RS485 board.kicad_sch, 4_Sensor_Bank.kicad_sch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]
2026-08-28 Rename shared footprint library common -> photon_common
    'common' is too generic for a library nickname - it can collide with a
    global library or another project's table, and it doesn't identify whose
    footprints these are.
    155 lib_ids rewritten across the three boards plus all three
    fp-lib-tables. All 459 footprint references still resolve.
    [002_Sensor_PI_RS485 board.kicad_pcb, 002_Sensor_PI_RS485 board.kicad_sch, 4_Sensor_Bank.kicad_sch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]
2026-08-30 Consolidate symbol libraries, normalise BOM data, Rev B for all three boards
    Libraries
    - Move PHOTON and PHOTON_Modified to hardware/kicad/, shared by all three
    projects, replacing six divergent per-project copies. 002's versions taken
    as canonical (correct pin electrical types); 001-only parts recovered from
    the schematic cache. All 459 footprint and 464 symbol refs resolve.
    - Repoint every sym-lib-table at the shared files. Nicknames unchanged, so
    002 and 001d needed no lib_id edits; only 001's stale date-named ones.
    - Fix stale footprint nicknames inside the symbol libraries (footprints:,
    RP2350_60QFN_minimal:, APS6404L-3SQR-ZR:) that would have made newly
    placed parts land wi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
    [002_Sensor_PI_RS485 board.kicad_sch, 4_Sensor_Bank.kicad_sch, Indiv_sensor.kicad_sch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]
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2026-08-30 Docs: velocity range takes a one-time config reset; reframe mode 0
    Appending vel_out_min/vel_out_max to photon_config_t lengthens the record and
    invalidates every board's stored config. The plan previously called for a
    table of historical record sizes plus a host test to migrate across it; that
    is permanent complexity bought to avoid one afternoon of reconfiguration.
    Take the reset instead, and drop the existing migration fallback while we are
    there.
    Two clarifications that make the reset cheap: erasing the config sectors
    first is a no-op (a stale record fails CRC and loads defaults, same as an
    erased one), and reflashing was never the hazard since config lives above the
    program region. Cal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
    [scan.c]
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2026-09-02 Fix the slot-3 emitter drive and the SPI bus speed; keep config across reflashes; log velocity curve
    Two firmware fixes found on the bench:
    - TLA2518 GPIO0 (the slot-3 emitter of every bank) drives high in push-pull
    mode regardless of GPO_VALUE, on every part fitted, so seven emitters per
    board had been on continuously since bring-up. Switch that pin through
    GPO_DRIVE_CFG instead (push-pull = on, open-drain = off).
    - SPI bus speed is now 10 MHz, the validated rate: at higher speeds the ADC
    nearest the MCU lost register writes in the two-phase frame sequence.
    Also:
    - Config store accepts records written by older builds (append-only layout,
    prefix CRC scan) and rewrites them once,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
    [velocity-strikes-2026-09-02.tsv]
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2026-09-02 Inductor silkscreen fix
    [002_Sensor_PI_RS485 board.kicad_pcb, 002_Sensor_PI_RS485 board.kicad_sch, 4_Sensor_Bank.kicad_sch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]
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2026-09-07 Build id in the banner; retire software/; README pass; config store trim
    - The firmware names its build. cmake/build_id.cmake regenerates
    build/generated/build_id.h on every build with the git short hash
    ("-dirty" when firmware/ has uncommitted changes) and the build time.
    The console banner and `id` print it, and picotool binary info carries
    it as version / build date next to the repository URL and
    klavecimbel.com. No personal address goes into the image or the repo.
    - software/ is gone: only the native firmware is current. The retired
    CircuitPython stack stays reachable at the last_circuitpython tag. The
    one live host tool it held, the trace plotter that the firmware's
    `tra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
    [board_config.h, listen_for_single_sensor_high_res.py]
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2026-09-24 Knee calibration: a strike threshold per key, at its pluck
    A fixed 60% strike threshold sits at a different place relative to each
    key's pluck: against a recorded MIDI+audio corpus it fired 8-60 ms early on
    slow presses, with a different offset per key. Calibration now captures
    every key's swing and finds the knee where the plectrum lets go (the key
    snaps down), and saves a strike threshold per key just above it.
    - core1/calcap: per-key swing capture while learning, with pre-roll; any
    number of non-adjacent keys at once. A swing ends once the key is back
    within a fifth of its depth; that level becomes its rest.
    - cal/knee: knee detection, tuned on real upper-manual swings (the snap
    bu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
    [board_config.h, main.c]
2026-09-24 microSD: SETUP.TXT next to each power-on's recordings
    The bridge reads every board's calibration table (the pages 'cal compare'
    shows) three seconds after power-on, adds its own build, serial, channel
    map and velocity settings, and the recorder saves the text as
    NNNN/SETUP.TXT once the power-on's directory exists. Once per power-on:
    a change made later shows in the next power-on's file.
    - Bridge only: the sensor boards already answer CAL_INFO requests.
    - Own file handle, opened and closed in one go: a failed write costs only
    SETUP.TXT, is not retried, and never touches the recording.
    - 'sd' shows where it went; a connected terminal gets
    "[SD] saved NNNN/SETUP.TXT".
    - Host tests: the tex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
    [main.c]
2026-09-24 tools: console_client.py sends each key as it is typed
    nc holds a line until Enter and echoes it locally, so the calibration view
    (redrawn four times a second) painted over what was being typed. The new
    client puts the terminal in cbreak mode: every key goes straight to the
    board, which echoes it and redraws the typed line under the keyboard.
    The broker's usage now points at it; nc still works.
    [console_broker.py]
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
